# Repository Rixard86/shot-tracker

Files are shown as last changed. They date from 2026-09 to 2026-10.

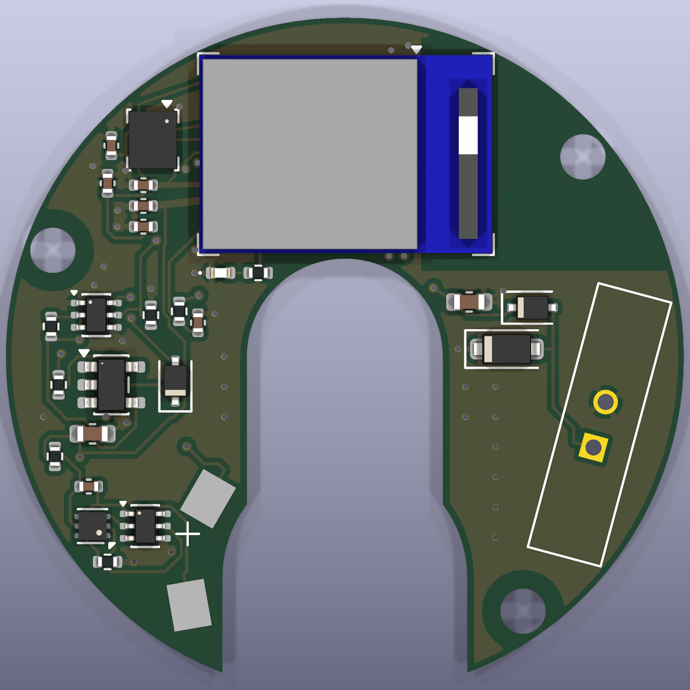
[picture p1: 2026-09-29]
hardware/kicad/shotpuck_pcb_top.png

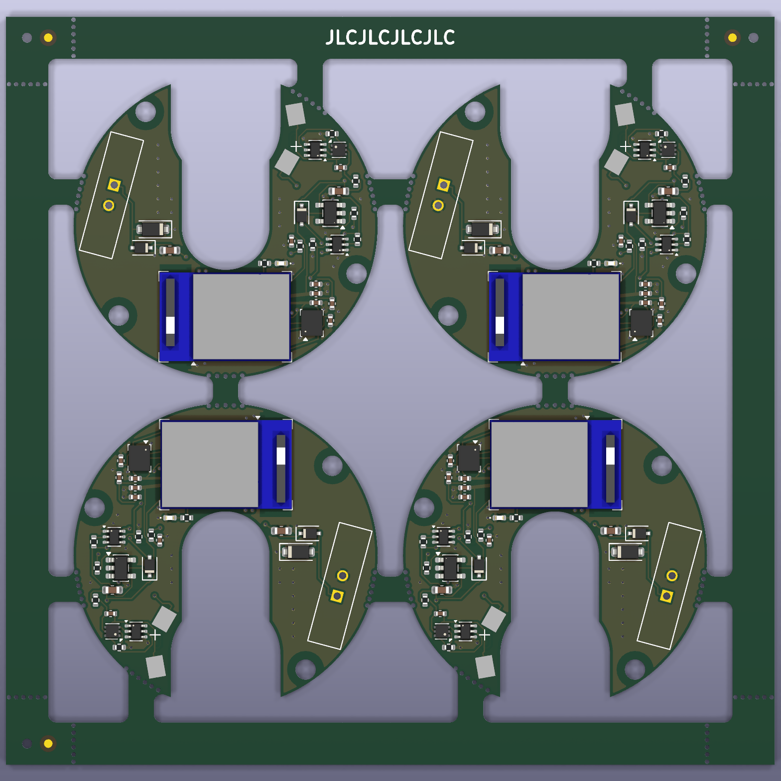
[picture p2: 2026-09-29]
hardware/kicad/panel/panel-top.png

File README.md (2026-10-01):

# ShotPuck: automatic arrow counter for Avalon barebow riser weights

A Ø40 × 10.4 mm puck that bolts onto the free face of an Avalon riser weight (the weight's own 5/16-24 bolt, one size longer, goes through its centre), detects each shot with a 6-axis IMU, records the bow's motion around it (accelerometer + gyroscope, 1.0 s before to 0.5 s after release), and reports both over BLE to the scoring app.

| | |
|---|---|
| Size / mass | Ø40 mm (= the Avalon barebow weight's diameter), 10.43 mm above the weight face (2.0 mm flat aluminium plate; the 1.2 mm PCB on 3 mm standoffs, the cell in a notch in the PCB), 16.7 g, centre of mass 0.5 mm off axis (no trim weight); 1.6 mm free space above the cell |
| Radio / MCU | u-blox BMD-340 (nRF52840, 1 MB flash / 256 KB RAM, PCB antenna), BLE 5 |
| Sensor | ST LSM6DSO32X IMU (LSM6DSO32 plus an unused machine-learning core): 416 Hz, ±32 g accelerometer + ±2000 dps gyroscope while active; accelerometer only, 12.5 Hz wake-on-motion, while idle |
| Battery | LIR1254 Li-ion coin, 45–65 mAh, plain (no tabs) on spring contacts, protected by TI BQ29700 + DMN2004DWK; charged through a waterproof (IPX8) side-entry USB-C port, power only (21 mA, temperature-gated) |
| Firmware | Zephyr 4.1, custom board `shotpuck/nrf52840`, MCUboot 28 KB + signed app 196 KB (452 KB slot) / 88 KB RAM (44 KB of it capture buffers) |
| Updates | Over the air: MCUboot with ECDSA-P256 signed images and automatic rollback, MCUmgr/SMP over BLE for paired phones, 10 s watchdog |
| Security / sync | Pairing required (LE Secure Connections); new phones only within 60 s of attaching the charger. Last ~900 shots kept in flash for replay. |

## Repository

```
layout.json                 shared geometry: CAD and PCB both read it
firmware/                   Zephyr app (src/, boards/shotpuck/, prj.conf, debug.conf)
firmware/sim/               Monte Carlo validation of src/shot_detect.c, unit tests of capture.c, evlog.c, chg_led.c and recovery.c (+ results.txt)
firmware/VERSION            firmware version (signed into the OTA image, shown in DIS and STATUS)
firmware/sysbuild.*         MCUboot + signing setup (refuses MCUboot's public dev key)
firmware/shotpuck_full.hex  MCUboot + signed app, for the first flash via the SWD test pads
firmware/shotpuck_update.bin  signed app image for OTA updates
hardware/design.py          the circuit (single source of truth)
hardware/gen_sch.py         -> kicad/shotpuck.kicad_sch
hardware/check_netlist.py   KiCad netlist vs design.py
hardware/gen_pcb.py         -> kicad/shotpuck.kicad_pcb (place, keep-outs, route, DRC)
hardware/board_shape.py     board outline, cell notch, bolt hole and antenna zone (shapely, from layout.json)
hardware/islands.py         post-fill GND island bridging used by gen_pcb.py
hardware/gen_bom.py         -> kicad/fab/shotpuck-bom.csv
hardware/gen_panel.py       -> kicad/panel/shotpuck-panel.kicad_pcb (2x2 KiKit panel for JLCPCB)
hardware/gen_jlc.py         -> kicad/fab/jlc/ (JLCPCB assembly BOM + CPL with LCSC part numbers, rotated/shifted to JLC's footprints)
hardware/bmd340.py          u-blox BMD-340 footprint, 3D model placement and schematic symbol (from its data sheet)
hardware/kicad/             KiCad project, ShotPuck.pretty/.kicad_sym/.3dshapes, schematic PDF, fab/ (gerbers, drill, pos, BOM)
mechanical/puck.py          CadQuery model + mass/balance -> out/ (STEP, STL, mass_report.txt);
                            geometry.py, puck_parts.py, puck_report.py hold its constants, parts and output
mechanical/plate_drawing.py plate manufacturing drawing (hole table, M2 thread callout) -> out/plate_drawing.pdf;
                            5052 sheet-metal prototype variant -> out/plate_drawing_5052.pdf + out/plate_5052.step
mechanical/blender/         Blender scene + exploded-view assembly animation -> out/shotpuck_assembly.mp4/.blend
docs/PROTOCOL.md            BLE GATT protocol for the app
docs/VALIDATION.md          what is proven, and the on-device checklist
order/                      order packages for JLC (PCB + assembly, plate, cap), each with an ORDER.md:
                            form settings, notes for the order and the checks against JLC's rules
```

## Decisions (change any, then re-run the generators)

| # | Decision | Why | Alternative |
|---|---|---|---|
| D1 | **Cell beside the module, no trim weight** | Module at the upper right, bolt in the middle, cell in a notch at the bottom. The centre of mass is 0.5 mm off axis (≈ 0.01 mm on a 2 kg bow); Richard dropped the optional brass pin when the PCB went up on standoffs | Two LIR1254 side by side (studied: they cut the board in two); a brass trim pin |
| D2 | **Flat 6061 plate (2.0 mm) + polycarbonate cap, bolted on through a steel sleeve** | Richard: the v0.2 stud could not be fitted to the bow (it needs a bolt from above), and a flat plate is cheaper (laser or waterjet, no turning). The sleeve carries the bolt's clamp load to the plate; on the prototype the PC cap top sits between the bolt's washer and the sleeve (D21) | Turned 7075 base with an integral stud (v0.2) |
| D3 | **nRF52840 in high-voltage mode** (cell → VDDH, REG0 = 3.0 V) | No regulator, no battery divider (internal VDDH/5), fewer leaks | External LDO |
| D4 | **MCP73831 + firmware temperature gate** (nRF die temperature, <1 °C / >44 °C) | MCP73831 programs down to 15 mA; the TS-pin chargers found start at 100 mA. Default is *charging allowed* if the MCU is dead, so a flat cell always recovers. | Charger with an NTC input and a thermistor at the cell |
| D5 | **32 kHz from internal RC, REG0/REG1 in LDO mode** | The BMD-340 has no 32.768 kHz crystal; LDO is the tested default | Enable DC/DC on REG0/REG1 (the BMD-340 has the inductors; about half the radio current) |
| D6 | **Plain LIR1254 (no tabs) on contacts:** a + spring against the can side and a − strap over the top cap, soldered to two SMD pads left of the notch; the cap's foam pad clamps the cell and the strap | Richard's choice: no tab variant to source, no soldering on the cell, swappable | Tabbed LIR1254 soldered to pads; 601015 pouch (closed-ring board, ~9.9 mm) |
| D7 | **Pairing required; new pairings only within 60 s of attaching the charger** (LE Secure Connections Just Works, up to 4 phones, FORGET_BONDS to reset) | Several pucks and shooters at one club: other apps must not read, reconfigure or reset your puck. The charger gesture proves physical possession. | Open access (v1), or a PIN shown by LED blinks |
| D8 | **Detector thresholds are defaults, tunable over BLE**; every candidate is reported | Real release-shock data is unknown until you shoot | – |
| D9 | IMU rotated 270°, reference designators on F.Fab only | Routability; board too dense for silkscreen text | – |
| D10 | **LSM6DSO32 IMU** replaces the LIS2DE12 accelerometer. Pinout, pin states and register values checked against datasheet DocID032891 Rev 1; I3C disabled at init as the datasheet recommends. Since 2026-09-30 the BOM fits the **LSM6DSO32XTR** (C3663738) for JLC stock: the same chip plus a machine-learning core we leave off, same package, pinout, WHO_AM_I and registers, and a pad-for-pad identical JLC footprint, so the board and firmware are unchanged | Gyroscope for bow rotation; ±32 g clips the release shock less; 16-bit data; same I2C bus and INT1 pin | LSM6DSV16X/32X (on-chip sensor fusion, ±4000 dps) |
| D11 | **Raw 6-axis capture per accepted shot** (−1.0 s to +0.5 s, 624 samples, 7.5 KB), analysed in the app | Which bow-movement metrics matter is unknown until real shots are recorded | On-device metrics (cant, steadiness, post-release rotation) in the EVENT |
| D12 | **Identity from the chip's factory ID**: name `ShotPuck-XXXX`, DIS serial number = `device_id` | Tell pucks apart at a club; one stable ID across phones for PowerSync | App-assigned IDs |
| D13 | **Accepted shots in a 32 KB flash ring** (~900 shots), rejected candidates in RAM; app-driven REPLAY, sent paced in the background | Shots survive dropouts and resets without per-phone sync state on the puck | Device push with ACK (rejected: shared state, first phone drains the backlog); captures in flash too |
| D14 | **u-blox BMD-340-A-R (nRF52840) instead of the Raytac MDBT50Q-1MV2**: 15.0 × 10.2 × 1.9 mm LGA-68, PCB antenna, VCCH input for high-voltage mode, FCC/CE/Bluetooth certified. Footprint `ShotPuck:u-blox_BMD-340` from data sheet UBX-19033353 (Figure 12), checked pad for pad against two built open-source footprints | Richard: replace parts JLCPCB does not stock. On 2026-09-29 JLCPCB had 0 MDBT50Q-1MV2 and 227–393 BMD-340 (C5456944, $8.73 vs $18.93). nRF52840 kept for the two OTA slots (2 × 460 KB). **Only type BMD-340-A-R-10 is usable:** -00 (nRF52840 rev 1) has a non-functional high-voltage mode, so confirm the type with JLCPCB before ordering | MDBT50Q-1MV2 via global sourcing or consignment; u-blox NINA-B306 ($20, 59 in stock) |
| D16 | **Cell protection (PCM): TI BQ29700 + Diodes DMN2004DWK** in the cell's negative lead (OVP 4.275 V, UVP 2.80 V, ±0.1 A over-current, short-circuit) | LIR cells have no protection of their own; kept from the CP1654 design (BQ29700 was on Varta's list). Costs 4 µA standby | – |
| D17 | **1.6 mm free space above the cell** (7.0 mm from the Kapton to the ceiling) | No swell spec for LIR cells. It was 1.2 mm (set on the magnetic board so its connector was flush with the cap top, D25) until the PCB went to 1.2 mm (D30): the ceiling rose 0.4 mm with the board, so the free space is now above Varta's 1.5 mm. The foam pad fills it | 1.2 mm with 2.6 mm standoffs (non-stock) |
| D19 | **Board Ø36 mm; 4× M2×8 cheese head (Torx) screws from above, all at r = 16.5 mm: H1 100.6°, H2 164.5°, H3 305°, H4 226°**, through the cap, PCB and standoffs into the tapped plate | Puck Ø40 mm is fixed by the Avalon weight; 36 leaves 0.5 mm fit clearance. The screws sit clear of the module, the cell notch and the port. H1 and H2 sit either side of the USB-C port, far enough apart that the ground pour reaches J1's wing tabs; H4 holds the left arm (D29). The 1.3 mm head lets an M2×8 end 0.1 mm inside the plate (a socket head would need the non-standard M2×7) | – |
| D20 | **Cell in a notch in the PCB, open to the rim** (Ø13.0 mm round end), on the Kapton over the plate | Saves the 0.8 mm board in height. Richard preferred the notch to a closed hole | Closed hole (holds the cell all round, leaves a thin strip at the rim) |
| D18 | **Waterproof (IPX8) side-entry USB-C, SHOU HAN TYPE-C 6PFS 2JCB1.6-H6.7 IPX8** (6-pin, power only, LCSC C3020041, JLC-assembled) at 132.58° on the left rim, recessed in a notch in the board edge, plug axis radial through the cap wall; R10/R11 5.1k pull CC1/CC2 down | Richard (2026-09-30). Any USB-C charger and cable fits, JLC places the part (the magnetic one was hand-soldered), and its own silicone ring seals it in the cap wall. The CC pull-downs make USB-C chargers switch on 5 V | Samzo PR5L4015 magnetic receptacle flush with the cap top (the magnetic board, last at commit `01f2e00`) |
| D15 | **OTA = MCUboot swap-using-move + MCUmgr SMP over BLE**, ECDSA-P256 signed, encrypted link (paired phones) only. A new image runs on trial and confirms itself once a paired phone has connected over an encrypted link and it has run 10 s (so an image that runs but cannot talk BLE rolls back); a 10 s hardware watchdog turns a hang into a reset, and MCUboot then rolls back | Standard Nordic/Zephyr path; the Flutter app can use Nordic's `mcumgr_flutter` | Firmware-loader mode (single slot); no rollback |
| D21 | **One loose steel tube from the plate through the PCB to the underside of the cap top, located by a lip under the cap** (Richard, prototype) carries the bolt load from the cap top to the plate; the PCB hole (Ø10.4: 0.2 mm clearance covers JLCPCB's ±0.2 mm outline tolerance) is merged into the cell notch | Richard: the tube must not get lost while the puck is off the bow. Bonded into the cap and standing 0.1 mm proud, it was held by 1.2 mm of glue that the stack tolerance between cap and plate (±0.15–0.3 mm) and the bolt's squeeze would break at the first bolt-up, and then it could slide out through the top. Trapped between the plate and the cap it cannot fall out and needs no glue. **Known risk, tested on the prototype:** the bolt clamps the 1.33 mm PC cap top onto the tube end. At 3 N·m (~2 kN) that is 80–110 MPa on the tube end, at PC's compressive yield, so the cap top may creep and the bolt lose preload (VALIDATION §2). Everything right of the merged hole is copper-free (D22), so no signal has to cross it. No stock insulating tube fits (glass-epoxy 10 × 8 mm grips a 5/16 bolt, plastics creep), so it is steel, with Kapton tape all round it because it can turn | Tube bonded into the cap, 0.1 mm proud (glue breaks, tube can fall out); turned sleeve with a collar in a recess under the cap top (steel-only clamp path, custom part); tube bonded into the plate; sleeve on the PCB with a spacer below (PCB in the clamp path) |
| D22 | **On-board PCB antenna** (BMD-340), module at the upper right with its antenna end pointing 45° below +x; the antenna zone (from 4.4 mm inside the module's end) and everything right of the tube are copper-free (`board_shape.rf_keepout`) | Richard's choice over moving the antenna out into the cap. The module slid 45° around the tube so the USB-C port fits on the left | Module with a u.FL connector and an antenna in the cap |
| D23 | **SWD on 4 bottom test pads** (VDD, SWDIO, SWDCLK, GND, 2.54 mm pitch, under the module) for a pogo-pin jig | Frees top-side space for 2-layer routing; the SWD escape vias are pre-placed | Tag-Connect TC2030-CTX-NL (v0.2) |
| D24 | **I2C on internal pull-ups only; SCL = P0.07, SDA = P0.05** (BMD-340 pads 23 and 21, facing the IMU) | The 4.7k DNP pads (R5/R6) were never fitted and cost routing space; the swap stops the IMU lines crossing on 2 layers | Keep R5/R6 as DNP pads for a stronger pull-up |
| D25 | **PCB on 3 mm standoffs; puck 10.43 mm** | Set on the magnetic board so its connector sat flush with the cap top, and kept. The cap top went from 1.2 to 1.33 mm (2026-09-30, Richard) so 0.80 mm of it is left over the USB-C body, JLC3DP's minimum SLA wall for a ~10 mm feature. The cell sets the ceiling, so the raised board costs no height, and it keeps the antenna 3 mm further from the plate | Board on the plate |
| D26 | **Button head bolt** (5/16-24, head Ø16.7 × 4.4 mm) with a bonded sealing washer | Richard: lower head than a socket head (7.9 mm). The washer clamps the PC cap top onto the sleeve (D21) | Socket head cap screw |
| D27 | **Charge-input protection: SMF5.0CA bidirectional TVS (D3) at the connector + R9 1k / C9 100n in front of the nRF VBUS pin** | The port is exposed (ESD) and plugging in makes and breaks contact (hot-plug spikes); the TVS is bidirectional and sits before D1. The SMF5.0CA starts clamping at 6.4–7.0 V (200 W) against the MCP73831's 7 V absolute maximum. No 5 V TVS can hold the nRF52840 VBUS pin under its 5.8 V absolute maximum; it is used only to detect the charger (~24 µA), so the RC limits current into it and smooths spikes | PESD5V0S1BB (a signal-line ESD diode, clamps only from 5.5–9.5 V); unidirectional flat-clamp TVS after D1 (TI TVS0500); an overvoltage switch (needed only if 9–12 V adapters are a risk) |
| D28 | **Routing aids for 2 layers (BMD-340):** module pins chosen so its second pad column escapes through the outer column's gaps towards the IMU; links and vias locked before Freerouting (`PRE_LINKS`, `PAD_BRIDGES`, `PRE_VIAS` rotated with the module, `PRE_ROUTED` in `gen_pcb.py`) | The LGA module's inner pads need planned escapes. Everything right of the tube is copper-free (D22), so no VIN loop or passage is needed (`VIN_ESCAPE = None`). The board routes with 0 DRC / 0 unconnected; J1's notch and a few fixes are hand edits (Build & flash) | 4 layers |
| D29 | **Shot shock: 4th screw H4 on the left arm; BMD-340 and C2 corner-staked** (Richard) | The slot for the cell and the tube makes the board a horseshoe. Its left arm (PCM, both cell contact pads) had no screw below H2. The model below is of the magnetic board (H1 then at (9.2, 1.2)) and was not re-run for the USB-C layout, whose board is also clamped through rubber O-rings. A plate model of the board (Kirchhoff plate FE, 100 g along the puck axis, component masses, module 1–5× stiffer than the board) gives, at 0.8 mm: first mode 1.1–1.2 kHz → 1.7–2.0 kHz; worst strain 320–340 → 160–180 µε (bare board next to a screw; ≤ 70 µε at any part); the − cell pad moved 13–15 µm against the cell per 100 g, now ~0. At 1.2 mm with 4 screws (the board now, D30): 2.7–3.2 kHz, ~100 µε | Foam pad under the board (damping, no layout change); thicker PCB alone (1.2 mm, 3 screws: 1.7–1.8 kHz) |
| D30 | **PCB 1.2 mm** (was 0.8), stock 3 mm standoffs, puck 0.4 mm taller (10.43 mm) | Richard (2026-09-30): a stiffer board under shot shock (D29: first mode 1.7–2.0 → 2.7–3.2 kHz, strain about halved). Everything on the board rose 0.4 mm, so the cell ceiling (`cell.swell_h` 6.6 → 7.0) and the cap rose with it and every cap, lip and port clearance is unchanged; the tube is 7.1 mm | 0.8 mm board (puck 10.03 mm); 1.2 mm on 2.6 mm standoffs (non-stock) to keep 10.03 mm |

## Needs your input before ordering

1. **USB-C port:** JLC-assembled (C3020041, D18); charge with any 5 V USB-C charger and cable. Ask JLC to confirm the part is in stock for the order.
2. **LIR1254:** buy a plain cell (no tabs) from a maker with a datasheet. Check its charge voltage (ours 4.20 V) and that 21 mA (R1 = 47k) is within its standard charge current (usually 0.5 C).
3. **Cell contacts:** not a bought part yet. For prototypes, form the + spring and the − strap from 0.15 × 2 mm nickel strip (as in the animation) and put Kapton tape where the strap passes the can edge.
4. **Bolt:** a 5/16-24 button head socket cap screw, longer than the original Avalon bolt by the puck height plus the sealing washer (about 12 mm). Check that length is sold in 5/16-24 and the thread engagement in the riser; don't over-tighten (3/16 in hex).
5. **Component masses:** weigh the real parts, put them in `layout.json`, and re-run `puck.py` for the mass report.
6. **Back up the OTA signing key** `%USERPROFILE%\.shotpuck\ota-signing-key.pem` (password manager or offline copy). Pucks accept only images signed with it: if it is lost, updates need a cable (SWD); if it leaks, anyone who can pair could install their firmware. It is never committed (`*.pem` is git-ignored).
7. **Module type:** before ordering, ask JLCPCB support to confirm that their BMD-340-A-R stock (C5456944) is type **BMD-340-A-R-10**. Types -00 and -01 are obsolete, and -00's nRF52840 rev 1 silicon makes high-voltage mode unusable (D14).
8. **O-rings:** buy 36, 37 and 38 × 1.0 mm (VMQ or NBR, 70 Shore A) for the cap seal and 2 × 1.0 mm for the four screws; fit them on the first SLA cap (resin shrink moves the ledge) and tune `seal.ledge_od`/`squeeze` in `layout.json`.

## Simulation results (`firmware/sim/results.txt`, seed 2026)

| Set | Shots | Recall | Precision | Notes |
|---|---|---|---|---|
| Nominal sessions | 437 | 99.1 % | 99.8 % | walking knocks, set-downs, stand knocks, nock taps, drops, let-downs (1 FP: stand knock) |
| Hard cases | 479 | 99.6 % | 99.4 % | + taps while aiming, hard grabs off the stand (2 grabs, 1 stand knock) |
| Weak bow (info) | 253 | 80.2 % | 99.5 % | 4–12 g shock, 5–30° rotation: **thresholds must be tuned on real shots** |

The detector needs three things together: a high-frequency shock (6 g sample-to-sample), ≥ 0.5 s of stillness before it (aiming), and ≥ 250 mg of low-frequency bow motion 0.1–0.6 s after it (bow jump into the sling). See `firmware/src/shot_detect.h`. It uses the accelerometer only; the gyroscope feeds the capture.

## Battery life (estimate, verify via JP1)

The idle draw is roughly 17 µA (LSM6DSO32 accelerometer in low-power mode at 12.5 Hz, about 10 µA by interpolating the datasheet's 4.5 µA at 1.6 Hz and 26 µA at 52 Hz; BQ29700 protection 4 µA; nRF System ON + RC). While active it is roughly 0.7–0.8 mA: the gyroscope alone is about 0.55 mA, plus 416 Hz FIFO reads and the BLE link. At **2 h of training per day** that is ≈ 1.9 mAh/day, so roughly **3.5–5 weeks per charge** from a 45–65 mAh LIR1254 (a little less, as the 3.3 V cut-off leaves some capacity unused). A full charge at 21 mA takes about 2.5–3.5 h. The low-battery cut-off (3.3 V) puts the puck into System OFF until the charger is attached.

## Build & flash

Native Windows toolchain (what v0.2 was built and verified with):

| Tool | Where | Used for |
|---|---|---|
| KiCad 10.0 | `C:\Program Files\KiCad\10.0` (its `python.exe` has `pcbnew`) | schematic, PCB, ERC, DRC, fab exports |
| Freerouting 2.1.0 + Java 21 | `%USERPROFILE%\tools\freerouting-2.1.0.jar`, `%USERPROFILE%\tools\jre21` (or set `FREEROUTING_JAR`, `JAVA`) | PCB routing |
| Zephyr v4.1.0 workspace + SDK 0.17.0 | `C:\zp` (west, modules `cmsis`, `cmsis_6`, `hal_nordic`, `segger`, `hal_st`, `mbedtls` for pairing crypto, `mcuboot` + `zcbor` for OTA) | firmware |
| CMake 3.31 + Ninja | `%USERPROFILE%\tools\cmake3`, `%USERPROFILE%\tools\ninja` (Zephyr 4.1 fails with CMake 4.x) | firmware |
| w64devkit gcc | `%USERPROFILE%\tools\w64devkit` (set `CC` to its `gcc.exe`) | simulation, capture tests |

**Firmware** (Zephyr 4.1 sysbuild: MCUboot + signed app in one build):

```
set ZEPHYR_BASE=C:\zp\zephyr
set ZEPHYR_SDK_INSTALL_DIR=C:\zp\zephyr-sdk-0.17.0
set PATH=%USERPROFILE%\tools\cmake3\bin;%USERPROFILE%\tools\ninja;C:\zp\.venv\Scripts;%PATH%
cd C:\zp
west build --sysbuild -p always -b shotpuck/nrf52840 <repo>/firmware -d build\sb -- ^
  -DBOARD_ROOT=<repo>/firmware ^
  -DSB_CONFIG_BOOT_SIGNATURE_KEY_FILE=\"C:/Users/<you>/.shotpuck/ota-signing-key.pem\"
python zephyr\scripts\build\mergehex.py -o shotpuck_full.hex build\sb\mcuboot\zephyr\zephyr.hex build\sb\firmware\zephyr\zephyr.signed.hex
```

- The key path needs the escaped quotes (Kconfig string). Without the private key the build stops on purpose instead of signing with MCUboot's public dev key.
- **First flash** (bootloader + app) by cable: `shotpuck_full.hex` with J-Link/nrfjprog through the 4 SWD test pads on the bottom (VDD, SWDIO, SWDCLK, GND at 2.54 mm; pogo-pin jig or pogo probes), before the board goes onto the plate.
- **Updates over the air:** `build\sb\firmware\zephyr\zephyr.signed.bin` (copied to `firmware/shotpuck_update.bin`), sent from a paired phone (your app with `mcumgr_flutter`, or Nordic's nRF Connect Device Manager). Bump `firmware/VERSION` for every release.
- RTT logging build: add `-DEXTRA_CONF_FILE=debug.conf`. It fits the slot and can be installed over the air too.
- The first boot programs UICR REGOUT0 = 3.0 V and resets once.
- Generate a new signing key only for a new product line: `python C:\zp\bootloader\mcuboot\scripts\imgtool.py keygen -k ota-signing-key.pem -t ecdsa-p256`. Pucks flashed with one key never accept images signed with another.

**Simulation + unit tests:** `set CC=%USERPROFILE%\tools\w64devkit\bin\gcc.exe` then `python firmware/sim/simulate.py --sessions 36 --stress --seed 2026` (needs numpy, scipy). Must print `CAPTURE TESTS: PASS`, `EVLOG TESTS: PASS`, `CHG LED TESTS: PASS`, `RECOVERY TESTS: PASS` and `RESULT: PASS`.

**Hardware** (run with KiCad 10's Python, from `hardware/`):

```
"C:\Program Files\KiCad\10.0\bin\python.exe" gen_sch.py
"C:\Program Files\KiCad\10.0\bin\python.exe" check_netlist.py      # must print PASS
kicad-cli sch erc --severity-all -o kicad\erc.rpt kicad\shotpuck.kicad_sch
"C:\Program Files\KiCad\10.0\bin\python.exe" gen_pcb.py --no-route  # placement only, then DRC
"C:\Program Files\KiCad\10.0\bin\python.exe" global_route.py       # routability estimate: overflow + hotspots
"C:\Program Files\KiCad\10.0\bin\python.exe" gen_pcb.py --quick     # one-attempt trial route (~5 min)
"C:\Program Files\KiCad\10.0\bin\python.exe" gen_pcb.py            # place, route, bridge GND islands, DRC
"C:\Program Files\KiCad\10.0\bin\python.exe" gen_bom.py
kicad-cli pcb export gerbers -o kicad\fab\gerbers -l F.Cu,B.Cu,F.Paste,B.Paste,F.Silkscreen,B.Silkscreen,F.Mask,B.Mask,Edge.Cuts --subtract-soldermask kicad\shotpuck.kicad_pcb
kicad-cli pcb export drill -o kicad\fab\gerbers --excellon-separate-th --generate-map --map-format gerberx2 kicad\shotpuck.kicad_pcb
kicad-cli pcb export pos --format csv --units mm --side both -o kicad\fab\shotpuck-pos.csv kicad\shotpuck.kicad_pcb
```

Zip `kicad\fab\gerbers\` into `kicad\fab\shotpuck-gerbers.zip`. The single board is for reference: JLCPCB gets the panel (below). The pos file is in KiCad page coordinates, with the bolt axis at (132.064, 91.396) and Y negated. Don't set a drill/place origin to change that: it breaks KiKit's panel frame (HANDOVER §7).

Freerouting routes the signals only (GND comes from the pours, fan-out and stitching vias) and is not deterministic. `gen_pcb.py` re-routes up to 4 times until nothing is unconnected; if it still does not end with `0 DRC violations` and `0 unconnected pads`, run it again. ERC: 0 errors; the 2 warnings are the intentional straps of LSM6DSO32 SA0 and SDx to GND.

**Hand edits:** `gen_pcb.py` does not draw J1's board-edge notch (10.28 × 5.22 mm with two Ø0.70 NPTH leg holes), and the GND via at (−0.41, 16.09), the JP2 reset pads and the silkscreen text were added by hand in KiCad; U2, C3, C6 and C7 were moved inward by hand, away from the top panel tab. Re-running `gen_pcb.py` overwrites the board without them, so back it up and redo them (HANDOVER §6).

**Mechanical:** `C:\zp\.cq\Scripts\python.exe mechanical/puck.py` (CadQuery 2.8 in a Python 3.12 venv; CadQuery has no Python 3.14 wheels). It writes the mass and balance report; there is no trim weight. `C:\zp\.cq\Scripts\python.exe mechanical/plate_drawing.py` writes the plate drawing (`out/plate_drawing.pdf`) from the same `layout.json`, and the cheaper prototype variant in 5052 sheet (`out/plate_drawing_5052.pdf` + `out/plate_5052.step`, no chamfer).

**Assembly animation (Blender 3.1+):** `"C:\Program Files\Blender Foundation\Blender 3.1\blender.exe" -b -P mechanical/blender/render_assembly.py` (after `puck.py`; it exports the populated board from KiCad as GLB itself). It renders an exploded view that assembles into the puck (Cycles on the GPU, 1080p, 13 s) to `mechanical/out/frames/` and encodes `mechanical/out/shotpuck_assembly.mp4`; the scene is saved as `shotpuck_assembly.blend`. Add `-- --preview` for 5 half-size stills, `-- --encode` to re-encode existing frames. Existing frames are skipped, so an interrupted render resumes; when `layout.json`, the STLs, the board, its 3D models or the Blender scripts have changed since the frames were made (`frames/scene.sha256`), they are deleted first. The cell and its contacts, standoffs, M2 screws, button head bolt and sealing washer, the seal and clamp O-rings, Kapton and foam are modelled from `layout.json`; the board parts, including the USB-C port, use KiCad's 3D models.

**Panel + JLCPCB assembly files** (after `gen_pcb.py`, with KiCad 10's Python and KiKit: `python.exe -m pip install --user kikit`):

```
"C:\Program Files\KiCad\10.0\bin\python.exe" gen_panel.py      # 2x2 in a frame, 4 tabs per board, mouse bites, fiducials, tooling holes
"C:\Program Files\KiCad\10.0\bin\python.exe" gen_jlc.py        # kicad/fab/jlc/shotpuck-panel-bom.csv + -cpl.csv
kicad-cli pcb export gerbers -o kicad\fab\panel\gerbers -l F.Cu,B.Cu,F.Paste,B.Paste,F.Silkscreen,B.Silkscreen,F.Mask,B.Mask,Edge.Cuts --subtract-soldermask kicad\panel\shotpuck-panel.kicad_pcb
kicad-cli pcb export drill -o kicad\fab\panel\gerbers --excellon-separate-th --generate-map --map-format gerberx2 kicad\panel\shotpuck-panel.kicad_pcb
```

Zip `kicad\fab\panel\gerbers\` into `shotpuck-panel-gerbers.zip`. The drill is split into `-PTH.drl` (vias) and `-NPTH.drl` (mouse bites, J1 legs, tooling, screw holes), as JLCPCB asks. Each comes with a `-drl_map.gbr` drill map, which JLC's KiCad guide asks for. Do not refill the zones on export: the panel's saved fill is the one DRC checked. `gen_jlc.py` rotates and shifts U1 (BMD-340, +2.0 mm to its pad-array centre), U3, Q1, Q2 (+270°), D4 (+180°, JLC's pad 1 is its cathode on the other side), D3 (+180°, JLC numbers its pads the other way; the TVS is bidirectional, so this only fixes the preview) and J1 (0.15 mm) so JLC's own footprints land on ours; this was checked pad by pad against the EasyEDA footprints of the LCSC parts.

## Fabrication & assembly

The last order package is `order/shotpuck-order-2026-09-30/` (USB-C board, 1.2 mm PCB): upload its files and follow its `ORDER.md` for the JLC form settings, the notes to add to each order and the risks to check on the first boards.

- **PCB:** 2 layers, 1.2 mm FR-4, ENIG, Ø36 mm (0.5 mm clearance per side in the Ø37 mm cap cavity; puck Ø40 mm = the Avalon weight) with a notch for the cell (Ø13.0 mm round end, open to the rim) merged with a Ø10.4 mm hole for the bolt tube and a 10.28 × 5.22 mm notch for the USB-C port (all part of the outline), 0.15 mm track / 0.127 mm space, vias 0.55 mm pad / 0.3 mm hole (standard at JLCPCB/PCBWay, no small-hole surcharge).
- **JLCPCB order (prototype):** upload `kicad/fab/panel/shotpuck-panel-gerbers.zip` as a 2×2 panel ("panel by customer", 4 boards per panel, 91.1 × 92.7 mm; the top row is turned 180° and a backbone runs between the rows, so the tabs miss the cell notch), order 5 panels = 20 boards, 1.2 mm, ENIG. For assembly (top side), upload `kicad/fab/jlc/shotpuck-panel-bom.csv` and `-cpl.csv` (rotations and centroids already corrected for JLC's footprints) and confirm the placement preview, J1 included. Not assembled by JLCPCB: the cell BT1 and its contacts, JP1 (bridged solder jumper, copper only), JP2 (reset pads, copper only), J2 (SWD test pads). The module needs JLCPCB's X-ray inspection. Cut the tabs with flush cutters instead of snapping them (parts sit a few mm from the tabs, and bending there can crack joints or the 0603 capacitor C2), then sand the nubs flush. The BQ29700 may start with its discharge FET off when a cell is first fitted (TI SLUSBU9I §8.4.1): attach the charger once to wake it.
- **Plate:** 6061-T6, 2.0 mm, laser or waterjet cut: Ø8.4 mm centre hole, 4× M2×0.4 tapped through (tap drill Ø1.6) at H1–H4, r = 16.5 mm (`bosses.positions` in `layout.json`). Send `mechanical/out/plate.step` with `plate_drawing.pdf`: the STEP shows the M2 holes as plain Ø1.6 holes, and the drawing calls out the threads. Anodising is optional (mask the threads). JLCCNC makes 6061 only by CNC machining; for prototypes the cheaper route is their sheet-metal service in 5052 (the only aluminium it stocks): `out/plate_5052.step` + `plate_drawing_5052.pdf`, laser cut, same holes, no chamfer.
- **Cap:** polycarbonate, CNC-machined (translucent so the LED shows); for prototypes, clear SLA resin (`mechanical/out/cap.step`). It has the M2 counterbores, bosses that stop 0.65 mm above the PCB, the Ø8.4 bolt hole, the tube lip (a ring under the cap top: Ø10.2 inside, 0.8 mm wall, 0.6 mm deep, 0.3 mm above the module), a stepped wall with a Ø37.8 ledge for the seal O-ring, and the USB-C port: an obround hole in the wall where the connector's silicone ring seals (0.15 mm squeeze per side), a pocket over its body (0.80 mm of cap top left) and a flat at the receptacle face so any USB-C plug seats fully. **No liquid threadlocker anywhere near PC** (it causes stress cracking): use nylon-patch screws.
- **Tube:** cold-drawn 304 stainless tube Ø10 × 0.8 mm (yield ≥ 500 MPa; annealed tube would yield when the bolt is over-tightened), 7.1 mm long (plate to the underside of the cap top), loose: the plate and the cap's lip trap it. Kapton tape all round it from the plate to the cell top (it can turn); the lip needs the bare tube.
- **Standoffs:** 4 M2 round aluminium spacers, 3 mm long (stock length), OD 4 mm, ID 2.2–2.4 mm, at the screws.
- **Seals:** O-ring 37 × 1.0 mm (VMQ or NBR, 70 Shore A) on the cap's ledge, squeezed 25 % against the plate; an O-ring 2 × 1.0 mm on each M2 screw under its boss clamps the PCB and keeps the screw captive. **Kapton:** 0.1 mm disc with holes for the tube (Ø10.4) and the 4 screws; it insulates the cell's + can from the plate.
- **Assembly order:**
  1. Program the board through the SWD pads on its underside.
  2. Hand-solder the two cell contacts (+ spring, − strap). Corner-stake the BMD-340 (a small fillet of edge-bond epoxy at each of its 4 corners, board to module edge, clear of the antenna end's top) and the 0603 C2 (a dot at each end); cure as the adhesive's datasheet says. **No adhesive on or next to the IMU U2**: package stress shifts its offset.
  3. Lay the Kapton disc on the plate. Set the 4 standoffs over the screw holes. Put the cell on the Kapton, + can down, then lower the PCB onto the spacers so the cell sits in the notch and the + spring presses on the can side. Fold the − strap over the top cap and put the foam pad on it.
  4. Stand the Kapton-taped tube on the plate through the PCB hole. Stretch the 37 × 1.0 O-ring onto the cap's ledge, push the 4 M2×8 cheese head screws (nylon patch) down through the cap and put a 2 × 1.0 O-ring on each below its boss. Lower cap, screws and O-rings as one unit, so the tube's top end goes into the lip and the port's silicone ring into its hole in the wall, and tighten until the cap's inner band seats on the plate. If the tube holds the cap up, face the tube shorter.
  5. On the bow: the button head bolt, with a bonded sealing washer under its head, goes through the cap top, the sleeve and the weight into the riser.
- **Programming:** SWD only (no reset pin), which is fine for the nRF52.

## Validation

See **docs/VALIDATION.md**. The blockers:

- Standby current.
- Charging current and termination voltage.
- Cold charge inhibit.
- VBUS wake from System OFF.
- BLE range through the cap.
- **Threshold tuning from logged real shots.**
- IMU axis orientation and a complete capture transfer to the app.
- Pairing on iOS and Android through the charger window, and REPLAY from the flash log after a reset.

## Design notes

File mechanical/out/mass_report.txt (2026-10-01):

ShotPuck mass & balance report (generated by puck.py)

Overall: OD 40.0 mm, height above the weight face 10.43 mm (2.0 mm flat plate); 5/16-24 UNF bolt through the D10 mm sleeve
PCB on 3.0 mm standoffs; cell on the Kapton in the PCB notch: 7.00 mm to the ceiling (cell 5.4 mm + 1.6 mm free)
USB-C port: 0.80 mm of cap top left over the connector; plug flat 9.0 mm wide (overmold max 12.35 mm)

part                     mass g       x       y       z
plate (6061)               6.43    0.04    0.01    1.00
standoffs (Al)             0.28   -5.23   -1.19    3.60
pcb (FR4)                  1.56    0.89    1.79    5.70
sleeve (steel)             1.30   -0.00   -0.00    5.55
cell LIR1254               1.90   -0.00  -11.75    4.80
module BMD-340             0.60    7.78    7.78    7.25
USB-C connector            0.80  -10.89   11.85    7.10
other SMD parts            0.60    0.00    0.00    6.80
cap (PC)                   3.25    0.42   -0.54    8.04

Total mass: 16.72 g
Centre of mass: x=-0.152 y=-0.445 z=4.36 mm -> 0.470 mm off axis (7.87 g*mm)

Component masses are datasheet/estimated values from layout.json. Weigh the real parts and re-run.

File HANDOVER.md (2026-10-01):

# HANDOVER: ShotPuck (for the next agent)

Read this first, then `README.md`. Everything below is the state as of 2026-09-30 (rev A with the USB-C side port: flat plate, centre bolt, LIR1254).

## 1. What this is

ShotPuck is a Ø40 × 10.43 mm BLE puck bolted onto the free face of an **Avalon barebow riser weight**: the weight's own 5/16-24 bolt, one size longer, goes through a sleeve in the puck's centre. It counts arrow shots and records the bow's motion around each shot, and reports both to the user's own **Flutter/PowerSync archery scoring app**.

- MCU: u-blox BMD-340-A-R-10 (nRF52840, 1 MB flash / 256 KB RAM, PCB antenna). Until 2026-09-29 the board used the Raytac MDBT50Q-1MV2, swapped because JLCPCB had none in stock (README D14).
- IMU: **ST LSM6DSO32** (accelerometer ±32 g + gyroscope ±2000 dps). v0.1 used a LIS2DE12 accelerometer. Since 2026-09-30 the BOM fits the **LSM6DSO32XTR** (C3663738, for JLC stock): the same chip plus a machine-learning core we leave off, with the same package, pinout, WHO_AM_I (0x6C) and registers, and a pad-for-pad identical JLC footprint.
- Cell: LIR1254 Li-ion coin (plain, no tabs, on spring contacts). v0.2 used a Varta CP1654.
- Charger: MCP73831, via a waterproof (IPX8) side-entry USB-C port, power only.

Deliverable status: **rev A design package complete and verified off-device. No hardware has been built yet.**

v0.2 changes from v0.1: LSM6DSO32 IMU (U2, plus C7 for VDDIO), raw 6-axis capture per accepted shot streamed over a new CAPTURE characteristic, **pairing required** with new phones accepted only while the charger is attached, unique identity (`ShotPuck-XXXX` + DIS serial), accepted shots kept in a flash log with a paced background REPLAY (all protocol v2), **OTA updates** (MCUboot + MCUmgr SMP over BLE, signed images, rollback, watchdog) on the **nRF52840 module**, and the whole toolchain moved to **native Windows** (KiCad 10, Zephyr on Windows).

Prototype-order round (2026-09-27): Varta-required **cell protection** (BQ29700 + DMN2004DWK), **universal cell pads** (plated holes), puck **1.3 mm taller** for Varta's 1.5 mm swell space, real **magnetic connector** (Samzo PR5L4015 from Electrokit) with a cap chimney, **0.3 mm via holes**, a **2×2 KiKit panel** and **JLCPCB assembly files** with LCSC numbers. Then the board went to Ø36 mm, the trim pins became optional brass, and the **cell moved into a notch in the PCB, open to the rim** (Richard's idea and his choice over a closed hole; the puck is 0.8 mm lower, 10.45 mm). For that the 35° screw boss moved to 40° and D2 moved to the bottom centre.

Rev A redesign (2026-09-27): Richard found the stud version could not be mounted (it needs a bolt from above) and wanted a cheaper flat aluminium plate. Now:
- a 2.0 mm 6061 plate, and the Avalon bolt through a Ø10 steel sleeve that stands on the PCB;
- 3 M2 screws from above;
- **one plain LIR1254** (his choice, after a two-cell feasibility study that split the board and a pouch-cell alternative) on a + spring and a − strap, with R1 = 47k (21 mA);
- the chip antenna kept on board.

To route that on 2 layers:
- R5/R6 removed;
- the − contact and the PCM moved left, and JP1 moved to the bottom;
- SWD on bottom test pads instead of the Tag-Connect;
- SCL/SDA swapped (firmware rebuilt);
- vias 0.55/0.3;
- Freerouting now routes signals only.

The panel moved to annotation tabs in a frame. Then (Richard): the PCB went up on 3 mm standoffs so the magnetic connector is flush with the cap top, the cap came down 0.4 mm (9.90 mm, 1.2 mm free above the cell), the brass trim pin was dropped, the bolt became a button head, one steel tube now runs from the plate through the PCB (hole merged into the cell notch) so the PCB is out of the clamp path, and the M2 screws cheese heads (an M2×8 socket head would reach through the plate).

Shot-shock round (2026-09-29, Richard): the board has **four screws**. H4 was added on the left arm (226°), and H1 moved up beside the tube to (9.2, 1.2), where C1/D1/D3 were (they moved below it). A plate model of the board (VALIDATION.md) showed the left arm (PCM and both cell pads) flapping against the cell and the top half without a screw on the right. Q2's two identical FETs were swapped so the PCM still routes past H4 (§6, Cell protection). The BMD-340 and C2 get corner staking at assembly (README D29). Open for Richard: a tabbed cell (D6). (PCB thickness was settled on 2026-09-30: 1.2 mm, stock 3 mm standoffs, puck 0.4 mm taller, README D30.)

Tube round (2026-09-30, Richard): the bolt tube was bonded into the cap and could fall out through the top once the glue let go, which the stack tolerance and the bolt's squeeze would cause at the first bolt-up. It is now loose and trapped: it stands on the plate and its top end sits in a ring lip under the cap top; the bolt goes through a Ø8.4 hole in the cap top. That puts the PC cap top in the clamp path. Richard knows the creep risk and tests it on the prototype (README D21, VALIDATION §2). If it creeps, the fallback is a turned sleeve with a collar in a recess under the cap top, which keeps the clamp path all steel.

USB-C round (2026-09-29/30, Richard): the magnetic Samzo connector on the cap top was replaced by a waterproof side-entry USB-C port through the cap wall (JLC-assembled). The module slid 45° around the tube so the port fits on the left, everything right of the tube became copper-free (no right-half GND, passage or VIN loop), H1 and H2 moved apart to either side of the port, the die-cut gasket became O-rings (a 37 × 1.0 seal and a 2 × 1.0 clamp O-ring on each screw), and the board got JP2 reset pads and the charger LED firmware (0.2.1). It was developed on the branch `alt/usb-c-side` and replaced the magnetic board on `main` on 2026-09-30; the magnetic board's last state is commit `01f2e00`.

Order round (2026-09-30, Richard): checked against JLC's rules and packaged in `order/`. The JLC CPL got rotation and centroid offsets (§9), the panel drill was split into PTH/NPTH, and the plate got a cheaper 5052 sheet-metal prototype variant. The cap was brought up to JLC3DP's minimum SLA walls: the cap top went from 1.2 to 1.33 mm (puck 10.03 mm), leaving 0.80 mm over the USB-C pocket, and the plug-overmold clearance under the port flat went from 0.25 to 0.20 mm, so the band over the seal O-ring is 0.50 mm. Then the PCB went from 0.8 to 1.2 mm (Richard, README D30). The standoffs stay stock 3 mm, and the cell ceiling (`cell.swell_h` 6.6 → 7.0) and the cap rose 0.4 mm with the board, so every clearance to the board is unchanged. The puck is now 10.43 mm, with 1.6 mm free above the cell and a 7.1 mm tube; the band under the port flat grew to 0.90 mm.

Clean-up (2026-10-01, Richard):
- **U2 is the LSM6DSO32XTR** (C3663738, 177 in stock against 39 for the TR). JLC's footprint for it matches ours at 0° (≤ 0.1 mm), so it needs no CPL offset. It reports the same WHO_AM_I (0x6C, ST's `lsm6dso32x_reg.h`), so the firmware runs unchanged.
- **C5 is gone from `design.py`, `gen_sch.py` and `gen_pcb.py`.** It was removed from the USB-C board and schematic on purpose: the BMD-340 has 4.7 µF on VCC inside, and C4 stays. `check_netlist.py` now PASSes.
- **The stray "ShotPuck rev A" text is deleted.** It sat on B.SilkS at page (11, 6), far outside the board, and inflated any single-board export.
- **The single-board fab files in `kicad/fab/` (BOM, pos, gerbers) are regenerated.** Until then they were still the magnetic board's (2026-09-29).
- **The cap's M2 screw holes are Ø2.4** (`bosses.screw_hole`, was 2.2), giving JLC3DP's 0.2 mm assembly clearance per side.
- **J1's wing-tab pads are about twice the area** (§6, USB-C J1), in `ShotPuck.pretty` and on the board. The board, panel, gerbers and order package were regenerated: board and panel DRC 0/0. Only the front copper, mask and paste changed, all near J1's tabs; the BOM and CPL are unchanged.
- **D3 gets +180° in the CPL** (§9): JLC numbers the SMF5.0CA's pads the other way.
- **The panel fiducials sit 3.85 mm from the rail edge** (KiKit `voffset`, was 2.5 mm), as JLC asks; they are still 5 mm from the side, 1 mm copper in a 2 mm opening, and the opening ends 0.15 mm inside the 5 mm rail. The panel, gerbers and order package were regenerated: panel DRC 0/0 (one of three runs hit the known flaky frame-corner `invalid_outline`). Only the six fiducial flashes moved (1.35 mm inward); the drill, outline, paste, zone fills, BOM and CPL are unchanged.
- **The panel tooling holes are Ø2.0 mm** (KiKit `size`, was 1.152 mm), as JLC prefers; still three, 2.5 mm in from both rail edges. Each hole's wall is 1.5 mm from the panel edge and 0.84 mm from the nearest fiducial's mask opening (1.34 mm from its copper). The panel, gerbers and order package were regenerated: panel DRC 0/0 (one of three runs hit the known flaky frame-corner `invalid_outline`). Only the three tooling holes changed (NPTH drill, mask openings, silkscreen clearance); the outline, copper, paste, BOM and CPL are unchanged (the zone refill differs only by redundant collinear vertices).
- **U2 moved 0.9 mm inward** (Richard, by hand in KiCad: page (132.872, 76.501) → (132.405, 77.244), still −135°), with C3, C6, C7 and their tracks, so its courtyard is 1.1 mm from the top tab's mouse bites (was 0.34; JLC suggests 1.5). `gen_pcb.py`'s `PLACEMENT` still has the old spots (a hand edit, §9). **The top tab is 2.3 mm wide at x = +0.8** (was 1.5 mm at +1.2) and has 5 bite holes like the others (JLC asks for ≥ 5 per set); the GND via at 80° stays 0.36 mm from the bites, H1's courtyard is 0.29 mm away. The board, panel, gerbers, CPL and order package were regenerated: board DRC 0/0, 0 parity issues; panel DRC 0/0 on 8 of 8 runs (with the outline fix below). Only U2, C3, C6 and C7 moved in the CPL; the BOM is unchanged.
- **The flaky panel `invalid_outline` is fixed.** KiKit left 9 Edge.Cuts segments shorter than 10 µm (a 6 µm stub at the frame's top-left corner, 1.5–5.8 µm ones where tabs meet the 0.5 mm mill fillets). KiCad chains outline segments within a small tolerance, and these most likely made it close the frame wrongly on some runs: before, 2 of 3 DRC runs on the same file failed; after, 8 of 8 pass. `gen_panel.py` (`remove_outline_slivers`) now merges each one into its neighbours at its midpoint (the outline moves ≤ 4 µm) and refills the zones, because KiKit's fill sat at exactly 0.300 mm from the old edge and failed `copper_edge_clearance` (0.2992 mm) without the refill. Pads, drill and non-outline drawings are identical; the GND pours differ by about 0.01 mm² per board.

## 2. The user (Richard) – how to work with him

- Software developer in Sweden, on Windows + Cursor/VS Code. He owns the Flutter/PowerSync archery app that will consume the BLE protocol.
- Wants **concise, direct answers**.
- Wants **decisions clearly flagged** for his input.
- Wants **on-device validation requirements listed explicitly**.
- Wants native/embedded logic **validated by simulation before shipping**.
- Wants deliverables as **complete drop-in files/zips**, not patches or diffs. The repo is on GitHub (`Rixard86/shot-tracker`, branch `main`); commit/push only when he asks.
- His global coding rules (no comments, ≤ 2 parameters, ≤ 50-line functions, ≤ 250-line files, no magic numbers) apply to **new or changed code only**, not to refactoring existing files.

## 3. Hard rules of the codebase (do not break)

1. **`layout.json` is the only source of geometry.**
   - Readers: `mechanical/puck.py` (enclosure and balance) and `hardware/gen_pcb.py` (placement, holes, keep-outs).
   - Change geometry there, then re-run both.
2. **`hardware/design.py` is the only source of the circuit.**
   - `.kicad_sch` and `.kicad_pcb` are **generated**; never hand-edit them in the repo.
   - Flow: edit `design.py` → `gen_sch.py` → `check_netlist.py` → ERC → `gen_pcb.py` → `gen_bom.py` → re-export fab files (README "Build & flash").
3. **`firmware/src/shot_detect.c`, `capture.c` and `evlog.c` are portable and shared by the firmware and the host tests.**
   - Any change must be re-run through `firmware/sim/simulate.py --stress`, which must print `CAPTURE TESTS: PASS`, `EVLOG TESTS: PASS` and `RESULT: PASS` before shipping.
   - Keep new logic that can be portable in this form (no Zephyr includes, flash/BLE behind small interfaces) so it can be host-tested.
4. **Wire protocol lives in `firmware/src/protocol.h`** and is documented in `docs/PROTOCOL.md`.
   - Keep the two in sync (packet layouts are also pinned by `test_capture.c`).
   - Bump `PROTO_VERSION` on any layout change, because the Flutter app parses these bytes. It is **2** now.
5. `puck.py` and `gen_pcb.py` share only `layout.json` now (the trim pin and its `trim.json` are gone).
6. **Placement before routing:** after any placement or circuit change, run `gen_pcb.py --no-route` (placement DRC), then `global_route.py` (overflow + hotspots; the split-tube board that routed cleanly scored 8.3, boards that failed scored 8.5–9.2, and parts sitting in a hotspot band showed up there), then `gen_pcb.py --quick` (one Freerouting attempt, ~5 min). Only a placement that passes the trial gets the full run.
7. `gen_pcb.py` must end with **0 DRC violations and 0 unconnected pads**. Freerouting is not deterministic; the script already retries up to 4 times, so re-run it if it still fails.

## 4. Repository map

```
HANDOVER.md, README.md       overview, decisions D1–D11, build/fab/assembly
layout.json                  shared geometry
firmware/
  src/main.c                 event loop, IDLE/ACTIVE modes, BLE glue, event ring (128, RAM only)
  src/shot_detect.[ch]       portable detector (trigger + pre-stillness + post-release LF motion), accel only
  src/accel.[ch]             raw LSM6DSO32 I2C driver (IDLE 12.5 Hz LP wake-up / ACTIVE 416 Hz accel+gyro FIFO)
  src/capture.[ch]           portable capture ring (2.8 s), 4 shot windows (−1.0 s..+0.5 s), BLE packet packing
  src/capture_tx.[ch]        queues captures and pumps CAPTURE notifications without blocking
  src/evlog.[ch]             portable flash ring log of accepted shots (32 B records, CRC, torn-write safe)
  src/event_tx.[ch]          shot log on the eventlog partition, RAM ring of rejects, live queue, paced batched EVENT/REPLAY
  src/claim.[ch]             pairing window (60 s after VBUS appears), pairing-accept callback, FORGET_BONDS
  src/identity.[ch]          name ShotPuck-XXXX and DIS serial from the nRF FICR device ID
  src/power.[ch]             VDDH/5 SAADC battery, die-temp charge inhibit, REGOUT0=3.0 V, System OFF
  src/store.[ch]             Zephyr settings/NVS: total, seq (+1024 margin at boot), cfg
  src/ble.[ch], protocol.h   GATT service 7a1e0001-5b0c-4f3a-9c6e-3a5d2b9e0a01 + BAS
  boards/shotpuck/shotpuck/  custom HWMv2 board, target `shotpuck/nrf52840` (flash partitions in the .dts)
  prj.conf / debug.conf      release (no log/UART) / RTT logging overlay
  VERSION                    app version, signed into the image
  sysbuild.conf / .cmake     MCUboot (swap-using-move, ECDSA-P256) + guard against the public dev key
  shotpuck_full.hex          MCUboot + signed app, first flash by SWD (merged with zephyr/scripts/build/mergehex.py)
  shotpuck_update.bin        signed app image for OTA
  src/ota.[ch]               watchdog (10 s) and self-confirm of a trial image after 10 s healthy and a paired, encrypted link
  src/factory.[ch]           factory reset from the JP2 reset pads, boot-loop recovery (GPREGRET2 counter), erase of storage + eventlog
  src/recovery.[ch]          portable logic: pad hold (5 s, armed only by a bridge made while running) and boot-loop count
  src/chg_led.[ch]           charger LED mode (charging / full / paused) from the power state
  sim/simulate.py            Monte Carlo generator + scorer (ctypes → libsd.dll/.so), runs test_capture
  sim/sim_runner.c           IDLE/ACTIVE pipeline + LSM6DSO32 accelerometer model
  sim/test_capture.c         host unit tests for capture.c
  sim/test_evlog.c           host unit tests for evlog.c (fake NOR flash)
  sim/test_chg_led.c         host unit tests for chg_led.c
  sim/test_recovery.c        host unit tests for recovery.c
  sim/results.txt            last run (seed 2026, 36 sessions)
hardware/
  design.py                  parts/pins/nets table (the schematic)
  sexp.py                    tiny S-expression reader/writer
  gen_sch.py                 → kicad/shotpuck.kicad_sch (lib symbols copied, labels on pins)
  check_netlist.py           kicad-cli netlist export vs design.py (must PASS)
  gen_pcb.py                 footprints, placement (PLACE dict), keep-outs, GND fanout,
                             Freerouting, SES import, stitching, pours, island bridging, DRC (kicad-cli)
  board_shape.py             board outline, cell notch, bolt hole, sleeve land, antenna zone (shapely, from layout.json)
  islands.py                 bridges GND pour fragments cut off from the main plane (post-fill)
  place_eval.py              airwire model of a placed board (MST per net, locked copper pre-connected), crossings
  global_route.py            routability estimate before Freerouting: 0.5 mm grid global router (A*, congestion
                             negotiation) on the board's own outline, keep-outs and pads -> overflow + hotspots
  gen_bom.py                 → kicad/fab/shotpuck-bom.csv
  gen_panel.py               → kicad/panel/shotpuck-panel.kicad_pcb (KiKit 2x2 in a frame, 4 annotation tabs per board, top row turned 180°, mouse bites, fiducials, tooling)
  gen_jlc.py                 → kicad/fab/jlc/ BOM + CPL for JLCPCB assembly (LCSC numbers and JLC_FOOTPRINT_OFFSETS in the script)
  check_place.py             stray helper of unknown provenance, not part of the flow (safe to ignore/delete)
  kicad/                     project, ShotPuck.pretty, schematic PDF, PCB render PNG, drc.rpt, erc.rpt,
                             fab/ (gerbers+drill zip, pos, BOM)
mechanical/puck.py           CadQuery model + mass/balance → out/ (STEP/STL/mass_report)
mechanical/geometry.py, puck_parts.py, puck_report.py   its heights and poses, part builders, report and export
mechanical/plate_drawing.py  plate manufacturing drawing (hole table, M2 thread callout) → out/plate_drawing.pdf, plus the
                             5052 sheet-metal prototype variant → out/plate_drawing_5052.pdf + out/plate_5052.step
mechanical/blender/          render_assembly.py (entry) + parts/cellconn/shapes/stack/looks/motion: exploded-view animation → out/shotpuck_assembly.mp4
docs/PROTOCOL.md             BLE protocol v2 + recommended app sync
docs/VALIDATION.md           proven vs on-device checklist
```

## 5. Verified state (numbers to quote)

| Item | Result |
|---|---|
| Firmware (Zephyr v4.1.0, SDK 0.17.0, Windows, sysbuild) | 0 compiler warnings; app 200,016 B of a 452 KB slot, RAM 90,048 B of 256 KB; log+assert variant 267,092 B / 95,308 B; MCUboot 27,980 B of 48 KB (one harmless upstream Kconfig warning about MBEDTLS_CFG_FILE, MCUboot uses TinyCrypt) |
| OTA signing | Image validates with the private key (`imgtool verify`), fails with MCUboot's dev key; MCUboot embeds the matching public key (91 bytes compared); build refuses to run without the private key |
| Capture unit tests | PASS (also mutation-checked: an off-by-one window start is caught) |
| Shot log unit tests | PASS: 952 of 3000 kept after wrap; torn write/erase recovery; never writes unerased flash (mutation-checked) |
| Sim nominal (36 sessions, 437 shots) | recall 99.08 %, precision 99.77 % (1 FP, stand knock) |
| Sim hard cases (479 shots) | recall 99.58 %, precision 99.38 % (3 FP: 2 grab, 1 stand knock) |
| Sim weak bow (info only, 253 shots) | recall 80.2 %, precision 99.5 %, dominated by missed triggers / no follow-through |
| Firmware rev A (2026-09-29, BMD-340) | Rebuilt for the BMD-340 pin map: same sizes (200,016 B / 27,980 B), only the known MCUboot Kconfig warning, `imgtool verify` valid with our key and rejected with the dev key; compiled DTS has SCL = P0.07, SDA = P0.05, ACC_INT1 = P0.03, CHG_STAT = P0.15 (active low), CHG_INH = P0.11, LED = P0.13 |
| Schematic | `check_netlist.py` PASS, 117 pin assignments, 29 nets (USB-C board, 2026-10-01); KiCad 10 ERC 0 errors, 2 warnings (intentional SA0/SDx straps to GND) |
| PCB | Ø36 mm 2-layer, 1.2 mm (0.8 until 2026-09-30), track 0.15 / clearance 0.127, vias 0.55/0.3 mm, fully routed, with the hand edits (J1's board-edge notch, the GND via at (−0.41, 16.09), JP2, silkscreen, U2 moved inward): **0 DRC violations, 0 unconnected, 0 schematic parity issues** (KiCad 10 DRC, 2026-10-01) |
| Panel | 91.1 × 92.7 mm, 1.2 mm, 2×2 in a frame with a backbone between the rows, 16 tabs, **0 DRC violations, 0 unconnected** (2026-10-01); four exact copies of the board; JLCPCB BOM 21 lines / CPL 112 placements, every JLC footprint pad on our same-numbered pad (placement simulation, §9) |
| Enclosure | 10.43 mm above the weight face (plate 2.0 + Kapton 0.1 + 3.0 mm standoffs + PCB 1.2; cell on the Kapton in the PCB notch, 7.00 mm from there to the ceiling = 1.6 mm free), USB-C port through the cap wall (0.80 mm of cap top over its body), O-ring seals, 16.72 g, COM 0.47 mm off axis (no trim weight), 4 standoffs. CadQuery: the cap is one solid and overlaps nothing but the port's seal ring (its intended squeeze) |
| Board under shot shock (plate FE, 100 g along the axis) | 4 screws, 0.8 mm: first mode 1.7–2.0 kHz (was 1.1–1.2), worst strain 160–180 µε (was 320–340), cell pads ~0 µm against the cell (was 13–15). At 1.2 mm, the board now: 2.7–3.2 kHz, ~100 µε. The model script (scikit-fem) is not in the repo |

Before the IMU change, the unchanged v0.1 sources were rebuilt on Windows as a toolchain check: firmware byte-identical in size (142,620 B / 27,856 B), netlist PASS.

Detector defaults (tunable over BLE CONFIG) are unchanged except the sample rate (416 Hz):

| Parameter | Default |
|---|---|
| Trigger (sample-to-sample jump) | 6000 mg |
| Motion threshold | 300 mg |
| Required pre-trigger stillness | ≥ 500 ms |
| Post-release LF motion (mean over 100–600 ms) | ≥ 250 mg |
| Refractory period | 1500 ms |
| Wake threshold | 150 mg |
| Idle timeout | 30 s |
| Gravity filter time constant | 0.25 s |

## 6. Key design facts (easy to get wrong)

- **Power:** cell → U1 **VCCH** (BMD-340 pad 65 = nRF52840 VDDH, high-voltage mode). REG0 drives **VCC = VDD = 3.0 V** (pad 17); firmware writes UICR REGOUT0 on first boot and resets once. VDD powers the LSM6DSO32 (VDD and VDDIO), LED and SWD VCC, well under u-blox's 5 mA limit for external loads in high-voltage mode.
- **Battery voltage:** read via SAADC `NRF_SAADC_VDDHDIV5`. The define needs `#include <zephyr/dt-bindings/adc/nrf-saadc-v3.h>`.
- **Charge inhibit logic:**
  - PROG → R1 47k (21 mA for the LIR1254) → Q1A. Q1A's gate is pulled to VIN by R2 (1M).
  - Q1B (gate = CHG_INH on P0.11, R3 100k pull-down) pulls Q1A's gate low, which floats PROG and disables charging.
  - **Default = charging allowed** (deliberate, so a flat cell can recover).
- **Charge status:** STAT → D2 BAT54J → P0.15. The GPIO pull-up is enabled **only while VBUS is detected**, which avoids standby leakage.
- **Pins:**

  | Signal | nRF pin | BMD-340 pad |
  |---|---|---|
  | I2C SCL | P0.07 | 23 |
  | I2C SDA | P0.05 | 21 |
  | ACCEL_INT1 (IMU INT1) | P0.03 | 19 |
  | CHG_STAT | P0.15 | 33 |
  | CHG_INH | P0.11 | 27 |
  | LED | P0.13 | 31 |
  | SWD | SWDIO / SWCLK | 44 / 43 |
  | VBUS (charger present, System-OFF wake), via R9 1k + C9 100n (net VBUS_SNS) | VBUS | 66 |
  | Supply in / out | VCCH / VCC | 65 / 17 |
  | GND | – | 1–5, 16, 18, 29, 30, 45–47, 55 |

  - LSM6DSO32 is at I2C address **0x6A** (SA0 = GND), CS = VDD (I2C mode), SDx/SCx = GND, INT2/OCS_Aux/SDO_Aux unconnected. KiCad symbol: `Sensor_Motion:LSM6DSL` (same pinout), footprint `LGA-14_3x2.5mm_P0.5mm_LayoutBorder3x4y`.
  - BMD-340 pin choice: the module's second pad column (17–29) escapes through the gaps of the outer column (61–68), so VDD, ACC_INT1, SDA, SCL and CHG_INH leave its left end straight towards the IMU and the charger. ACC_INT1 is the only signal on a low-frequency-only pin (P0.03, fine for an interrupt). P0.09/P0.10 (NFC) and the USB pads 67/68 are not used. LED (pad 31) and CHG_STAT (pad 33) sit on the bottom row: the LED drops straight to R4, CHG_STAT goes through a locked via to B.Cu.
  - `design.py`, the board DTS and the pinctrl `.dtsi` must change together. The I2C pull-ups are the nRF's internal ones (~13 kΩ, 400 kHz): there are no external pull-up pads.
  - Footprint and symbol are generated by `hardware/bmd340.py` from data sheet UBX-19033353 R13 (Figure 12 land pads, Table 2 pinout). Its pad table matched two independent open-source footprints of boards that were built (OSHWA 2020 badge, DEF CON 27 badge) to 0.000 mm, and its 68 pin names were compared programmatically with the data sheet table. The 3D model is u-blox's own STEP (`kicad/ShotPuck.3dshapes/u-blox_BMD-340.step`, corner origin, long axis +Y, antenna at +Y), rotated −90° (KiCad turns a positive Z rotation clockwise; +90° put it 15 mm off and backwards) and offset (7.5, −5.1) to the body centre. Checked in a STEP export of the board: body at x −6.5…8.5, y 5.4…15.6, shield can ending at x 3.88 so the bare antenna sits over the keep-out, and all 68 model pads on the copper pads (0.000 mm).
- **IMU configuration** (register values checked against ST's `lsm6dso32_reg.h` in `C:\zp\modules\hal\st`):
  - Init: software reset, BDU + IF_INC, **I3C disabled** (CTRL9_XL = 0xE2, datasheet recommendation for I2C-only use). INT1 has an internal pull-down and must be low at power-on for I2C mode: the nRF pin is high-Z then, so never add a pull-up to ACC_INT1.
  - IDLE: gyro off, accel low-power 12.5 Hz ±8 g, slope wake-up (31.25 mg/LSB, latched, clear on read) → INT1.
  - ACTIVE: accel 416 Hz ±32 g (0.976 mg/LSB), gyro 416 Hz ±2000 dps (70 mdps/LSB), FIFO continuous, both batched at 417 Hz, watermark 52 words → INT1. The FIFO holds 3 KB uncompressed (~0.5 s at this rate), so the main thread must not block for long. The driver reads it word by word (7 bytes each) and pairs each accel word with the latest gyro word.
- **Capture:** ring of 1152 samples; for each **accepted** shot a window from trigger − 416 to trigger + 208 samples is copied into one of 4 slots; the window completes when the ring has its last sample. Detector time ↔ sample index uses `cap_index_to_ms` / `cap_ms_to_index` (exact inverses, tested).
- **Clocks and regulators:** 32 kHz from RC (the BMD-340 has no 32.768 kHz crystal); REG0/REG1 in LDO mode. The module does carry the DC/DC inductors, so DC/DC could be enabled later to save active current.
- **Board orientation** (layout coordinates, +y up, board centre = bolt axis):
  - Module U1 (BMD-340, 15.0 × 10.2 mm) at (7.78, 7.78), rotated 135°: centre at r = 11.0, long axis tangential, slid 45° clockwise around the tube from the top so the left side is free for the USB-C port. Tube and rim clearances are as they were at the top: both outer corners 0.24 mm inside the rim (the outline tolerance is ±0.2 mm), the body 0.9 mm above the tube. The antenna end points 45° below +x. `board_shape.rf_keepout()` makes the antenna zone plus everything right of the sleeve hole copper-free, except the module's own footprint (+0.5 mm). `PRE_VIAS` offsets for U1 rotate with it (`turned()` in `gen_pcb.py`).
  - Cell at (0, −11.75) in a notch open to the rim: Ø13.0 mm round end (`cell.pcb_hole_clear` 0.25 mm) with straight edges out to the rim. The Edge.Cuts outline (rim, notch, Ø8.4 bolt hole) comes from `board_shape.py`; `puck.py` cuts the same shape.
  - Cell contact pads (2.5 × 2.0 mm SMD, `ShotPuck:LIR1254_Contacts`) both left of the notch: + at (−7.27, −7.55) for a spring on the can side, − at (−8.27, −13.2) for a strap over the top cap.
  - USB-C J1: SHOU HAN TYPE-C 6PFS 2JCB1.6-H6.7 IPX8 (6-pin, power-only, LCSC C3020041, JLC-assembled), at 132.58° on the left rim (midway between H1 and H2), plug axis radial through the cap wall. It sits recessed in a notch in the board edge (10.28 × 5.22 mm, 0.5 mm router fillets at the back corners); the notch sides run through two Ø0.70 NPTH holes that take the part's legs, as in LCSC's footprint, because the datasheet's 0.69 mm U-slots are too narrow to route. Footprint `ShotPuck:USB_C_Receptacle_ShouHan_TYPE-C-6PFS-2JCB1.6-H6.7_IPX8`: signal pads from the datasheet drawing, kept 0.3 mm from the notch. The wing-tab (shell) pads were enlarged on 2026-10-01 (Richard), because the wide notch left only a 0.5 mm strip of each 1.35 × 2.0 mm tab (measured in the STEP model) on pad. Each is now 0.96 × 2.35 mm, about 2.0 mm² (was 0.99): 0.31 mm from the notch, a round cut-out 0.25 mm clear of the leg hole, 0.40 mm past the tab's outer edge and ~0.17 mm past both ends for fillets (0.86 mm² under the tab, was 0.61), and ≥ 2.35 mm from the H1/H2 screw centres (keep-out r 2.2). At 0.30 mm from the notch, one panel copy rounded to 0.2992 mm and failed DRC, so keep the 0.01 mm margin; LCSC's STEP model, shifted −1.93 mm so its pins sit on the pads (LCSC's own footprint has no offset and a notch that disagrees with the datasheet). The board edge is 0.15 mm behind the datasheet's product edge so the whole silicone ring lands in the cap wall. R10/R11 (5.1k) pull CC1/CC2 down so USB-C chargers switch on 5 V. D3 → D1 → C1 sit right behind the port, then VIN runs down to the charger. **`gen_pcb.py` does not draw the notch: regenerating the board loses it and the hand edits** (the GND via below, JP2, silkscreen).
  - IMU U2 in the wedge between the module's left end and the port; C3/C6/C7 in the pocket below it, C4 at the module's upper-left corner; R4, R9 and C9 below the module's left end. The status LED D4 sits at the left rim so it shows through the cap wall (Richard); LED_A runs on B.Cu from R4 to it.
  - GND via at (−0.41, 16.09): the F.Cu pour around U2's GND pins 6/7 reached the rest of GND only along the rim, where the top panel tab's mouse bites cut it; the via ties that patch to the B.Cu plane.
  - Charger (U3, Q1, R1–R3, D2) on the left at y ≈ −1.5…2; PCM (U4, Q2, R7, R8, C8) at the lower left, x −15.5…−9, y −4…−10, just above H4; R8 at (−15.2, −7.4), turned 90°, left of U4.
  - Bottom side: JP1 at (−10.2, −5.0) and the SWD test pads J2 under the module, moved with it: VDD (5.65, 13.44), SWDIO (7.45, 11.65), SWDCLK (9.24, 9.85), GND (11.04, 8.05) (2.54 mm pitch along a 45° line, board coordinates seen from the cap; the pogo jig must match). J2's GND pad gets a solid zone connection and no fan-out via; SWDIO/SWDCLK leave U1 through locked vias (`PRE_VIAS`).
  - Reset pads JP2 (Richard): two bare round Ø0.8 mm pads, 0.4 mm apart, no paste (`ShotPuck:TweezerPads_2x0.8mm_Gap0.4mm`), at (11.77, 12.35) on top beside module pin 7: BTN (P0.26, internal pull-up) and GND. With the cap off, bridging them with tweezers is the factory-reset input; no J-Link and no cell removal needed (a tabbed cell may be soldered in). Copper only: not in the JLC BOM or CPL. A tactile switch was tried first (C&K KMT0, 3.0 × 2.6 mm) but no switch fits the left half. The firmware (0.2.1) reads BTN: bridged for 5 s it erases settings, pairings, shot count and log and reboots (docs/PROTOCOL.md). When updating footprints from the library, update only the one you changed and leave the Reset options off: an update of all footprints dropped U1's solid zone connection (module GND pad 45 lost the pour) and U3/R3/D4's "none".
  - Board Ø36 mm: the puck is Ø40 mm = the Avalon barebow weight (the true constraint); cap wall 1.5 mm leaves a Ø37 mm cavity, 0.5 mm clearance per side.
  - Screw holes Ø2.4 mm, all at r = 16.5 mm: H1 100.6° (−3.04, 16.22), H2 164.5° (−15.89, 4.39), H3 305°, H4 226° (`bosses.positions` in `layout.json`; the plate's tapped holes and the cap bosses follow). H1 and H2 sit either side of the USB-C port, moved apart (Richard) so the ground pour reaches J1's wing tabs. H4 holds the left arm (PCM, cell pads), which had no screw below H2 (D29); R8 moved to (−15.2, −7.4), U4 and Q2 up by 0.35/0.5 mm to clear it.
  - The bolt tube (Ø10) passes through a Ø10.4 hole (0.2 mm clearance for JLCPCB's ±0.2 mm outline tolerance) that a straight slot merges with the cell notch (`board_shape.sleeve_hole`), so no FR-4 web is left between them. Everything right of the hole is copper-free (`rf_keepout`), so no signal has to cross the slot: there is no right-half GND, no passage and no VIN loop (`VIN_ESCAPE = None`). The antenna zone matches the BMD-340 keep-out (the module's last 4.4 mm, ±6.2 mm across; `ANTENNA_INSET`/`ANTENNA_HALF_W` in `board_shape.py`), then runs on to the rim. Links and vias locked before Freerouting are in `gen_pcb.py` (`PRE_LINKS`, `PAD_BRIDGES`, `PRE_VIAS`, `PRE_ROUTED`). `gnd_fanout` keeps its stubs clear of F.Cu signal tracks (it used to check only the via spot).
- **Keep-outs in `gen_pcb.py`:** `rf_keepout` (antenna zone plus everything right of the tube); 0.35 mm copper-free band along the cell notch (both layers); 4 boss faces, Ø3.8 + 0.3 mm; 0.35 mm rim ring. The boss rings keep both layers copper-free under the cap bosses and the standoffs.
- **Cell protection:** BAT_N (cell −) → Q2B (pins 4/5, DOUT) → PCM_D → Q2A (pins 1/2, COUT) → GND. The DMN2004DWK's two FETs are identical; they were swapped (2026-09-29) so U4's COUT pin faces Q2 pin 2 straight across (locked link) and DOUT, locked too, loops over Q2's top to pin 5: H4 took the room under Q2 where the old COUT loop ran. Q2 pin 1 (GND) sits inside that loop, so it has a locked via above Q2 (`PRE_VIAS`) and a solid zone connection. BQ29700: OVP 4.275 V, UVP 2.80 V, OCD/OCC ±100 mV over ~1 Ω of FETs (≈ 0.1 A), SCD 0.5 V, 4 µA. R7 feeds BAT from VBAT (= cell + through JP1). The firmware's 3.3 V cut-off stays the primary over-discharge guard.
- **Mechanical (`puck.py`):** plate (2.0) → Kapton (0.1) → standoffs (`puck.pcb_standoff`, 3.0) → PCB (1.2); the cell sits on the Kapton in the PCB notch (`Z_CELL`); ceiling = `Z_CELL` + `cell.swell_h` (7.0 mm); cap top 1.33 mm, total 10.43 mm. The tube runs from the plate through the PCB to the underside of the cap top (7.1 mm, `Z_SLEEVE_TOP` = `Z_CEIL`), loose, located by a ring lip under the cap (Ø10.2 inside, `SLEEVE_LIP_WALL` 0.8, `SLEEVE_LIP_DEPTH` 0.6: its bottom is 0.3 mm above the module and it is 0.35 mm clear of the foam pad); the bolt passes the cap top through a Ø8.4 hole and clamps the PC cap top onto the tube (README D21). 4 M2×8 cheese head screws from above hold the cap; the counterbore depth is set so the screw tip ends `tip_inset` (0.1 mm) inside the plate. `mechanical/blender/stack.py` imports these heights from `geometry.py`.
- **Cap for the port (`puck_parts.py`):** the connector's silicone ring (10.44 × 4.66 × 0.95) seals radially in an obround hole in the cap wall, squeezed 0.15 mm per side (1.15 mm of cap above the hole, 2.92 mm of wall below, 2.17 mm of it above the seal O-ring); a flat at the receptacle face (r = 19.49 mm, 9.0 mm wide) from 0.20 mm below the tallest USB-C plug overmold (12.35 × 6.5 mm) up through the cap top lets any compliant plug seat fully; a pocket over the body leaves 0.80 mm of cap top (the report prints it). Checked in CadQuery with the real STEP model: its only overlap with the cap is the ring squeeze (2.1 mm³; 7.8 mm³ against `puck.py`'s box model of the connector), none with the plate, bosses or board; a maximum-size overmold clears cap and plate.
- **Cap-to-plate seal (`layout.json` `seal`, `bosses.boss_gap`/`clamp_oring`):** the plate stays flat (laser-cut, 4× M2 tapped). The SLA cap wall is stepped: its inner band (Ø37 cavity to Ø37.8 ledge) reaches the plate and is the hard stop, the outer band (Ø37.8 to Ø40) stops 0.75 mm above the plate. An off-the-shelf **O-ring 37 × 1.0** (VMQ or NBR, 70 Shore A) stretches ~2.2 % onto the ledge, so it stays on the cap during assembly, and is squeezed 25 % between the outer band and the plate (squeezed, it spans r 18.82–19.98). External water pressure pushes it onto the ledge, the right side. The thinnest cap over it is 0.90 mm, under the port flat. The cap bosses stop 0.65 mm above the PCB; an **O-ring 2 × 1.0** on each M2 screw under its boss clamps the board (~35 % squeeze, ~15–55 % over the ±0.2 mm Kapton/standoff/PCB stack) and keeps the screw captive in the cap. The board is held through rubber, not by the bosses directly: the D29 shock model assumed a rigid clamp, so watch the screw preload and the board in the durability run. Assembly: stretch the big O-ring onto the ledge, push the 4 screws down through the cap and a small O-ring onto each below its boss, then lower cap + screws + O-rings as one unit and tighten until the inner band seats on the plate (the stop sets the squeeze). Buy 36, 37 and 38 × 1.0 and try them on the first SLA print; resin shrink moves the ledge, so tune `seal.ledge_od`/`squeeze` (and `connector.seal_squeeze`) from that print. In the Blender animation both O-ring sizes ride with the cap.
- **Plate drawing (`plate_drawing.py`):** A4 at 2:1 from `layout.json`: top and side views, a hole table (H1–H4 "M2×0.4 tapped through", the Ø8.4 centre hole) and notes (6061-T6, underside chamfer, O-ring sealing face, ISO 2768-m, mask threads if anodised). Send it with `plate.step`: the STEP shows the M2 holes as plain Ø1.6 tap-drill holes. JLCCNC machines 6061 only by CNC; its sheet-metal service stocks only 5052, so the script also writes a prototype variant for it (5052-H32, laser cut, no chamfer: `plate_drawing_5052.pdf`, `plate_5052.step` from `make_plate(0.0)`). Richard allowed a cheaper prototype material (2026-09-30).
- **Panel (`gen_panel.py`):** KiKit's `millradius` is 0.5 mm, the radius of JLCPCB's Ø1.0 mm router (it was 1 mm until 2026-09-30, which rounded J1's notch corners to 1.0 mm instead of the board's 0.5 mm fillets). Fixed KiKit tabs are symmetric, and no symmetric set clears both the cell notch (|x| ≤ 6.6 at the bottom) and the rest of the rim. So `gen_panel.py` adds `kikit:Tab` annotation footprints to a temporary copy of the board: top 2.3 mm wide at x = +0.8 (between H1's courtyard and the GND via at 80°; 5 bite holes), bottom at x = −8.5 (left of the notch; at −10 and −9 its mouse bites fell inside H4's courtyard), left and right at y = −4, 3 mm wide. The top row is turned 180° (`rotation: 180deg; alternation: rows`), and a 2 mm backbone runs between the rows, 2.5 mm from each, so each board's top tab lands on the backbone instead of the other board next to its H1. The notch sides and the outer sides tab to a full frame. After KiKit, `remove_outline_slivers()` merges Edge.Cuts segments shorter than `SLIVER_MM` (10 µm) into their neighbours and refills the zones; KiKit leaves a few at the frame corner and the mill fillets, and they made DRC report a self-intersecting outline on some runs. Panel 91.1 × 92.7 mm. The tab positions use the board's own centre as origin (the board sits at (132.06, 91.40) on the KiCad page), as does the board's GLB export for the Blender animation.
- **Ground strategy:** every GND SMD pad gets a stub + via before routing (`gnd_fanout`, which keeps clear of every via already on the board, including the SWD escape vias). The DSN handed to Freerouting has the GND planes and GND pins stripped (`signals_only`), so it routes signals only; with the planes in, it stalls. `stitch()` adds grid GND vias only after all routing (stitch vias placed before the second pass filled the PCM pocket and blocked it), dangling track ends are deleted (`remove_dangling`), pours fill with island removal (connectivity is rebuilt before every fill; a stale one kept dead islands and got a useless bridge via), then `islands.bridge_islands()` adds a via for any GND fragment group not tied to the main plane, never inside a via keep-out. U2's GND pads use a solid zone connection (a thermal on pad 6 was starved). Pre-routed links (`PRE_ROUTED`): Q2's common drain PCM_D and Q1.4–Q1.1.
- **Identity:** `identity_apply()` (after `bt_enable` and `settings_load_subtree("bt")`) reads the 8-byte FICR device ID, sets the name `ShotPuck-` + last 4 hex digits, and sets the DIS serial via `settings_runtime_set("bt/dis/serial")` (needs `CONFIG_SETTINGS_RUNTIME`).
- **Pairing (claim):** LE Secure Connections Just Works, bonds stored by `CONFIG_BT_SETTINGS`, max 4 (oldest overwritten). `pairing_accept` rejects new pairings unless the window is open; the window opens for 60 s on a VBUS rising edge (polled via `power_vbus_present()` in the main loop, which wakes at least every 2 s; boot with the charger attached counts). LED blinks 1/s while open, twice on a new bond. Every ShotPuck characteristic value and CCC needs encryption; DIS and BAS are open. Zephyr restores a bonded phone's subscriptions only after the link is encrypted.
- **Flash layout (1 MB):** `boot_partition` 0x00000 48 KB (MCUboot); `slot0` 0x0C000 460 KB (running app); `slot1` 0x7F000 460 KB (OTA download); `eventlog` 0xF2000 32 KB; `storage` 0xFA000 24 KB (NVS: counts, config, bonds). Shots, settings and bonds survive OTA.
- **OTA:** sysbuild builds MCUboot + app and signs the app with ECDSA-P256 (key `C:\Users\rixar\.shotpuck\ota-signing-key.pem`, never in the repo; pass it quoted as `-DSB_CONFIG_BOOT_SIGNATURE_KEY_FILE=\"...\"`, otherwise Kconfig silently falls back to the public dev key and `sysbuild.cmake` stops the build). MCUmgr SMP over BLE (img + os groups) with `PERM_RW_ENCRYPT`, progressive erase. MCUboot swap-using-move; a new image runs as a trial, `ota.c` confirms it after 10 s of main loop, the phone may confirm earlier. The watchdog (10 s, fed every main-loop pass; paused only under a debugger) turns a hang into a reset, and MCUboot then reverts an unconfirmed image. MCUboot feeds the watchdog during the swap. In the no-IMU SOS loop the watchdog is fed only if the image is confirmed, so a broken update rolls back while a confirmed image with a dead sensor stays up for diagnostics.
- **Event transmission:** `event_tx` sends live events first, then a REPLAY (flash shots, then RAM rejects), up to 10 events per EVENT notification. EVENT and CAPTURE share a limit of 2 notifications in flight; the completion callback wakes the main loop. Nothing in the main loop waits on BLE buffers any more (the v0.1 replay loop slept up to 1 s per event).
- **BLE:**
  - Advertises while ACTIVE, plus a 120 s linger, and while the pairing window is open.
  - Requests MTU 247 (data length extension on). EVENT is 24 bytes, so MTU must be ≥ 27; capture works at any MTU ≥ 23.
  - Every detector candidate (accepted or rejected) is notified as EVENT; only accepted shots get a CAPTURE.
  - CAPTURE notifications are paced (max 2 in flight, completion callback wakes the main loop) so the main thread never blocks on BLE buffers while the IMU FIFO fills.

## 7. Environment (native Windows, already installed on Richard's PC)

| Tool | Location |
|---|---|
| KiCad 10.0.6 (Python 3.11 with `pcbnew`, `kicad-cli`) | `C:\Program Files\KiCad\10.0\bin` |
| Java 21 (Temurin JRE), Freerouting 2.1.0 | `C:\Users\rixar\tools\jre21`, `C:\Users\rixar\tools\freerouting-2.1.0.jar` |
| w64devkit gcc 16.2 | `C:\Users\rixar\tools\w64devkit\bin` |
| CMake 3.31.8, Ninja 1.12.1 | `C:\Users\rixar\tools\cmake3\bin`, `C:\Users\rixar\tools\ninja` (system CMake is 4.3: do not use it for Zephyr) |
| Zephyr v4.1.0 west workspace | `C:\zp` (project filter: cmsis, cmsis_6, hal_nordic, segger, hal_st, mbedtls, mcuboot, zcbor), venv `C:\zp\.venv` (west, numpy, scipy, pypdf, imgtool deps, Zephyr requirements) |
| OTA signing key | `C:\Users\rixar\.shotpuck\ota-signing-key.pem` (ECDSA-P256; Richard must back it up) |
| CadQuery 2.8 (Python 3.12, via uv) | `C:\zp\.cq` (run `C:\zp\.cq\Scripts\python.exe mechanical\puck.py`) |
| Blender 3.1 (Cycles on the RTX 3080 via OptiX) | `C:\Program Files\Blender Foundation\Blender 3.1` (run `blender.exe -b -P mechanical\blender\render_assembly.py`) |
| KiKit 1.8.1 | installed with `--user` into KiCad 10's Python (`python.exe -m kikit.ui ...`) |
| Zephyr SDK 0.17.0 (arm only) | `C:\zp\zephyr-sdk-0.17.0` |

Build commands are in README "Build & flash". Keep toolchains and build directories out of the repo: it lives in a Synology-synced folder.

### Gotchas already paid for

- **CMake 4.x breaks Zephyr 4.1.** Use the 3.31 in `tools\cmake3`.
- **`CONFIG_BT_SMP` needs the `mbedtls` module** (PSA crypto); without it Kconfig aborts with MBEDTLS/PSA_WANT dependency warnings.
- **Upstream sysbuild makes no `merged.hex`** (that is nRF Connect SDK). Merge `build/sb/mcuboot/zephyr/zephyr.hex` + `build/sb/firmware/zephyr/zephyr.signed.hex` with `zephyr/scripts/build/mergehex.py`.
- **Custom board with sysbuild:** pass `-DBOARD_ROOT=<repo>/firmware` on the command line so MCUboot finds the board too.
- **The harness blocks `git rm` inside long PowerShell command lines** (it reads it as Remove-Item on a system path). Run it alone (`git -C <repo> rm ...`).
- **KiCad 10 Python API (vs the v0.1 KiCad 7 scripts):**
  - `pcbnew.WriteDRCReport` pops a wxWidgets assert dialog on the user's screen ("assert process failed in Pgm()") and hangs. Never call it; DRC runs via `kicad-cli pcb drc`. ERC via `kicad-cli sch erc`.
  - `PCB_VIA.GetWidth()` without a layer asserts (and in a long script it hung on a dialog): use `GetWidth(pcbnew.F_Cu)` for vias.
- **No drill/place (aux) origin on the board.** With one set (tried at the bolt axis, 2026-10-01), KiKit's frame came out with µm-level skew at its outer corners, and KiCad DRC flagged the panel outline as self-intersecting. So `kicad/fab/shotpuck-pos.csv` is in KiCad page coordinates: the bolt axis is at page (132.064, 91.396), and pos Y is negated.
  - `FP_SHAPE` is gone (use `PCB_SHAPE(fp, …)` with `SetStart/SetEnd/SetCenter`); no `SetPos0`; `SetDescription` → `SetLibDescription`; `SetDoNotAllowCopperPour` → `SetDoNotAllowZoneFills`; netclass via `GetDefaultNetclass()`; `LSET(layer)` does not construct: use `AddLayer`.
  - `Q_Dual_NMOS_S1G1D2S2G2D1` moved from the `Device` to the `Transistor_FET` symbol library.
  - `FootprintLoad`/`FootprintSave`, zone fill, `ExportSpecctraDSN`, `SaveBoard`/`LoadBoard` all work standalone.
- **Board thickness:** `gen_pcb.py` sets it from `layout.json` `puck.pcb_thickness` (1.2 mm since 2026-09-30; the hand-edited board got it by editing its `(general (thickness …))` line, with no custom stackup in the file). Before 2026-09-27 it was never set, so the board, panel and Gerber job files said KiCad's default 1.6 mm (found when the Blender render showed a board twice as thick).
- **Blender render:** KiCad's GLB materials import as metallic/rough 1.0 and the solder mask is 83 % transparent; `looks.tune_imported()` fixes both (dark green opaque mask, dark parts non-metallic). Parts are built in place (origin at the world origin) and animated as z offsets from their rest position (`motion.EXPLODE_MM`, `motion.STEPS`).
- **Freerouting quirks:**
  - 2.1 ignores the old `-mp`/`-mt` flags (its settings file says `max_passes: 9999`) and can loop forever on a blocked connection, so `route()` has a subprocess timeout; a timed-out pass can leave an empty `.ses` (handled).
  - With its multi-threaded optimizer on, it "restores an earlier board" and then writes a `.ses` that is missing whole nets while reporting 0 incomplete. `route()` therefore passes `--router.optimizer.enabled=false --router.max_threads=1`.
  - It skipped Q2's diagonal PCM_D link even with the optimizer off, so that link is pre-routed (`PRE_ROUTED`).
  - Results still vary run to run: `gen_pcb.py` rebuilds and re-routes up to `BOARD_ATTEMPTS` times until nothing is unconnected. `--reuse-ses` re-imports an existing `kicad/shotpuck.ses` (git-ignored). Always trust KiCad DRC, not the router log.
  - It stalls when the DSN still holds the GND planes, so `signals_only()` strips the planes and GND pins before routing (`-inc` and `--router.ignore_net_classes` did not help).
  - The second pass writes its own `-pass2` files; routing back into the same `.ses` emptied it.
  - The router echoes the fan-out vias back in the `.ses`. `import_ses` used to drop echoes by rounding to 0.01 mm, so a via at y 3.474999 and its echo at 3.4750 ended up stacked (DRC `holes_co_located`). It now matches within `VIA_ECHO_TOL_MM` (0.01 mm).
  - `remove_dangling` sometimes misses a stub on the in-memory board that the reloaded board shows as dangling. `main()` therefore reloads the chosen board and runs `tidy()` (remove dangling tracks, fill, bridge islands) before DRC.
- **KiCad 10 Python, more:** `fp.Flip` before `board.Add` segfaults (add first, then flip). Delete tracks with `board.Delete(t)`; `board.Remove` through SWIG left `GetTracks()` broken.
- **KiKit annotation tabs:** a `kikit:Tab` footprint outside the board's bounding box + 1 mm is silently ignored (the notch raises the bbox bottom to −16.8 mm), and a tab that reaches no partition line is silently dropped. The origin must be outside the rim across the whole tab width. KiKit reads the `.kicad_pro` next to its input, so the temporary tabbed board is written beside the real one with a copy of its project and deleted afterwards.
- **PowerShell 5.1 `Set-Content -Encoding utf8` writes a BOM.** Edit sources with the Edit tool or Python instead. Wildcard `Remove-Item` is blocked by the harness.
- Long jobs (`gen_pcb.py` 1–5 min per attempt, up to 4 attempts; full sim ~5 min) run fine in the background; `gen_pcb.py` overwrites the board, so back it up if you need the old one.
- st.com and Mouser block downloads from this machine. Richard's copy of the datasheet (DocID032891 Rev 1) is at `C:\Users\rixar\SynologyDrive\Downloads\DS_lsm6dso32.pdf`; no PDF renderer is installed, so extract text with `pypdf` (installed in `C:\zp\.venv`).

## 8. Open items (blocking manufacture)

1. **Buy the cells:** plain LIR1254 (no tabs) from a maker with a datasheet; check the 4.20 V charge voltage and that 21 mA is within its standard charge current.
2. **Cell contacts:** choose or make the + spring and − strap (prototype: 0.15 × 2 mm nickel strip, as modelled in `mechanical/blender/cellconn.py`), and check them with the real cell.
3. **Bolt:** the Avalon bolt, longer by the puck height (10.43 mm) plus the sealing washer (about 12 mm); check the thread engagement in the riser.
4. **Real part masses** into `layout.json` (cell 1.9 g, USB-C connector 0.8 g, module 0.6 g are estimates; u-blox gives no BMD-340 mass), then re-run `puck.py` for the mass report.
5. **Back up the OTA signing key** (see §7). Losing it means updates only by cable; leaking it lets anyone who can pair install firmware.
6. **Richard's call:** R5/R6 (external I2C pull-up pads) were removed for routing space; put them back as DNP pads if he wants that fallback.
7. **O-rings:** buy 36, 37 and 38 × 1.0 (VMQ or NBR, 70 Shore A) for the cap seal and 2 × 1.0 for the screws; fit them on the first SLA cap and tune `seal.ledge_od`/`squeeze` (§6, Cap-to-plate seal).
8. **Before the JLC order:** ask JLCPCB support to confirm that C5456944 is BMD-340-A-R-10 (below), and place the order from `order/shotpuck-order-2026-09-30/ORDER.md` (form settings, notes and checks). Also buy the non-JLC parts: the tube (7.1 mm), a foam pad for the 1.6 mm gap above the cell, standoffs, M2 nylon-patch screws and Kapton. Build or buy a pogo jig for the bottom SWD pads (first flash).
(Done in the order round, 2026-09-30/10-01: PCB thickness settled at 1.2 mm; cap walls and screw holes to JLC3DP's minimums; C5 synced out of `design.py`, with the netlist check passing on the USB-C board; stale single-board fab files regenerated.)
(Done in v0.2: ERC runs in the flow; the LSM6DSO32 pinout, internal pin states and register values were checked against datasheet DocID032891 Rev 1; magnetic connector chosen (Samzo, Electrokit) with its drawing; cell pads made variant-independent; Varta's PCM and swell-space requirements met.)
(Done in rev A: flat plate + centre bolt, LIR1254 contacts and 21 mA charge, 2-layer re-route with 0 DRC, firmware rebuilt for the I2C swap, panel tabs moved off the notch.)

## 9. Known limitations / risks

- **Thresholds are unvalidated on real bows.** Tuning from logged EVENT data is the #1 on-device task (`docs/VALIDATION.md` §3). Captures now give the raw signals for it.
- **Battery life ≈ 3.5–5 weeks at 2 h/day is an estimate** (45–65 mAh; gyro + accel 0.55 mA whenever ACTIVE; idle ~17 µA estimated). Measure with JP1 cut. Richard chose the single LIR1254 knowing this; do not add gyro duty-cycling unless he asks. A further idle saving would be the accelerometer's ultra-low-power mode (datasheet §6.2.1; check wake-up support first).
- **IMU X/Y axes vs the bow are unconfirmed**; +Z is out of the cap. First capture on hardware fixes the mapping (VALIDATION §2).
- **Hard grab off the stand and stand knocks** are the false-positive sources in simulation.
- **Load-bearing but unverified assumptions:** nRF52840 VBUS wake from System OFF; MDBT50Q LFXO (Raytac: not fitted by default; we use the RC oscillator); BLE range through the PC cap next to the aluminium plate; I2C at 400 kHz on the nRF's internal pull-ups (~13 kΩ, estimated 130–200 ns rise on this short bus; there are no pads for external ones).
- **REG1 DC/DC:** Raytac's spec (MDBT50Q-1MV2 ver. K, §8) says the REG1 DC/DC inductor is inside the module, so REG1's DC/DC mode could be enabled in firmware to save active current. Not done yet (D5 kept LDO mode while this was unconfirmed).
- **VBUS detect and charger headroom on a weak supply:** the nRF52840 detects VBUS rising at 3.4–4.3 V and drops it only below 3.0–3.9 V. Detection happens at plug-in, before the MCP73831 starts (5 ms start delay), when D1 (BAT54J, max 320 mV at 1 mA) carries only a few hundred µA: from a 4.75 V supply VBUS reaches ~4.43 V, 0.13 V above the worst-case threshold. While charging (21 mA, D1 max ~0.46 V) VIN falls to ~4.29 V, far above the removal threshold. The tighter limit is the charger: MCP73831 accuracy is specified from VDD ≥ 5.2 V, so on a 4.75 V supply the charge may end slightly below 4.20 V. Use a 5.0–5.25 V charger; a lower-drop D1 would add margin.
- **Sustained overvoltage:** D3 and R9/C9 handle ESD and hot-plug spikes, not a 9–12 V adapter; that would need an overvoltage switch on VIN.
- **Stock (JLCPCB assembly, 2026-10-01, USB-C board):** all 21 BOM lines are in stock for 20 boards (5 panels). There are 10 extended parts; parts cost about $16 per board, most of it U1 and U2. Thinnest: U2 LSM6DSO32XTR C3663738 (177), DMN63D8LDW (244), BQ29700 (257), BMD-340 (322). Earlier swaps: U1 MDBT50Q-1MV2 (0 in stock) → BMD-340-A-R C5456944; D4 → C22470306, a second listing of the same XL-1005SYGC; U2 LSM6DSO32TR (dropped to 39) → XTR. LCSC's own shop stock differs and is not what PCBA uses. JLCPCB's search API (`selectSmtComponentList`, POST, JSON body `{"keyword": "<LCSC>"}`) returns live `stockCount`; EasyEDA's `https://easyeda.com/api/products/<LCSC>/components?version=6.4.19.5` returns the footprint JLC places.
- **BMD-340 type:** confirm with JLCPCB that C5456944 is BMD-340-A-R-10; -00 (nRF52840 rev 1) has an unusable high-voltage mode (README D14).
- **Captures and rejected candidates are RAM-only** (4 captures, 128 rejects). Accepted shots persist (~900 in flash).
- **Pairing window:** anyone within range during the 60 s after the charger is attached can pair. Acceptable because attaching the charger needs the puck in hand.
- **LED_BLINK (find-my-puck) blocks the main loop for ~1 s**, longer than the IMU FIFO (~0.5 s). Using it while shooting can drop a shot (FIFO overrun restarts the detector). Not fixed; it is meant for a puck lying around.
- **OTA is verified off-device only** (build, signatures, key guard). Upgrade, rollback-on-reset and rollback-on-hang must be tested on hardware (VALIDATION §2b). During the MCUboot swap (about 10–20 s) the puck is unavailable.
- **Firmware reads the FIFO word by word** (52 I2C transactions per watermark). A burst read would cut ACTIVE current; verify the LSM6DSO32 FIFO address roll-over first.
- **Material constraint:** PC cap + liquid threadlocker = stress cracking. Use nylon-patch screws only.
- **Mouse-bite tabs:** cut them with flush cutters, never snap (parts sit a few mm from the tabs; bending can crack joints or the 0603 C2), then sand the nubs flush; the board has 0.5 mm radial clearance in the cap cavity. The 3 mm side and bottom tabs and the 2.3 mm top tab have 5–6 bite holes each, within JLC's guide (3–4 mm tabs for 25–50 mm boards, ≥ 5 holes per set). The top tab can't grow much: H1 and the GND via at 80° sit either side. JLC publishes no 5 mm tab minimum.
- **JLCPCB part rotations** come from KiCad orientations plus `JLC_FOOTPRINT_OFFSETS` in `gen_jlc.py` (2026-09-30): each LCSC part's EasyEDA footprint (`https://easyeda.com/api/products/<LCSC>/components?version=6.4.19.5`) was fitted to our footprint by pad number. U3, Q1, Q2 need +270°, D4 +180° (JLC's pad 1 = cathode sits on the other side), D3 +180° (2026-10-01: JLC numbers the SMF5.0CA's pads the other way; bidirectional, so only the preview was wrong), U1 +2.0 mm along its x axis (JLC's origin is the pad-array centre, ours the body centre), J1 0.15 mm; all others match at 0°. With the offsets every JLC pad lands on our same-numbered pad (≤ 0.1 mm; the SOT-363 and SOD-123F land patterns differ by 0.15–0.29 mm in size, not position). Re-fit if a part or footprint changes, and still confirm JLC's placement preview.
- **Thin cap over the port:** 0.80 mm of cap top over the USB-C body, exactly JLC3DP's minimum SLA wall for a ~10 mm feature. The band under the port flat is 0.90 mm since the 1.2 mm board; it was 0.50 mm on the 0.8 mm board, where 0.5 mm is the minimum for ~5 mm features. Everything else is ≥ 0.73 mm on features under 5 mm (ray-cast scan, 2026-09-30). Check the roof on the first print. Keep `cap_top` ≥ 1.33 (and `OVERMOLD_CLEAR` ≤ 0.2 if the board ever goes back to 0.8 mm).
- **Hand edits on the board:** J1's notch, the GND via at (−0.41, 16.09), JP2, the silkscreen and the U2/C3/C6/C7 placement (moved inward from the top tab, 2026-10-01) are not generated. Re-running `gen_pcb.py` drops them; redo them by hand or teach `gen_pcb.py` the notch first.
- **Cell in the PCB notch:** the Kapton under the PCB must cover the plate under the cell (it insulates the + can from the plate). The cell is held only by the + spring, the − strap and the foam pad: shot shocks (8–40 g) must not lift a contact, or the puck browns out. Check for resets over a shooting session (VALIDATION §2). The contacts are not a bought part yet.
- **Bolt head near the antenna:** the steel button head (Ø16.7) and its Ø14 sealing washer sit on the cap top over the sleeve, about 4 mm above the PCB and 2.1 mm above the module, and reach about 8 mm from the axis in plan view, over the module's inner edge. Check BLE range on the bow (VALIDATION §2); a smaller washer or a plastic one would help.
- **Bolt tube:** it carries the whole clamp load (a 5/16 button head at its maximum torque, about 14 N·m, gives ~9 kN, ~400 MPa on the tube end; Richard's normal 3 N·m gives ~2 kN, 80–110 MPa), so it must be cold-drawn tube: annealed 304 yields at ~205 MPa. **The PC cap top is in the clamp path** (Richard's prototype test, D21): 80–110 MPa is at PC's compressive yield, so watch for creep, lost bolt preload and cracks around the bolt hole (VALIDATION §2). It stands 0.5 mm from the cell's + can with no FR-4 between them: keep the Kapton tape on it, all round, since the loose tube can turn. A touch is harmless on its own (the tube, plate and bow are not connected to the circuit).

## 10. Likely next requests and where to start

| Request | Start at |
|---|---|
| Order prototypes | README "Fabrication & assembly": PCB `kicad/fab/panel/shotpuck-panel-gerbers.zip` + `kicad/fab/jlc/*.csv` (J1 is JLC-assembled); cap `mechanical/out/cap.step` (SLA); plate `mechanical/out/plate.step` + `plate_drawing.pdf` (CNC 6061) or `plate_5052.step` + `plate_drawing_5052.pdf` (sheet metal, prototype); cell contacts hand-soldered, cell dropped in. The last order package (2026-09-30, with its checks) is `order/shotpuck-order-2026-09-30/ORDER.md` |
| Flutter integration | `docs/PROTOCOL.md`: *Pairing* (add-a-puck flow), "Recommended app sync", CAPTURE; `device_id` = DIS serial; upsert events and captures keyed by `(device_id, seq)`; EVENT payloads hold several events |
| Bow-movement metrics (cant, steadiness, rotation) | Compute in the app from captures first; move to firmware only once the useful metrics are known |
| Tune thresholds from real logs | Add the captured feature vectors (or raw captures) to `simulate.py` as a replay set; adjust `sd_default_config()`; re-run `--stress`; rebuild the hex |
| New firmware release | Bump `firmware/VERSION`, sysbuild with the signing key, re-merge `shotpuck_full.hex`, copy `zephyr.signed.bin` to `shotpuck_update.bin`, verify with `imgtool verify` |
| Cheaper/smaller variant | Mention the 601015 pouch cell (D6 alternative: closed-ring board, ~9.9 mm) and the chip-down nRF option; both need full mechanical + PCB regeneration |

Always finish by rebuilding everything affected, re-running the relevant checks (sim + unit tests PASS, netlist PASS, ERC 0 errors, DRC 0/0, sysbuild 0 compiler warnings, signed image verifies), and delivering the result (the repo on GitHub; a zip only if Richard asks).

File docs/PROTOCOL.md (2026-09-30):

# ShotPuck BLE protocol (v2)

v2 (compared with v1):
- CAPTURE characteristic (raw 6-axis bow motion around each shot) and the GET_CAPTURE opcode.
- **Pairing required** for everything in the ShotPuck service, with new pairings accepted only while the charger is attached (see *Pairing*). FORGET_BONDS opcode.
- Unique identity: the name carries a suffix, and the Device Information Service holds a serial number.
- EVENT notifications can carry several events.
- Accepted shots are stored in flash, so REPLAY works across resets.
- CONFIG carries `version = 2`. The COUNT, STATUS and single-event layouts are unchanged.

Source of truth: `firmware/src/protocol.h`. All multi-byte values are **little-endian**, structs are packed.

## Discovery and identity

- Advertised name: **`ShotPuck-XXXX`**, where `XXXX` is the last 4 hex digits of the serial number. The advertising data includes the service UUID below, so scan with a service filter.
- **Device Information Service** (0x180A), readable **without pairing**:
  - Serial Number String (0x2A25): 16 hex characters, the nRF52840's factory-unique device ID. **Use it as `device_id`** in the app and in PowerSync. It is identical on every phone; the iOS peripheral identifier is not.
  - Model Number String (0x2A24) `ShotPuck`, Firmware Revision String (0x2A26), e.g. `0.2.0+0` (from `firmware/VERSION`).
- The puck advertises while it is **ACTIVE** (from motion wake until 30 s of stillness, plus a 120 s linger) and while its **pairing window** is open. A puck lying still in a bag is invisible, so pick up the bow to make it connectable.
- One connection at a time.
- **MTU:** a single event is 24 bytes, so the ATT MTU must be at least 27. The puck requests 247 on connect (and supports LE data length extension). A larger MTU makes transfers faster: up to 10 events or 19 capture samples per packet at MTU 247. flutter_blue_plus on Android requests 512 by default. On iOS the MTU is negotiated automatically (185+).

## Pairing

Everything in the ShotPuck service needs an **encrypted link**, which a phone only gets by pairing (bonding) with the puck. Reading COUNT, CONFIG or STATUS, subscribing to any notification, and writing CONTROL or CONFIG all fail without it (ATT "insufficient encryption/authentication"). The Device Information Service and the standard Battery Service stay open.

- **Pairing window:** the puck accepts a *new* pairing only for **60 s after the charger is attached** (also after a boot with the charger attached). The LED blinks once a second while the window is open, and blinks twice when a phone has paired. Outside the window, pairing requests are rejected. Phones that are already paired reconnect and encrypt at any time.
- **Charger LED** (after the pairing window, while the charger stays attached; `firmware/src/chg_led.c`): one short blink every 2 s while charging; **steady on** when the charger reports done and the cell reads ≥ 4.10 V; three quick blinks every 2 s when charging is paused by the temperature gate; dark if the charger is attached but neither charging nor full (no input power or a fault). The steady LED starts only after the MCP73831 has terminated, so its ~1 mA never holds the charge current above the termination threshold. It slowly drains the cell; when the charger tops up (below its recharge threshold), the LED blinks again until done. STATUS carries the same state (`SP_ST_VBUS`, `SP_ST_CHARGING`, `SP_ST_CHG_INHIBIT`).
- **Factory reset (reset pads JP2, cap off):** bridge the two round pads beside the module with tweezers. The LED lights while they are bridged (within about 2 s); held for 5 s, it blinks 5 times fast, the puck erases its settings, pairings, shot count and shot log, and reboots. Only a bridge made while the puck runs counts: pads already shorted at boot do nothing until released. The firmware erases the same data by itself after 3 crash or watchdog resets in a row, each within a minute of boot. Phones must forget the puck and pair again (through the charger window).
- Method: LE Secure Connections, "Just Works" (no PIN). iOS and Android show their standard pairing prompt.
- Up to **4 phones** can be paired. Pairing a 5th replaces the one paired longest ago.
- **FORGET_BONDS** (CONTROL `0x07`, from a paired phone) removes all pairings, including the caller's, and disconnects. Use it when giving the puck away.

App flow for adding a puck:
1. Scan for the service and list pucks (`ShotPuck-XXXX`, sorted by signal strength).
2. Connect and read the DIS serial number.
3. Ask the user to attach the charger, then trigger pairing. On Android, call `createBond()`. On iOS, read an encrypted characteristic such as COUNT, which makes iOS pair.
4. Store the serial as this user's puck. From then on, connect only to that serial and use it as `device_id`.

If pairing fails with "pairing not allowed", the window was closed: ask the user to reattach the charger.

## Service `7a1e0001-5b0c-4f3a-9c6e-3a5d2b9e0a01`

| UUID (7a1e00XX-…) | Name | Props | Payload |
|---|---|---|---|
| `…0002…` | COUNT | read, notify | `uint32 total`, `uint32 last_seq` (8 B) |
| `…0003…` | EVENT | notify | 1–10 × `sp_event_t` (24 B each), below |
| `…0004…` | CONTROL | write | opcode + payload, below |
| `…0005…` | CONFIG | read, write | `sp_config_t` (19 B), below |
| `…0006…` | STATUS | read, notify | `sp_status_t` (7 B), below |
| `…0007…` | CAPTURE | notify | capture packets (header + data), below |

All six require a paired (encrypted) link.

### EVENT: every candidate, accepted or not

Each notification carries **one or more events back to back** (length = 24 × n, n ≤ 10). Always loop over the payload in 24-byte steps.

| Offset | Type | Field | Notes |
|---|---|---|---|
| 0 | u32 | seq | Monotonic across reboots (not reset by RESET_COUNT) |
| 4 | i64 | t_unix_ms | 0 if the phone had not sent SET_TIME since the puck booted |
| 12 | u32 | t_uptime_ms | Device uptime at the trigger |
| 16 | u16 | peak_hf_mg | Release shock (saturates about 32 g) |
| 18 | u16 | pre_still_ms | Stillness before the trigger |
| 20 | u16 | post_lf_mg | Bow motion after release |
| 22 | u8 | accepted | **1 = counted as a shot** |
| 23 | u8 | reason | 0 ok, 1 not still before, 2 no follow-through |

Rejected events are sent on purpose. Log them in the app during tuning: they are the data you need to set thresholds (see VALIDATION.md).

Events are sent live as they happen, and again on REPLAY. Replayed and live events can interleave and repeat, so order by `seq` and upsert.

### Storage on the puck

| Data | Where | Kept |
|---|---|---|
| Accepted shots | Flash log | about the last **900–1000 shots**; survives resets, battery cut-off and normal re-flashing (not a full-chip erase) |
| Rejected candidates | RAM | the last 128; lost on reset |
| `total`, `seq`, CONFIG, pairings | Flash (settings) | permanently |
| Captures | RAM | the last 4 shots; lost on reset |

### CONTROL opcodes

| Byte 0 | Payload | Effect |
|---|---|---|
| `0x01` SET_TIME | i64 unix_ms | Sets the wall clock. Send on every connect. |
| `0x02` RESET_COUNT | – | total = 0 (seq keeps counting) |
| `0x03` REPLAY | u32 from_seq | Re-sends stored events with seq ≥ from_seq: accepted shots from flash, then rejected candidates from RAM, batched on EVENT |
| `0x04` FACTORY_CFG | – | Restores default thresholds |
| `0x05` LED_BLINK | – | 5 blinks (find the puck) |
| `0x06` GET_CAPTURE | u32 seq | Re-sends the capture of shot `seq` on CAPTURE (header with `n_samples = 0` if it is no longer held) |
| `0x07` FORGET_BONDS | – | Removes all pairings (see *Pairing*) |

A REPLAY of the whole flash log (about 1000 events) takes roughly 10–20 s at MTU 247. It runs in the background: live shots are still detected and sent first.

### CAPTURE: bow motion around each shot

For every **accepted** shot the puck records the raw accelerometer and gyroscope from **1.0 s before to 0.5 s after the release trigger** (624 samples at 416 Hz). When the phone is subscribed to CAPTURE, the puck streams it automatically right after the shot's EVENT: one header packet, then data packets until all samples are sent. The last **4 captures are kept in RAM** and can be fetched again with GET_CAPTURE. Rejected candidates are not captured.

Byte 0 of every packet is the packet type.

**Header** (`sp_cap_header_t`, 15 B):

| Offset | Type | Field | Notes |
|---|---|---|---|
| 0 | u8 | type | `0x01` |
| 1 | u32 | seq | Same `seq` as the shot's EVENT |
| 5 | u16 | n_samples | 624, or **0 if the capture is not available** |
| 7 | u16 | trigger_index | Sample index of the release trigger (416) |
| 9 | u16 | odr_hz | 416 |
| 11 | u16 | acc_ug_per_lsb | 976 (±32 g) |
| 13 | u16 | gyro_mdps_per_lsb | 70 (±2000 dps) |

**Data** (`sp_cap_data_t`, 7 B, then samples):

| Offset | Type | Field | Notes |
|---|---|---|---|
| 0 | u8 | type | `0x02` |
| 1 | u32 | seq | |
| 5 | u16 | first | Index of the first sample in this packet |
| 7 | 12 B × k | samples | `i16 ax, ay, az, gx, gy, gz`, raw LSB; k = (MTU − 3 − 7) / 12 |

Convert with `acc_mg = raw × acc_ug_per_lsb / 1000` and `gyro_dps = raw × gyro_mdps_per_lsb / 1000`. Sample `i` is at `(i − trigger_index) / odr_hz` seconds from the trigger, so the EVENT's `t_unix_ms` lines up with index `trigger_index`.

- **Axes** are the LSM6DSO32's own axes. +Z points out of the cap (it reads about +1000 mg with the puck lying cap-up). The X/Y mapping to the bow is fixed by the mounting and must be confirmed once on hardware (VALIDATION.md §2).
- A transfer takes about 1–3 s at MTU 247. Packets arrive in order. If a `first` is missing (disconnect), discard the capture and request it again with GET_CAPTURE.
- A shot less than 1.0 s after the puck woke up has no capture (header `n_samples = 0`), because there is not enough pre-trigger data. The IMU also needs a few tens of ms after a wake before the gyroscope delivers data (datasheet turn-on time 35 ms), so a shot just over 1.0 s after waking can have zero gyro values in its first samples.

### CONFIG (`sp_config_t`, 19 B)

`u8 version(=2)`, then u16 each: `trig_hf_mg` (1000–30000, default 6000), `move_mg` (50–2000, 300), `pre_still_min_ms` (0–10000, 500), `post_start_ms` (100), `post_end_ms` (≤1500, 600; must be greater than start), `post_lf_min_mg` (0–5000, 250), `refractory_ms` (200–10000, 1500), `wake_mg` (16–2000, 150), `idle_timeout_s` (5–3600, 30).

Out-of-range writes are rejected with ATT error 0x13 (value not allowed). Accepted values are persisted.

### STATUS (`sp_status_t`, 7 B)

`u8 battery_pct`, `u16 battery_mv`, `i8 temp_c`, `u8 flags`, `u8 fw_major`, `u8 fw_minor`.
Flags: bit0 VBUS (cable present), bit1 CHARGING, bit2 CHG_INHIBIT (too cold or hot to charge), bit3 ACTIVE, bit4 TIME_SET.

## Recommended app sync (PowerSync-friendly)

1. Connect only to the user's own puck (its stored serial). The link encrypts automatically because the phone is paired.
2. Request MTU 247 or more, and subscribe to COUNT, EVENT, STATUS and CAPTURE.
3. Write SET_TIME.
4. Read COUNT, then write `REPLAY(last_seq_seen_by_app + 1)`. The app owns this position; the puck keeps no per-phone sync state, so any number of phones can sync.
5. Upsert events keyed by `(device_id, seq)`, with `device_id` = DIS serial number. seq is monotonic, so replays and duplicates are harmless.
6. Stay connected during the end. Each shot arrives as an EVENT with `accepted = 1` about 0.6 s after release (the follow-through window), followed by its CAPTURE.
7. Store captures keyed by `(device_id, seq)` as well. For accepted events without a complete capture, write `GET_CAPTURE(seq)`: the puck still holds the last 4.

Map shots to ends in the app: the puck has no notion of ends or arrows-per-end, and seq gaps are not errors.

## Firmware update (OTA)

The puck runs **MCUboot** and exposes the standard **MCUmgr SMP** service, so no custom update protocol is needed.

- SMP service `8D53DC1D-1DB7-4CD3-868B-8A527460AA84`, characteristic `DA2E7828-FBCE-4E01-AE9E-261174997C48`. It requires the same encrypted (paired) link as everything else.
- In the Flutter app, use Nordic's **`mcumgr_flutter`** plugin (wraps the iOS/Android nRF Connect Device Manager libraries) with the file `shotpuck_update.bin`. The nRF Connect Device Manager app works for manual updates.
- Recommended mode **Test and confirm**: upload (roughly 20–40 s at MTU 247), mark as test, reset. MCUboot then swaps the images (the puck is unavailable for about 10–20 s), the new version boots and advertises, and the phone reconnects and confirms it.
- The puck also confirms a new image by itself once a paired phone has connected over an encrypted link and the image has run 10 s. Reconnect and pair (encrypt) after the OTA reset; until then the image stays on trial. If the new image crashes or hangs before that (the watchdog resets a hang after 10 s), MCUboot **rolls back** to the previous version on the next boot.
- Only images signed with the ShotPuck private key are accepted: MCUboot checks the ECDSA-P256 signature before it boots anything.
- Check the result with the DIS Firmware Revision String or STATUS `fw_major`/`fw_minor`. SMP `image list` shows both slots with their versions and flags.
- Shots, counts, config and pairings are kept across updates (separate flash partitions).

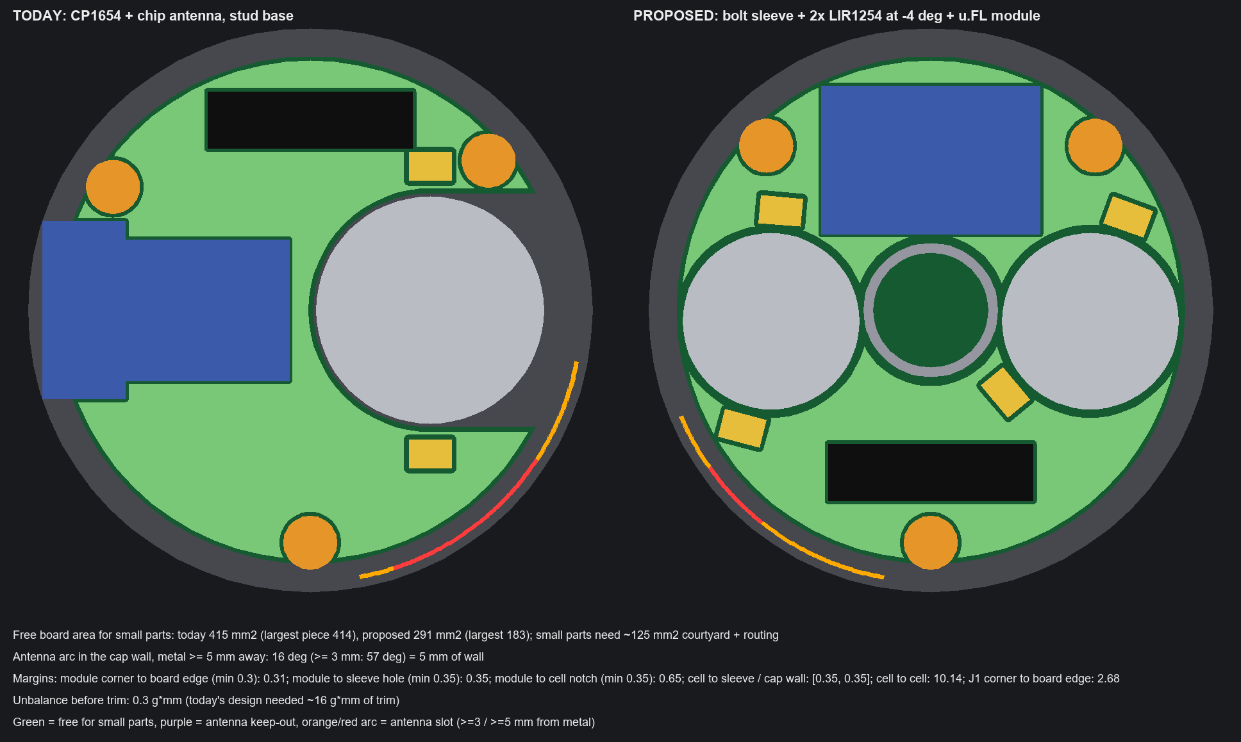
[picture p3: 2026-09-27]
mechanical/out/feasibility/two_cell_feasibility.png

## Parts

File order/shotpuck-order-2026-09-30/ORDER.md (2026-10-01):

# ShotPuck rev A: order package, 2026-09-30

USB-C board (`main` at 36e9f82: the fab fixes of 2026-09-30 and the 2026-10-01 changes listed at the end). Three JLC services, one folder each. Stock and prices are JLC's live figures from 2026-09-30.

| Folder | Service | Upload |
|---|---|---|
| `1_PCB_JLCPCB` | JLCPCB PCB + Standard PCBA | `shotpuck-panel-gerbers.zip`, then `shotpuck-panel-bom.csv` + `shotpuck-panel-cpl.csv` |
| `2_Plate_JLCCNC/A_sheet-metal_5052_prototype` | JLCCNC Sheet Metal (recommended for prototypes) | `plate_5052.step`, drawing `plate_drawing_5052.pdf` as the thread file |
| `2_Plate_JLCCNC/B_cnc_6061` | JLCCNC CNC Machining (production material) | `plate.step`, drawing `plate_drawing.pdf` |
| `3_Cap_JLC3DP` | JLC3DP SLA resin | `cap.step` (`cap.stl` if the STEP upload fails) |

Upload the panel files above, not `hardware/kicad/fab/shotpuck-gerbers.zip` / `shotpuck-pos.csv` / `shotpuck-bom.csv`. Those are regenerated for this board (2026-10-01) but are the single board, for reference only.

## Before you order

1. **Ask JLCPCB support** to confirm that C5456944 is type **BMD-340-A-R-10**; types -00/-01 do not work in high-voltage mode (README D14).
2. U2 is now the **LSM6DSO32XTR (C3663738)**, 177 in stock; the LSM6DSO32TR was down to 39 for the 20 needed. It is the LSM6DSO32 plus a machine-learning core we leave off: same package, pinout, JLC footprint (pad for pad) and registers, so the gerbers, CPL and firmware are unchanged.
3. Quantities for the plate and the cap are your call. Suggestion: 5 of each first, so you can fit the O-rings and tune the seal before printing more.

## 1. PCB + assembly (JLCPCB)

| Setting | Value |
|---|---|
| Layers / material | 2, FR-4 |
| Dimensions | 91.1 × 92.7 mm (read from the gerbers) |
| PCB qty | 5 (panels) = 20 boards |
| Delivery format | Panel by Customer, 1 design (2×2 inside, frame, tooling holes and fiducials already in) |
| Thickness / finish | **1.2 mm** / ENIG |
| Copper / via covering | 1 oz / Tented |
| Min via hole | 0.3 mm (no surcharge) |
| Order number / marking | Leave the default, **no mark** (or a 2D barcode on the rail for traceability). Do **not** pick "Specify a location": JLC stopped printing order numbers in May 2026, and the panel no longer carries `JLCJLCJLCJLC` |
| PCBA type | **Standard** (Economic X-rays BGAs only; U1 is an LGA) |
| Assembly side / PCBA qty | Top / 5 |
| Tooling holes | Added by customer |
| Confirm parts placement | Yes |

Note for the order: *"Please X-ray U1 (BMD-340, LGA) and U2 (LGA-14). J1 is a mid-mount USB-C in a board-edge notch; its front sticks out 1.3 mm past the board edge into the routed gap. BT1, J2, JP1 and JP2 are not assembled."*

**CPL corrections (new).** JLC places its own EasyEDA footprint of each LCSC part at the CPL position and rotation. Several of those footprints differ from ours, so `gen_jlc.py` now corrects them:

| Part | Correction | Without it |
|---|---|---|
| U1 BMD-340 | centroid +2.0 mm (JLC's origin is the pad-array centre) | placed 2.05 mm off |
| U3 MCP73831 | +270° | pins 2.1 mm off (turned 90°) |
| Q1, Q2 SOT-363 | +270° | pins 1.7 mm off |
| D4 LED | +180° | fitted backwards (JLC's pad 1 is the cathode, on the other side) |
| D3 SMF5.0CA | +180° | pads swapped (JLC numbers them the other way). Harmless, since the TVS is bidirectional, but the preview showed its pin 1 at the opposite end from our silkscreen |
| J1 USB-C | centroid 0.15 mm | pins 0.15 mm off |

A placement simulation of all 112 placements puts every JLC pad on our same-numbered pad. Most land within 0.1 mm. SOT-363 is within 0.27 mm and SOD-123F within 0.29 mm; those are land-pattern size differences, not placement errors. JLC's placement preview should now look right; confirm it anyway.

**Parts (20 boards):** all 21 lines are in stock, with 10 extended parts (~$3 setup each). The parts cost about $323, or $16 per board, of which U1 is $171 and U2 $98. The thinnest stock (2026-10-01) is U2 (177), Q1 DMN63D8LDW (244), U4 BQ29700 (257) and U1 (322).

| Check against JLC 1–2 layer capabilities | Design | JLC limit | |
|---|---|---|---|
| Track / clearance | 0.15 / 0.127 mm | 0.10 / 0.10 | OK |
| Via hole / pad (ring) | 0.30 / 0.55 mm (0.125) | 0.15 / 0.25 (0.05) | OK |
| Via hole to hole | 0.41 mm | 0.20 | OK |
| NPTH (mouse bites, J1 legs, tooling, screws) | 0.50 / 0.70 / 2.0 / 2.4 mm | ≥ 0.5 | OK |
| Copper to outline | ≥ 0.30 mm (rule) | 0.20 | OK |
| Mask web | none under 0.10 mm | 0.10 | OK |
| Vias in SMD pads | none | – | OK |
| Board spacing / mouse bites | ≥ 2.5 mm / Ø0.5 at 0.8 mm | ≥ 2 mm / Ø0.5–0.8 | OK |
| Mouse-bite tabs | sides, bottom 3 mm with 5–6 holes; top 2.3 mm with 5 holes; Ø0.5 at 0.8 mm (0.3 mm gap) | 3–4 mm for 25–50 mm boards; ≥ 5 holes per set, Ø0.6 with a 0.35–0.4 mm gap (min 0.3); ≥ 2 sets | OK (hole gap at the minimum) |
| Panel size (Standard PCBA) | 91.1 × 92.7 mm | ≥ 70 × 70, ≤ 250 × 250 | OK |
| Thickness 1.2 mm + ENIG (gerber job file says 1.2) | 1.2 | offered | OK |
| Silkscreen line / text height | board artwork 0.2 mm (fixed); KiCad footprint outlines 0.12 mm, D4 0.10 mm; "RST" 0.8 mm | ≥ 0.15 / ≥ 1.0 | Footprint outlines and "RST" below guideline: cosmetic, may print faint |
| Inner corners (router Ø1.0 mm) | panel milled with 0.5 mm radius, the same as the board's J1 notch fillets | ≥ R0.5 | OK |

Also verified: KiCad 10 DRC 0/0 on the board and the panel, 0 schematic-parity issues; the panel was regenerated from the board with your silkscreen fix (2026-09-30 21:01) and holds four exact copies of it; BOM/CPL regenerate from the panel unchanged. The gerbers now carry separate `-PTH.drl` / `-NPTH.drl` files, as JLC asks, and the silkscreen is clipped at the mask. Each comes with a `-drl_map.gbr` drill map (added 2026-10-01; the drill files themselves are unchanged).

## 2. Base plate (JLCCNC)

You allowed a cheaper prototype material. JLCCNC's sheet-metal service stocks only aluminium **5052**; 6061 is only available as CNC machining. For a flat laser-cut part, sheet metal is normally much cheaper, and both services quote instantly after upload.

**A, prototype (recommended):** Sheet Metal → Aluminum 5052, 2.0 mm, laser cut, no bending, finish none. Threads: **Yes**, upload `plate_drawing_5052.pdf` (4× M2×0.4 through at H1–H4). JLC does not publish an M2 tapping minimum for sheet metal; its riveting range starts at M2.5. If the form will not take M2, order the Ø1.6 holes plain and tap them by hand (M2×0.4 tap; 5052 taps easily). The 0.3 mm underside chamfer is left off, because a laser cannot cut it and the STEP must be a flat sheet. Deburr the edges by hand.

**B, production material:** CNC Machining → Aluminum 6061, as machined. Threads: **Yes**, upload `plate_drawing.pdf`. The tolerance is ISO 2768-m, which is JLC's default.

| Check | Design | JLC rule | |
|---|---|---|---|
| Size | Ø40 × 2.0 mm | sheet ≤ 800 mm; CNC warping warning only below 10 × 10 × 1 | OK |
| Holes | Ø1.6 (tap drill) ×4, Ø8.4 | sheet: ≥ max(t/2, 1 mm) = 1.0 | OK |
| Hole to rim / to hole | 2.70 mm / ≥ 11 mm | sheet ≥ 1 mm; CNC wall ≥ 0.8 | OK |
| Tapped holes | STEP has the Ø1.6 tap drill, drawing calls out M2×0.4 | CNC: model the tap drill, call out the thread in a 2D drawing | OK |
| Thread length | 2.0 mm through | ≤ 3 × D | OK |
| Geometry | matches `layout.json` to 0.000 mm | – | OK |

5052-H32 (yield ~190 MPa) takes the tube end at your 3 N·m (~85 MPa); at the bolt's maximum torque both alloys yield, as before. Tighten the M2 screws gently (≈ 0.1–0.15 N·m).

## 3. Cap (JLC3DP)

SLA, **8001 Resin, Translucent**. The Transparent grade is sanded and oil-sprayed by default, which changes the O-ring ledge and port-seal fits; Translucent is only de-supported, and the LED still shows through. Note for the order: *"The thinnest wall is at your SLA minimum (0.80 mm top over the side-port pocket); please print as modelled. Please keep support marks off the stepped bottom rim and the side port hole."*

| Check | Design | JLC3DP SLA guideline | |
|---|---|---|---|
| Model | 1 valid solid, 40 × 40 × 8.43 mm, 2.72 cm³; STL matches | min 5 × 5 × 5 mm | OK |
| Walls: top 1.33, side 1.5 mm | 1.33 / 1.5 | 1.0 for a ~50 mm part | OK |
| Band under the port flat, over the seal O-ring | 0.90 mm (was 0.45) | 0.5 for a 5 × 5 feature | OK |
| Cap top over the USB-C pocket | 0.80 mm, ~9 × 7 mm (was 0.67) | 0.8 for a 10 × 10 feature | OK (at the minimum) |
| Port-flat ends, counterbore rings, tube lip | 0.73–0.8 mm, features < 6 mm | 0.5 (5 × 5); fasteners ≥ 1.5 recommended | OK |
| Screw holes / counterbores | Ø2.4 for M2 (0.2/side, was Ø2.2), Ø4.2 for Ø3.8 heads (0.2/side); boss collar 0.7 mm | assembled clearance ≥ 0.2; holes ±0.3; wall 0.5 (5 × 5) | OK |
| Port seal squeeze | 0.15 mm per side | tolerance ±0.2 mm | Fit depends on the print (tune `connector.seal_squeeze`) |
| Enclosed cavities | none | escape holes only for closed cavities | OK |
| Heat | 8001 HDT 53 °C | – | Prototype only; don't leave it in a hot car |

## 4. Not in this package (buy separately)

O-rings 36/37/38 × 1.0 and 2 × 1.0 (VMQ/NBR 70A); 4× M2×8 cheese head, nylon patch; 4× M2 spacers 3 mm (OD 4); 304 tube Ø10 × 0.8, cut to 7.1 mm; a foam pad for the 1.6 mm gap above the cell; Kapton; LIR1254 cells; 0.15 × 2 mm nickel strip; the 5/16-24 button head bolt and bonded washer (README "Needs your input").

## 5. Risks to check on the first boards

- **J1 fit in the notch.** LCSC's 3D model reaches 0.03 mm past our notch's back wall. Its leg roots also touch the board top beside the Ø0.70 holes (0.3 mm deep); LCSC's own footprint puts those holes 0.095 mm closer to the pads. (The panel used to round the notch's back corners to 1.0 mm; it now uses JLC's 0.5 mm, the board's own fillet.) All of this is within the model's accuracy and JLC's ±0.2 mm outline tolerance, but if J1 does not sit flat, look here first.
- Silkscreen is below JLC's line/text minimums (see above). It is cosmetic.
- The cap's fits, as above. Its roof over the USB-C pocket sits exactly at JLC's minimum: check it on the first print.

Changes on 2026-09-30: to meet JLC's minimums, the cap top went 1.2 → 1.33 mm and the plug-overmold clearance 0.25 → 0.20 mm. Then the PCB went 0.8 → 1.2 mm on the same 3 mm standoffs, and the ceiling and cap rose 0.4 mm with it. The puck is now 10.43 mm and 16.72 g, the tube 7.1 mm and the bolt about 0.5 mm longer than planned, with 1.6 mm free above the cell. Nothing new overlaps the plate, board, module or USB-C model; the only overlap is still the 2.1 mm³ seal-ring squeeze, and the largest USB-C plug overmold clears by 0.20 mm.

Changes on 2026-10-01: U2 → LSM6DSO32XTR (see above); C5 removed from `design.py` (it was already off the board), so the netlist check passes; the stray off-board silkscreen text is deleted; the cap's screw holes are Ø2.4. The board, panel, gerbers, BOM/CPL and cap in this package were regenerated and re-checked: DRC 0/0 on board and panel, 0 parity issues, ERC 0 errors, panel = 4 exact copies, placement simulation passes, cap walls ≥ JLC's minimums.

Later on 2026-10-01:
- **J1's wing-tab pads were enlarged** from 0.99 to 2.0 mm² each, with 0.86 mm² under the tab (was 0.61) and room for solder fillets at the tab's outer edge and ends. They stay 0.31 mm from the notch and 0.25 mm from the leg holes.
- **D3 got a +180° CPL correction** (table above).
- **Regenerated:** the board, panel, gerbers and CPL in this package. Board DRC: 0/0, 0 parity issues. Panel DRC: 0/0 on three runs. The panel is still four exact copies of the board. Compared with the previous panel, only the front copper, mask and paste changed, all within 1.7 mm of J1's tabs. The BOM is unchanged, and the placement simulation still passes.
- **Fiducials moved to 3.85 mm from the rail edge** (was 2.5 mm), as JLC asks. Same size (1 mm copper, 2 mm opening), still 5 mm from the side, and the opening stays on the 5 mm rail. Regenerated: the panel and `shotpuck-panel-gerbers.zip`. Panel DRC: 0/0 on two of three runs; the other run showed only the known frame-corner outline artefact. Only the six fiducial flashes changed (copper, mask, silkscreen clearance); drill, outline, paste, zone fills, BOM and CPL are unchanged.
- **Tooling holes enlarged to Ø2.0 mm** (was 1.152 mm), as JLC prefers. Still three, 2.5 mm in from both rail edges; each hole's wall is 1.5 mm from the panel edge and 0.84 mm from the nearest fiducial's mask opening. Regenerated: the panel and `shotpuck-panel-gerbers.zip`. Panel DRC: 0/0 on two of three runs; the other run showed only the known frame-corner outline artefact. Only the three tooling holes changed (NPTH drill, mask, silkscreen clearance); outline, copper, paste, BOM and CPL are unchanged.
- **U2 moved 0.9 mm inward, away from the top tab** (Richard, by hand), with C3, C6 and C7 and their tracks. Its courtyard is now 1.1 mm from the tab's mouse bites (was 0.34 mm; JLC suggests 1.5 mm). **The top tab is 2.3 mm wide** at x = +0.8 (was 1.5 mm at +1.2), so it has 5 holes like the others, as JLC asks; the GND via stays 0.36 mm from the bites and H1's courtyard is 0.29 mm away. Regenerated: the panel, `shotpuck-panel-gerbers.zip` and the CPL. Board DRC: 0/0, 0 parity issues. Panel DRC: 0/0 on 8 of 8 runs (with the outline fix below). In the CPL only U2, C3, C6 and C7 moved (rotations unchanged); the BOM is unchanged.
- **The panel outline's intermittent DRC error is fixed.** KiKit left 9 outline segments shorter than 10 µm: one at the frame's top-left corner, the rest where tabs meet the 0.5 mm milling fillets. KiCad joins outline segments within a small tolerance, and these most likely made it close the frame wrongly on some runs ("self-intersecting outline"). `gen_panel.py` now merges them into their neighbours (the outline moves ≤ 4 µm) and refills the pours. Regenerated: the panel and `shotpuck-panel-gerbers.zip`. Pads, drill and drawings are unchanged; the GND pours differ by about 0.01 mm² per board.
- **The `JLCJLCJLCJLC` text is removed from the top rail.** JLC's marking page says order numbers are no longer available since May 2026 and asks not to add that text; left in, it would print literally on the frame. `gen_panel.py` no longer adds it. Regenerated: the panel and `shotpuck-panel-gerbers.zip`. Panel DRC: 0/0 on three runs. Compared with the previous panel, only that 15.2 × 1.8 mm piece of front silkscreen is gone; copper, mask, paste, outline and drill are geometrically identical, and the BOM and CPL are unchanged.
- **Package re-checked against `main` at 36e9f82.** Gerbers, drill files and drill maps exported fresh from the panel match `shotpuck-panel-gerbers.zip` exactly, timestamps aside. `gen_jlc.py` regenerates the BOM and CPL byte for byte. All four panel copies carry the moved U2, C3 and C7, and no `JLCJLCJLCJLC` text. The plate and cap files are identical to `mechanical/out`, and no plate dimension in `layout.json` has changed since the plate drawings were made.

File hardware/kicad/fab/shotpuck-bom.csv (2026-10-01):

Qty | References | Value | Footprint | Manufacturer | MPN | DNP
1 | BT1 | LIR1254 (plain, spring contacts) | LIR1254_Contacts_Edit | generic | LIR1254 3.6-3.7 V 45-65 mAh, no tabs - pick a maker with a datasheet
1 | C1 | 4.7u 10V | C_0603_1608Metric | Murata | GRM188R61A475KE15D
1 | C2 | 10u 10V | C_0603_1608Metric | Samsung | CL10A106KP8NNNC
2 | C3 C4 | 4.7u 6.3V | C_0402_1005Metric | Murata | GRM155R60J475ME47D
4 | C6 C7 C8 C9 | 100n | C_0402_1005Metric | Murata | GRM155R71C104KA88D
2 | D1 D2 | BAT54J | D_SOD-323F | Nexperia | BAT54J,115
1 | D3 | SMF5.0CA | D_SOD-123F | Littelfuse | SMF5.0CA (second sources: MDD / FUXINSEMI SMF5.0CA)
1 | D4 | LED yellow-green 0402 | LED_0402_1005Metric | XINGLIGHT | XL-1005SYGC (AlGaInP 572 nm, Vf ~2 V)
1 | J1 | TYPE-C 6PFS 2JCB1.6-H6.7 IPX8 | USB_C_Receptacle_ShouHan_TYPE-C-6PFS-2JCB1.6-H6.7_IPX8 | SHOU HAN | waterproof USB-C 6P power-only (LCSC C3020041)
1 | J2 | SWD pads | SWD_Pads_1x4_P2.54 | - | 4 bottom test pads (VDD, SWDIO, SWDCLK, GND) at 2.54 mm: program with a 4-pin pogo jig
1 | JP1 | I_MEAS (cut to measure) | SolderJumper-2_P1.3mm_Bridged_Pad1.0x1.5mm
1 | JP2 | RESET pads | TweezerPads_2x0.8mm_Gap0.4mm | - | 2 bare top pads (BTN, GND), copper only: bridge with tweezers for a factory reset
1 | Q1 | DMN63D8LDW | SOT-363_SC-70-6 | Diodes Inc | DMN63D8LDW-7
1 | Q2 | DMN2004DWK | SOT-363_SC-70-6 | Diodes Inc | DMN2004DWK-7
1 | R1 | 47k 1% | R_0402_1005Metric | UNI-ROYAL | 0402WGF4702TCE
2 | R10 R11 | 5.1k 1% | R_0402_1005Metric | UNI-ROYAL | 0402WGF5101TCE
1 | R2 | 1M | R_0402_1005Metric | Yageo | RC0402FR-071ML
1 | R3 | 100k | R_0402_1005Metric | Yageo | RC0402FR-07100KL
2 | R4 R9 | 1k | R_0402_1005Metric | Yageo | RC0402FR-071KL
1 | R7 | 330R | R_0402_1005Metric | Yageo | RC0402FR-07330RL
1 | R8 | 2.2k | R_0402_1005Metric | Yageo | RC0402FR-072K2L
1 | U1 | BMD-340-A-R | u-blox_BMD-340 | u-blox | BMD-340-A-R-10
1 | U2 | LSM6DSO32XTR | LGA-14_3x2.5mm_P0.5mm_LayoutBorder3x4y | STMicroelectronics | LSM6DSO32XTR
1 | U3 | MCP73831T-2ACI/OT | SOT-23-5 | Microchip | MCP73831T-2ACI/OT
1 | U4 | BQ29700DSER | WSON-6_1.5x1.5mm_P0.5mm | Texas Instruments | BQ29700DSER

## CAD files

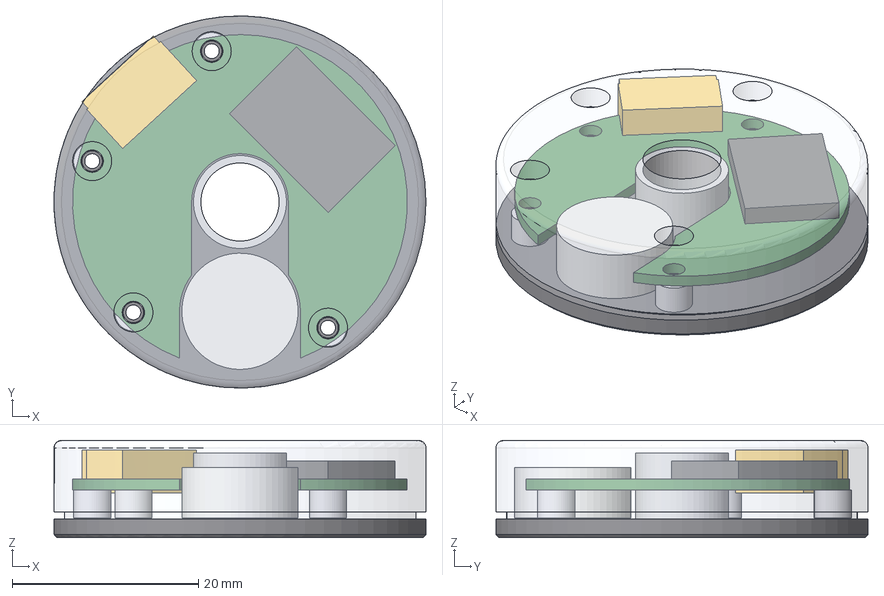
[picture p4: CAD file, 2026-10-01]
mechanical/out/assembly.step
40.0 x 40.0 x 10.4 mm
plate
standoffs
cap
pcb
sleeve
cell
module
connector

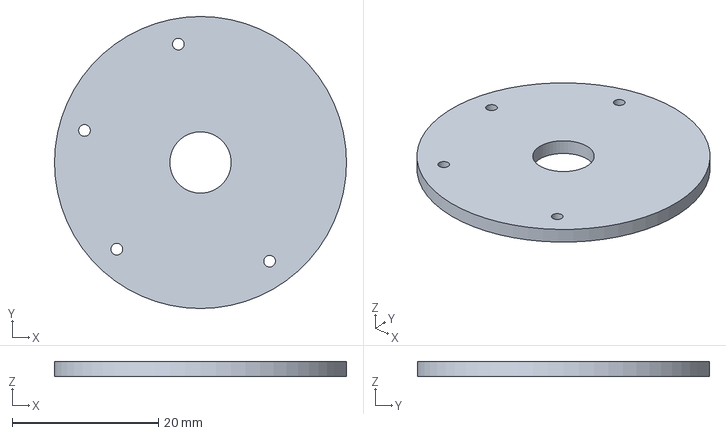
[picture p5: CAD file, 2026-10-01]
order/shotpuck-order-2026-09-30/2_Plate_JLCCNC/A_sheet-metal_5052_prototype/plate_5052.step
40.0 x 40.0 x 2.00 mm

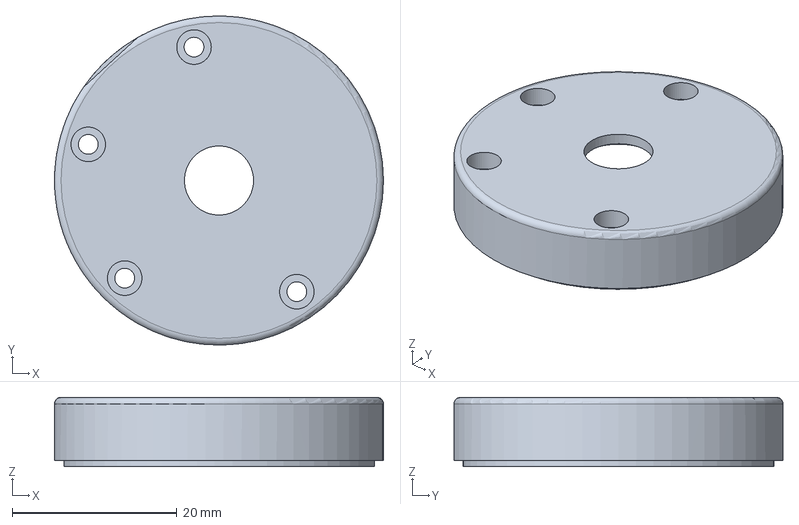
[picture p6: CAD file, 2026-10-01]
order/shotpuck-order-2026-09-30/3_Cap_JLC3DP/cap.step
40.0 x 40.0 x 8.43 mm

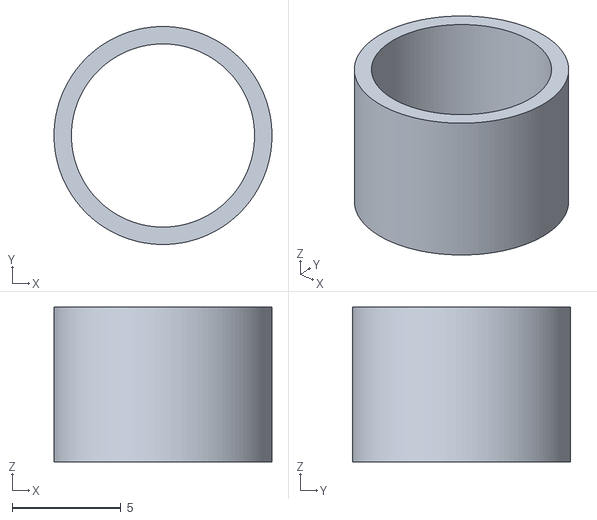
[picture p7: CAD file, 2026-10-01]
mechanical/out/sleeve.stl
10.0 x 10.00 x 7.10

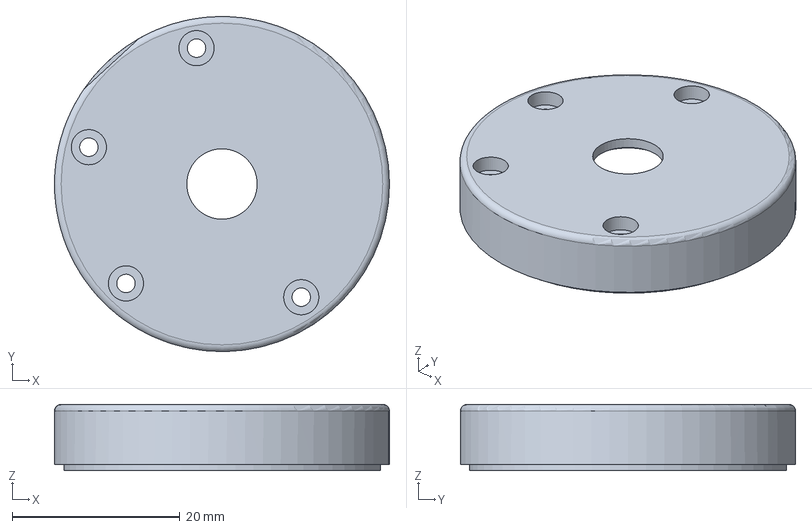
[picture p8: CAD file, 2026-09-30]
mechanical/out/cap.step
40.0 x 40.0 x 7.90 mm

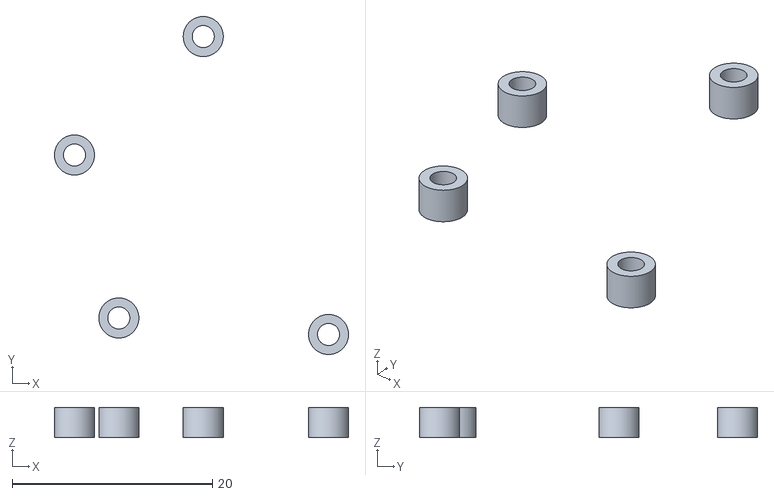
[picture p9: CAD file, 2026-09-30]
mechanical/out/standoffs.stl
29.4 x 33.7 x 3.00

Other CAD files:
order/shotpuck-order-2026-09-30/2_Plate_JLCCNC/B_cnc_6061/plate.step
mechanical/out/plate.stl
mechanical/out/cap.stl
mechanical/out/shotpuck_assembly.blend
order/shotpuck-order-2026-09-30/3_Cap_JLC3DP/cap.stl

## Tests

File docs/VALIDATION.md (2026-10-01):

# Validation: what the simulation covers and what only hardware can prove

## Already validated (off-device)

| What | How | Result |
|---|---|---|
| Shot detector logic | `firmware/sim/simulate.py`: Monte Carlo sessions at 3.3 kHz ground truth, through the same `shot_detect.c`, an IDLE/ACTIVE pipeline and an LSM6DSO32 accelerometer model (±32 g clip, 0.976 mg LSB, same integer mg conversion as the firmware, no anti-alias filter = worst case) | See README (numbers regenerated by the final run) |
| Capture window + BLE packets | `firmware/sim/test_capture.c` (run by `simulate.py`): time/index mapping, window contents across ring wrap-around, late/early triggers, slot eviction, reset, exact header/data packet layout at MTU 23 and 247 | CAPTURE TESTS: PASS |
| Shot log in flash | `firmware/sim/test_evlog.c` (run by `simulate.py`) against a fake NOR flash that rejects writes to unerased bytes: reboot recovery, wrap-around (952 of 3000 kept), `from_seq` filter, torn record, torn sector erase, appending during a replay | EVLOG TESTS: PASS (mutation-checked) |
| Firmware | Zephyr 4.1 sysbuild (MCUboot + app), custom board `shotpuck/nrf52840`, release and log+assert variants | 0 compiler warnings; both fit the 452 KB slot |
| OTA signing | `imgtool verify` on the signed image with the private key and with MCUboot's public dev key; MCUboot's embedded public key compared with the private key; build without the key | Valid with ours, rejected with the dev key, keys match, keyless build refused |
| Schematic | KiCad netlist export vs `design.py` (`check_netlist.py`), KiCad 10 ERC | 99/99 pin assignments, 26 nets; ERC 0 errors (2 intentional strap warnings) |
| PCB | Freerouting + hand edits (J1 notch, GND via, JP2, silkscreen) + KiCad 10 DRC | 0 violations, 0 unconnected (2 layers, vias 0.55/0.3 mm; 2026-09-30). Schematic parity: re-check for the USB-C board |
| PCB pre-order audit (magnetic board, 2026-09-29; redo the courtyard/boss distances and the stock check for the USB-C board) | DRC with schematic parity; IC pinouts against the datasheets (LSM6DSO32 DocID032891, MCP73831 DS20001984H, BQ2970 SLUSBU9I, DMN63D8LDW DS36021, DMN2004DWK DS30935, BMD-340 UBX-19033353: land pads against two built open-source footprints and against u-blox's STEP model, all 0.000 mm; 68 pin names against the pin table); LCSC part numbers against the intended parts; board against JLCPCB's 2-layer limits; courtyards against the outline, the cap bosses and the panel tabs | Every pad's net matches the schematic; all pinouts match; min hole-to-hole 0.56 mm, PTH ring 0.225 mm, copper to edge 0.3 mm; no courtyard overlaps or boss conflicts (closest Q2, 0.38 mm from the H4 boss face; C1 0.47 mm from H1's; D4 0.43 mm from H2's; the − cell pad's copper is 0.11 mm from the H4 boss face: clear, but keep solder on the pad); every BOM line in JLCPCB assembly stock for 20 boards on 2026-09-29 |
| Panel | KiKit 2×2 with a backbone, KiCad 10 DRC on the panel | 0 violations, 0 unconnected (91.1 × 92.7 mm, 2026-09-30); 4 tabs per board |
| Height / balance | CadQuery (`puck.py`) | 10.43 mm tall (1.2 mm PCB on 3 mm standoffs, 1.6 mm free above the cell, USB-C port through the cap wall); 16.72 g, COM 0.47 mm off axis (no trim weight; estimated masses). The cap is one solid and overlaps nothing but the port's seal ring (its intended squeeze) |
| Board under shot shock (magnetic board's layout; not re-run for the USB-C board, whose board is clamped through O-rings) | Kirchhoff plate FE of the board outline (scikit-fem, Morley elements, 0.3 mm mesh; FR-4 22 GPa + 60 % copper; module, connector and other parts as mass, module 1× or 5× as stiff as the board; standoff faces clamped); static 100 g along the puck axis | 4 screws, 0.8 mm: first mode 1.7–2.0 kHz (3 screws: 1.1–1.2 kHz); worst strain 160–180 µε, on bare board beside H1, ≤ 70 µε at any part; cell pads move ~0 against the cell (3 screws: 13–15 µm). 1.2 mm with 4 screws (the board since 2026-09-30): 2.7–3.2 kHz, ~100 µε. A model, not a measurement: the real shock level is unknown |

The simulation validates **logic and robustness margins**, not the physics of your bow. The signal model (release shock of 8–40 g, 15–80° rotation into the sling) is an assumption.

## On-device checklist

Do these in order: each step de-risks the next. **Bold** items are blockers.

### 1. Bench, cap off (programmer on the SWD test pads)
- [ ] **PCM wake on first cell:** the BQ29700 may leave its discharge FET off when a cell is first connected (TI SLUSBU9I §8.4.1). If the puck stays dead with a charged cell, attach the charger once; it must then run from the cell after the charger is removed.
- [ ] **First boot:** the LED blinks 200 ms, the puck advertises as ShotPuck, and the UICR REGOUT0 write causes one extra reset.
- [ ] **VDD measures 3.0 V** (REG0 programmed) and the IMU answers (WHO_AM_I 0x6C at I2C 0x6A; no 1 Hz error blinking).
- [ ] **Standby current** with JP1 cut: IDLE and not advertising should be about 17 µA (LSM6DSO32 accelerometer in low-power mode at 12.5 Hz is about 10 µA, interpolated from the datasheet; BQ29700 4 µA; measure it). ACTIVE at 416 Hz with the gyroscope should be about 0.7–0.8 mA. Advertising at 500 ms should add about 10–15 µA. These set the battery life (README: about 3.5–5 weeks at 2 h/day).
- [ ] **I2C on internal pull-ups** (no R5/R6 any more): no I2C errors at 400 kHz over a long ACTIVE run; if in doubt, scope SCL (rise time under 300 ns).
- [ ] **Wake-on-motion** from IDLE at the default 150 mg threshold (±8 g, 31.25 mg steps): picking up the bow wakes it; the bow lying still does not.
- [ ] **Charging:** about 21 mA (from R1 = 47k), and termination at 4.20 V ±0.75 %. Confirm both against the LIR1254 datasheet limits before first charge.
- [ ] **Charger LED:** after the pairing window, one blink every 2 s while charging; steady on once the charger has terminated (STAT high, cell ≥ 4.10 V); dark within 2 s of unplugging. Through JP1, check the charger still terminates (current falls to 0) and the steady LED draws about 1 mA from the cell; leave it on the charger overnight and note how often it tops up (LED back to blinking).
- [ ] **CHG_STAT and VBUS flags** in STATUS follow the cable.
- [ ] **Weak supply:** at 4.75 V on the USB-C port, VBUS is detected (pairing window opens, STATUS shows VBUS) and stays detected while charging; measure the final cell voltage after termination (may end slightly below 4.20 V; the MCP73831 is specified from 5.2 V input).
- [ ] **Hot-plug:** scope VIN and VBUS_SNS while plugging a USB-C cable in and out 20 times from a stiff 5 V supply: VIN stays below 7 V and VBUS_SNS below 5.8 V.
- [ ] **LED:** the yellow-green LED (XL-1005SYGC, ~1 mA), at the board's left rim (9 o'clock seen from the cap, 1.5 mm inside the cap wall), is clearly visible through the cap top and side indoors and in daylight shade.
- [ ] **Charge inhibit:** freezer at −5 °C sets CHG_INHIBIT and the charge current drops to about 0. Warm to 20 °C and charging resumes.
- [ ] **Low-battery cut-off:** with a bench supply on the cell pads below 3.3 V, the puck enters System OFF (current under 1 µA). **Attaching the charger must wake it** (nRF52840 VBUS wake from System OFF: verify, it is load-bearing).

### 2. Assembled puck
- [ ] **Cell protection (PCM):** with a current-limited bench supply in place of the cell, check over-discharge cut-off at about 2.8 V, over-charge cut-off at about 4.28 V, and that a load above about 0.1 A (e.g. 30 Ω across VBAT–GND) trips the over-current protection within about 20 ms. Recovery needs V− to fall back near VSS: with the puck's own load still on, expect it to recover only when the charger is attached; note which. Check the drop across Q2 at 21 mA charging (expected under 30 mV).
- [ ] **USB-C port:** a plain 5 V USB-C charger and a USB-PD charger with a C-to-C cable both start charging (the 5.1k CC pull-downs request 5 V), in both plug orientations; a plug with a large overmold seats fully against the cap flat.
- [ ] **Cell and contacts:** the cell drops freely into the notch onto the Kapton; the + spring presses on the can side and the − strap on the top cap without touching the can edge; with the cap on, the foam clamps the cell and it cannot shift. **No resets from shot shock:** shoot a session and check that the puck never rebooted (a reboot shows as `t_uptime_ms` falling between consecutive EVENTs and `seq` jumping ahead).
- [ ] **Swell space:** with the cap on, a 7.0 mm gauge block in place of the cell fits without load (1.6 mm above the 5.4 mm cell), and the foam pad still clamps a real cell.
- [ ] **Identity:** the puck advertises as `ShotPuck-XXXX`; the DIS serial number (readable without pairing) ends in the same 4 characters and is identical on two different phones.
- [ ] **Pairing window:** attach the charger: the LED blinks once a second for 60 s. Pair from iOS and from Android inside the window (LED blinks twice on success). After the window, a new phone's pairing is rejected and it cannot read COUNT or subscribe; the paired phone still reconnects and works.
- [ ] **FORGET_BONDS** removes all phones; pairing works again only through the charger window.
- [ ] **Shot log:** shoot 10 shots, reset the puck (SWD or battery), reconnect and `REPLAY(0)`: all 10 accepted shots come back with their original `t_unix_ms`. Rejected candidates from before the reset are gone (RAM only).
- [ ] **Background replay:** trigger `REPLAY(0)` with a full log and shoot during it. No shot is missed and the debug log shows no `FIFO overrun`.
- [ ] **IMU axes:** record a capture with the puck lying cap-up (+Z ≈ +1000 mg), then on its edge in two directions, and note which X/Y direction points along the arrow and which points up the riser. Put the mapping in `docs/PROTOCOL.md` for the app.
- [ ] **Capture transfer:** after a shot, the app receives the header plus 624 samples within about 3 s; GET_CAPTURE re-sends it; the gyroscope shows the bow rotating forward into the sling.
- [ ] **BLE range through the cap**, with the puck on the riser and the phone in a pocket about 1–2 m away, and at 10 m. If the link is weak, raise TX power (`CONFIG_BT_CTLR_TX_PWR_PLUS_4=y`) or check the antenna keep-out against the aluminium base.
- [ ] **Tube fit:** with the tube standing on the plate, the cap sits on all four bosses without rocking before the M2 screws go in (if the tube holds it up, face the tube shorter), and the tube's top end is in the lip. Off the bow, turn the puck over and shake it: the tube stays in.
- [ ] **Bolt mounting (PC cap top in the clamp path, D21):** tighten the bolt to 3 N·m and mark the head. Re-check the torque after 1 day, 1 week and a shooting session: if it has dropped, the cap top is creeping under the washer. Look for cracks or whitening around the bolt hole and check that the cap screws still sit tight. Check BLE range with the bolt head in place (it overlaps the antenna zone's inner corner).
- [ ] **Tube insulation:** the Kapton tape goes all round the tube from the plate to the cell top; turn the tube and shake the puck hard: the cell never touches bare steel.
- [ ] **O-ring fit (first SLA cap):** try the 36, 37 and 38 × 1.0 O-rings; the chosen one stays on the ledge during assembly, and the cap's inner band seats on the plate all round. Tune `seal.ledge_od`/`squeeze` and `connector.seal_squeeze` from this print.
- [ ] **Sealing:** with the cap on, a water test leaves the inside dry (seal O-ring, port ring, screw holes). After 50 plug cycles the port's silicone ring and the cap wall around it are intact and the port has not moved.
- [ ] Weigh each finished puck and compare with `mechanical/out/mass_report.txt`; re-run `puck.py` with measured part masses.

### 2b. Firmware update (OTA)
- [ ] **First flash** `firmware/shotpuck_full.hex` by cable: MCUboot starts the app (LED 200 ms, advertises).
- [ ] **OTA upgrade** from a paired phone (nRF Connect Device Manager, *Test and confirm*) to an image with a bumped `VERSION`: upload, reset, swap, reconnect. DIS Firmware Revision shows the new version; `image list` shows it confirmed. Shots, count, config and pairing survived.
- [ ] **Rollback on reset:** upload in *Test* mode and reset the puck (battery or SWD) within 10 s of the new image starting. It must come back on the previous version.
- [ ] **Rollback on hang:** upload a test image that hangs in the main loop. The watchdog resets it after about 10 s, and MCUboot boots the previous version.
- [ ] **Confirm needs a paired link:** after an OTA reset, do not reconnect and reset the puck after 30 s: it must roll back. Repeat, reconnect and pair: it confirms (no rollback on the next reset).
- [ ] **Reset pads (JP2):** with the cap off, bridge the pads with tweezers: the LED lights; release before 5 s: nothing happens. Hold 5 s: 5 fast blinks, reboot, shot count 0, the phone must pair again (charger window). Boot with the pads already shorted (solder blob): no reset until the short is removed and made again.
- [ ] **Security:** an unpaired phone cannot use SMP; an image signed with another key uploads but never boots (the puck stays on its version).
- [ ] Idle current is unchanged with the watchdog running (main loop wakes every 2 s).

### 3. Shooting: threshold tuning (the key step)
- [ ] Log **every EVENT** (accepted and rejected) and every CAPTURE in the app for at least 3 sessions and 100+ shots, noting any miss or false count by hand.
- [ ] Compare the shots' `peak_hf_mg`, `pre_still_ms` and `post_lf_mg` with the simulated 5th–95th percentile ranges printed by `simulate.py`.
  - If shot peaks sit near or below 6000 mg (light draw weight, heavy riser damping), lower `trig_hf_mg`. The weak-bow simulation set shows recall collapsing if you don't.
  - If `post_lf_mg` of real shots is below 250 mg (firm grip, no sling), lower `post_lf_min_mg`. Watch for more stand-knock false counts.
- [ ] Feed the logged feature vectors back into the simulation, or send them to me, and re-verify before changing the defaults in `shot_detect.c`.
- [ ] Non-shot checks, 20 each: bow set on the stand, knock on the stand, walking with the bow, drop onto grass, let-down.

### 4. Durability
- [ ] 2,000+ shots, then inspect: cell contacts (spring pressure, strap position), USB-C solder joints, screw torque (all 4 nylon-patch M2; the board is clamped through the 2 × 1.0 O-rings, so check the preload and that the board has not shifted), the seal O-ring seat, standoffs, bolt torque, the corner staking on the BMD-340 and C2 (no cracks, no lifted fillets).
- [ ] Count accuracy unchanged after the durability run.
- [ ] Battery life over 2–4 weeks of normal training vs the estimate in the README.

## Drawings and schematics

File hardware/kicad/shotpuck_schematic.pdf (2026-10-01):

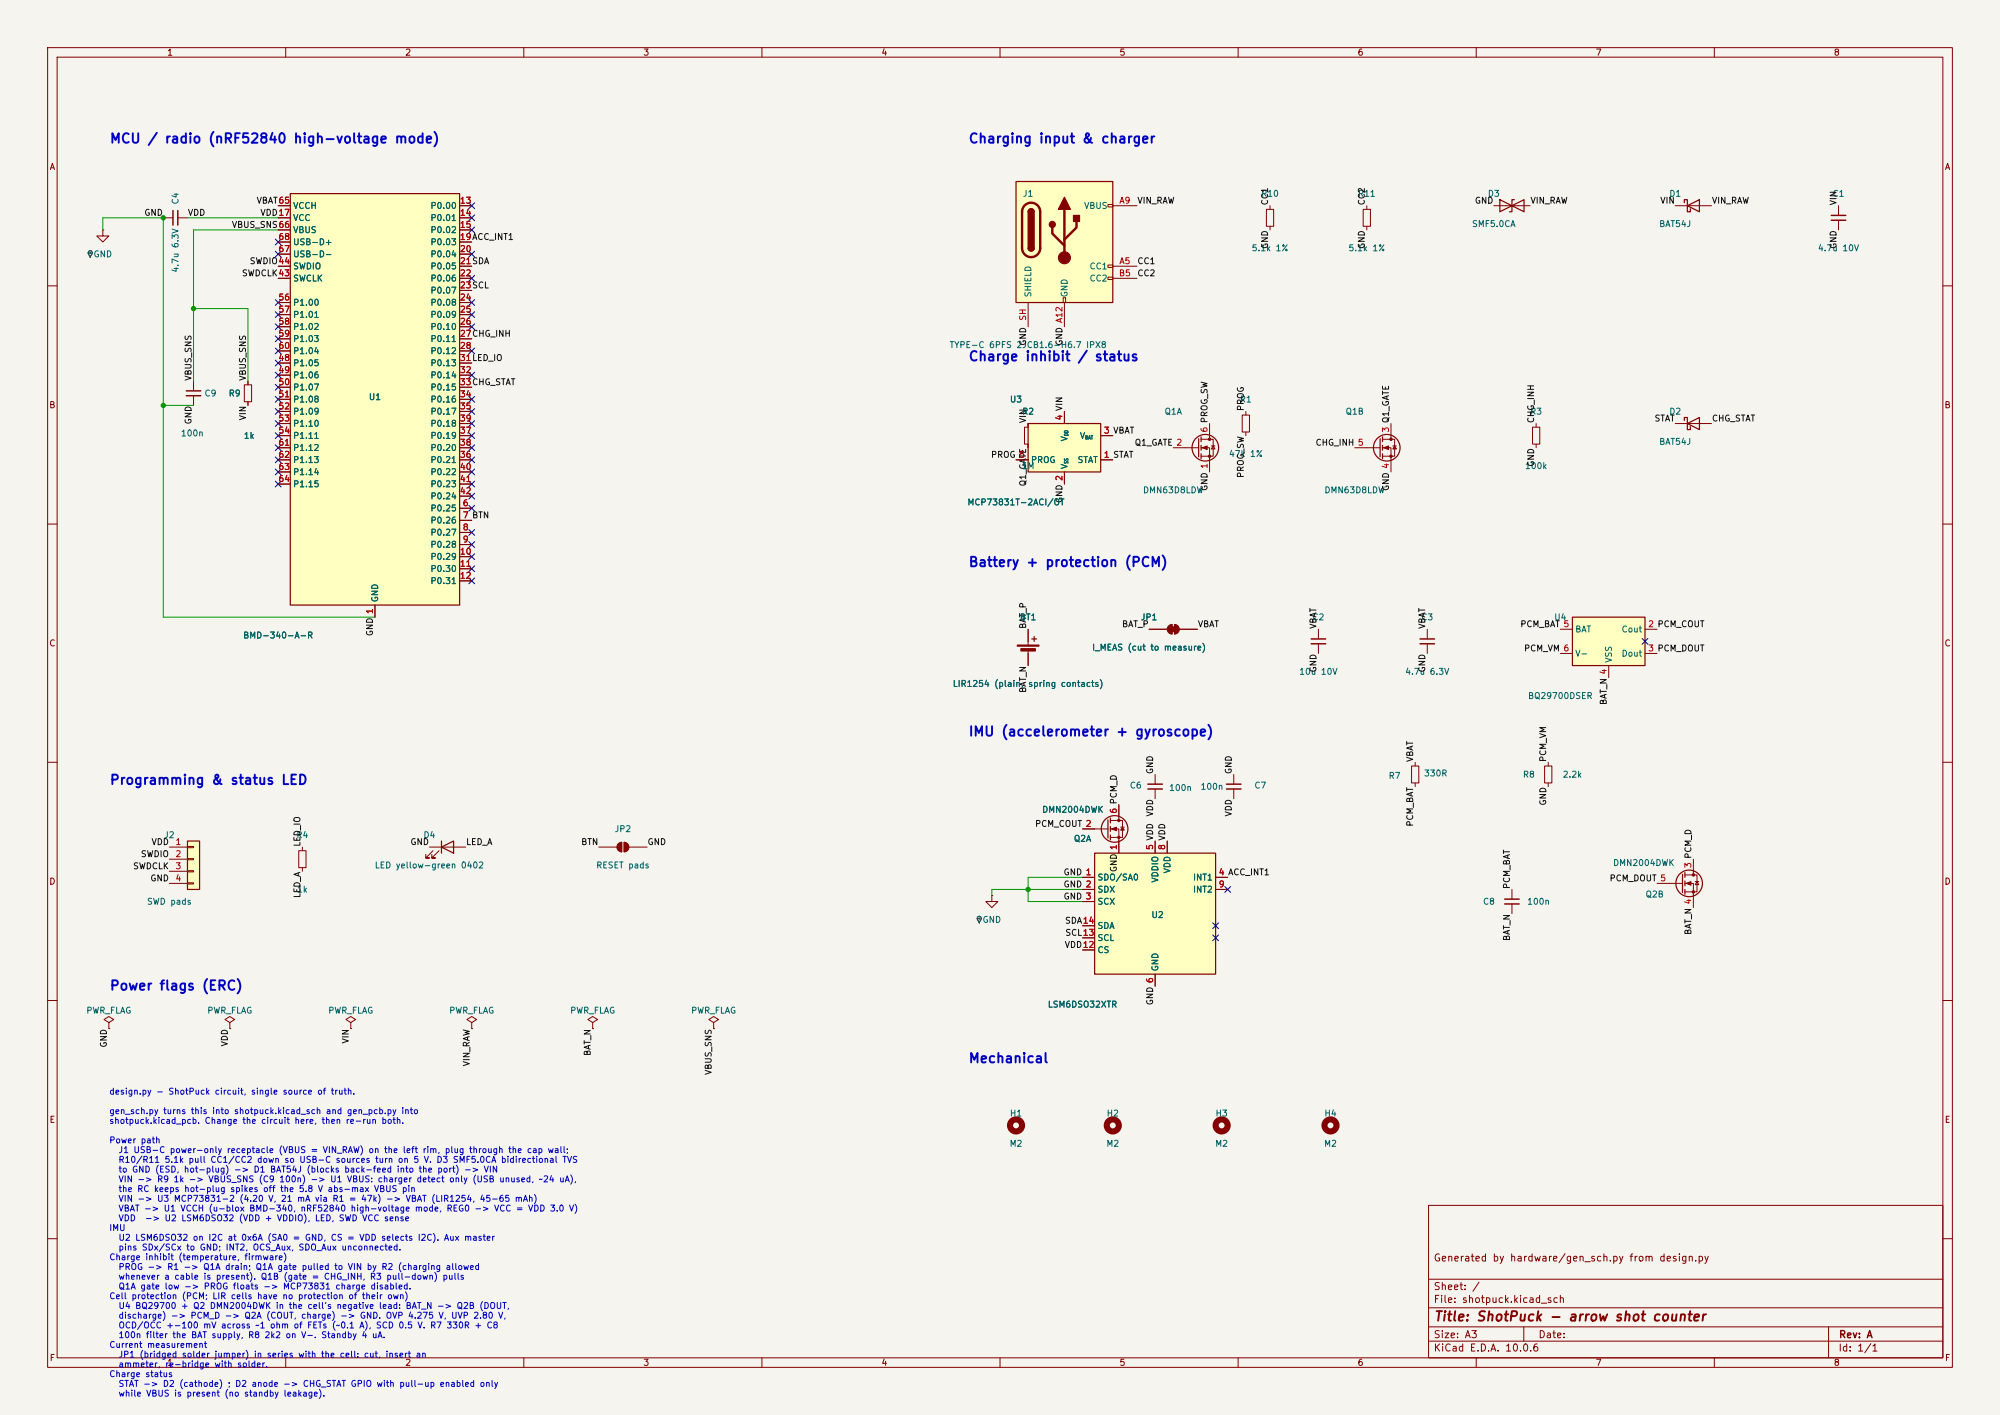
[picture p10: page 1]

MCU / radio (nRF52840 high-voltage mode)

design.py - ShotPuck circuit, single source of truth. gen_sch.py turns this into shotpuck.kicad_sch and gen_pcb.py into

shotpuck.kicad_pcb. Change the circuit here, then re-run both. Power path

J1 USB-C power-only receptacle (VBUS = VIN_RAW) on the left rim, plug through the cap wall;
R10/R11 5.1k pull CC1/CC2 down so USB-C sources turn on 5 V. D3 SMF5.0CA bidirectional TVS
to GND (ESD, hot-plug) -> D1 BAT54J (blocks back-feed into the port) -> VIN
VIN -> R9 1k -> VBUS_SNS (C9 100n) -> U1 VBUS: charger detect only (USB unused, ~24 uA), the RC keeps hot-plug spikes off the 5.8 V abs-max VBUS pin

VIN -> U3 MCP73831-2 (4.20 V, 21 mA via R1 = 47k) -> VBAT (LIR1254, 45-65 mAh) VBAT -> U1 VCCH (u-blox BMD-340, nRF52840 high-voltage mode, REG0 -> VCC = VDD 3.0 V) VDD -> U2 LSM6DSO32 (VDD + VDDIO), LED, SWD VCC sense

IMU
U2 LSM6DSO32 on I2C at 0x6A (SA0 = GND, CS = VDD selects I2C). Aux master pins SDx/SCx to GND; INT2, OCS_Aux, SDO_Aux unconnected. Charge inhibit (temperature, firmware) PROG -> R1 -> Q1A drain; Q1A gate pulled to VIN by R2 (charging allowed whenever a cable is present). Q1B (gate = CHG_INH, R3 pull-down) pulls Q1A gate low -> PROG floats -> MCP73831 charge disabled. Cell protection (PCM; LIR cells have no protection of their own) U4 BQ29700 + Q2 DMN2004DWK in the cell's negative lead: BAT_N -> Q2B (DOUT, discharge) -> PCM_D -> Q2A (COUT, charge) -> GND. OVP 4.275 V, UVP 2.80 V,

Sheet: /
File: shotpuck.kicad_sch
Title: ShotPuck - arrow shot counter

OCD/OCC +-100 mV across ~1 ohm of FETs (~0.1 A), SCD 0.5 V. R7 330R + C8
100n filter the BAT supply, R8 2k2 on V-. Standby 4 uA. Current measurement JP1 (bridged solder jumper) in series with the cell: cut, insert an

Size: A3 | Rev: A
KiCad E.D.A. 10.0.6 | Id: 1/1

ammeter, re-bridge with solder. Charge status STAT -> D2 (cathode) ; D2 anode -> CHG_STAT GPIO with pull-up enabled only while VBUS is present (no standby leakage).

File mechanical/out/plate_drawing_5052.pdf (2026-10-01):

## HOLE TABLE (mm, from the plate centre, top view)

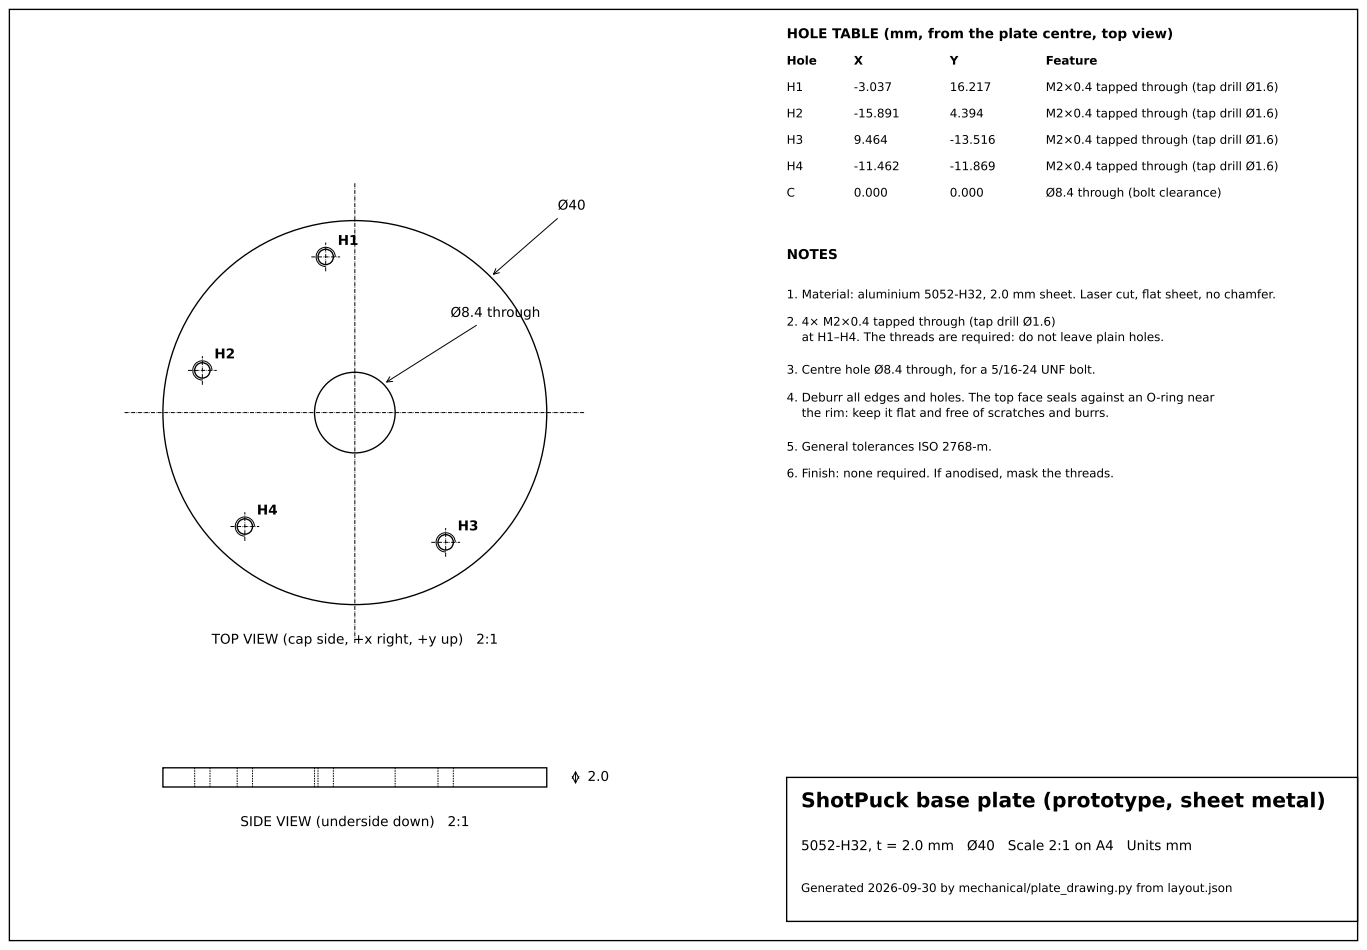
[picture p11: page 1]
Ø8.4 through; Hole; Feature; M2×0.4 tapped through (tap drill Ø1.6); Ø8.4 through (bolt clearance); NOTES

1. Material: aluminium 5052-H32, 2.0 mm sheet. Laser cut, flat sheet, no chamfer.

2. 4× M2×0.4 tapped through (tap drill Ø1.6)
at H1–H4. The threads are required: do not leave plain holes.

3. Centre hole Ø8.4 through, for a 5/16-24 UNF bolt.

4. Deburr all edges and holes. The top face seals against an O-ring near
the rim: keep it flat and free of scratches and burrs.

5. General tolerances ISO 2768-m.

6. Finish: none required. If anodised, mask the threads.

TOP VIEW (cap side, +x right, +y up) 2:1

ShotPuck base plate (prototype, sheet metal)

SIDE VIEW (underside down) 2:1

5052-H32, t = 2.0 mm Ø40 Scale 2:1 on A4 Units mm

Generated 2026-09-30 by mechanical/plate_drawing.py from layout.json

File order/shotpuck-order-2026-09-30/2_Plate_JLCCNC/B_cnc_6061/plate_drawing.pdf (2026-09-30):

## HOLE TABLE (mm, from the plate centre, top view)

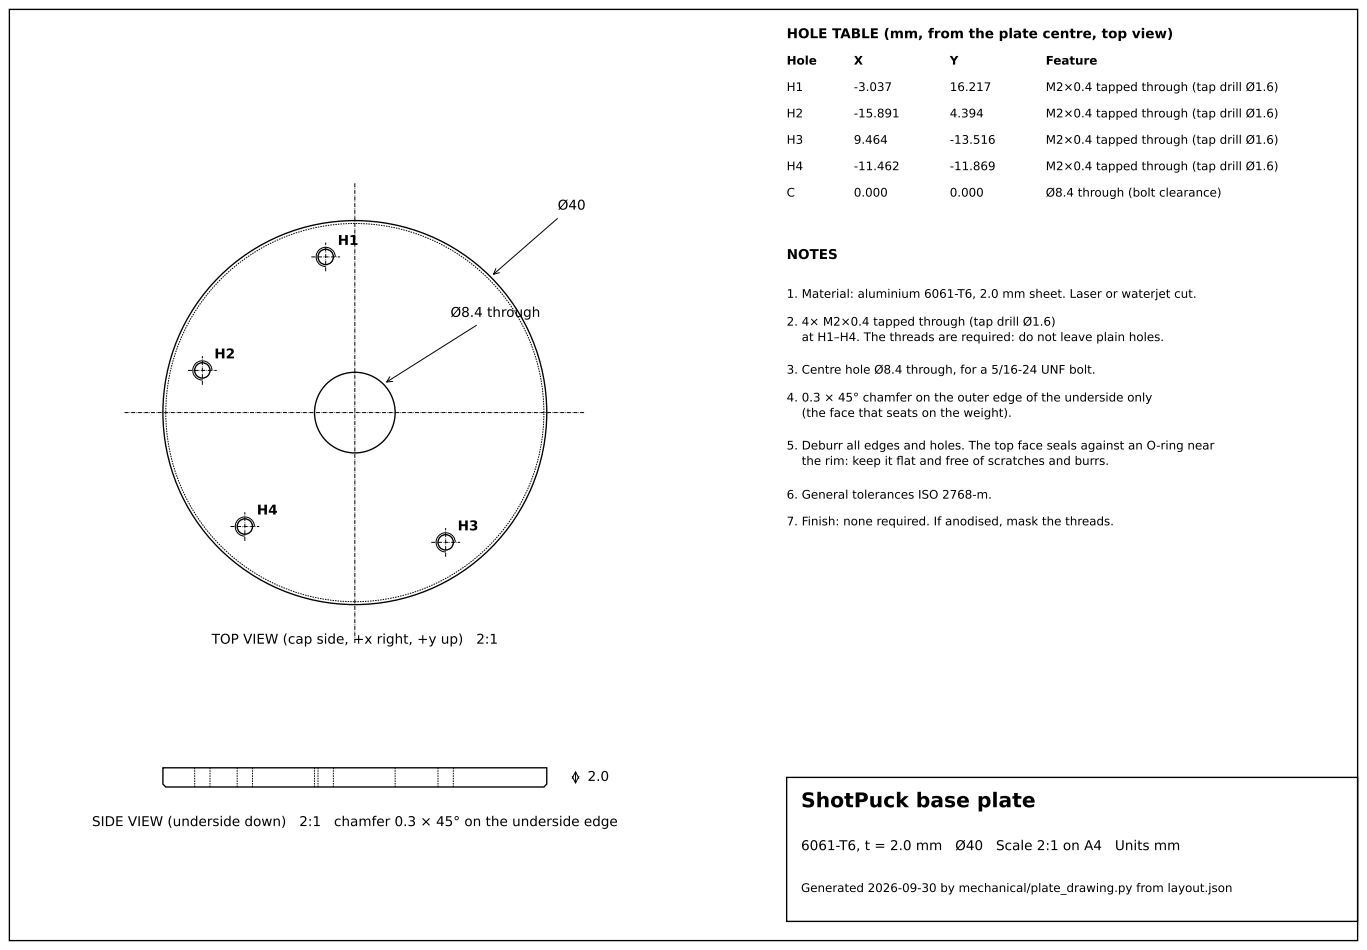
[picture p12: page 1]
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

1. Material: aluminium 6061-T6, 2.0 mm sheet. Laser or waterjet cut.

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

3. Centre hole Ø8.4 through, for a 5/16-24 UNF bolt.

4. 0.3 × 45° chamfer on the outer edge of the underside only
(the face that seats on the weight).

5. Deburr all edges and holes. The top face seals against an O-ring near
the rim: keep it flat and free of scratches and burrs.

6. General tolerances ISO 2768-m.

7. Finish: none required. If anodised, mask the threads.

TOP VIEW (cap side, +x right, +y up) 2:1

ShotPuck base plate

SIDE VIEW (underside down) 2:1 chamfer 0.3 × 45° on the underside edge

6061-T6, t = 2.0 mm Ø40 Scale 2:1 on A4 Units mm

Generated 2026-09-30 by mechanical/plate_drawing.py from layout.json

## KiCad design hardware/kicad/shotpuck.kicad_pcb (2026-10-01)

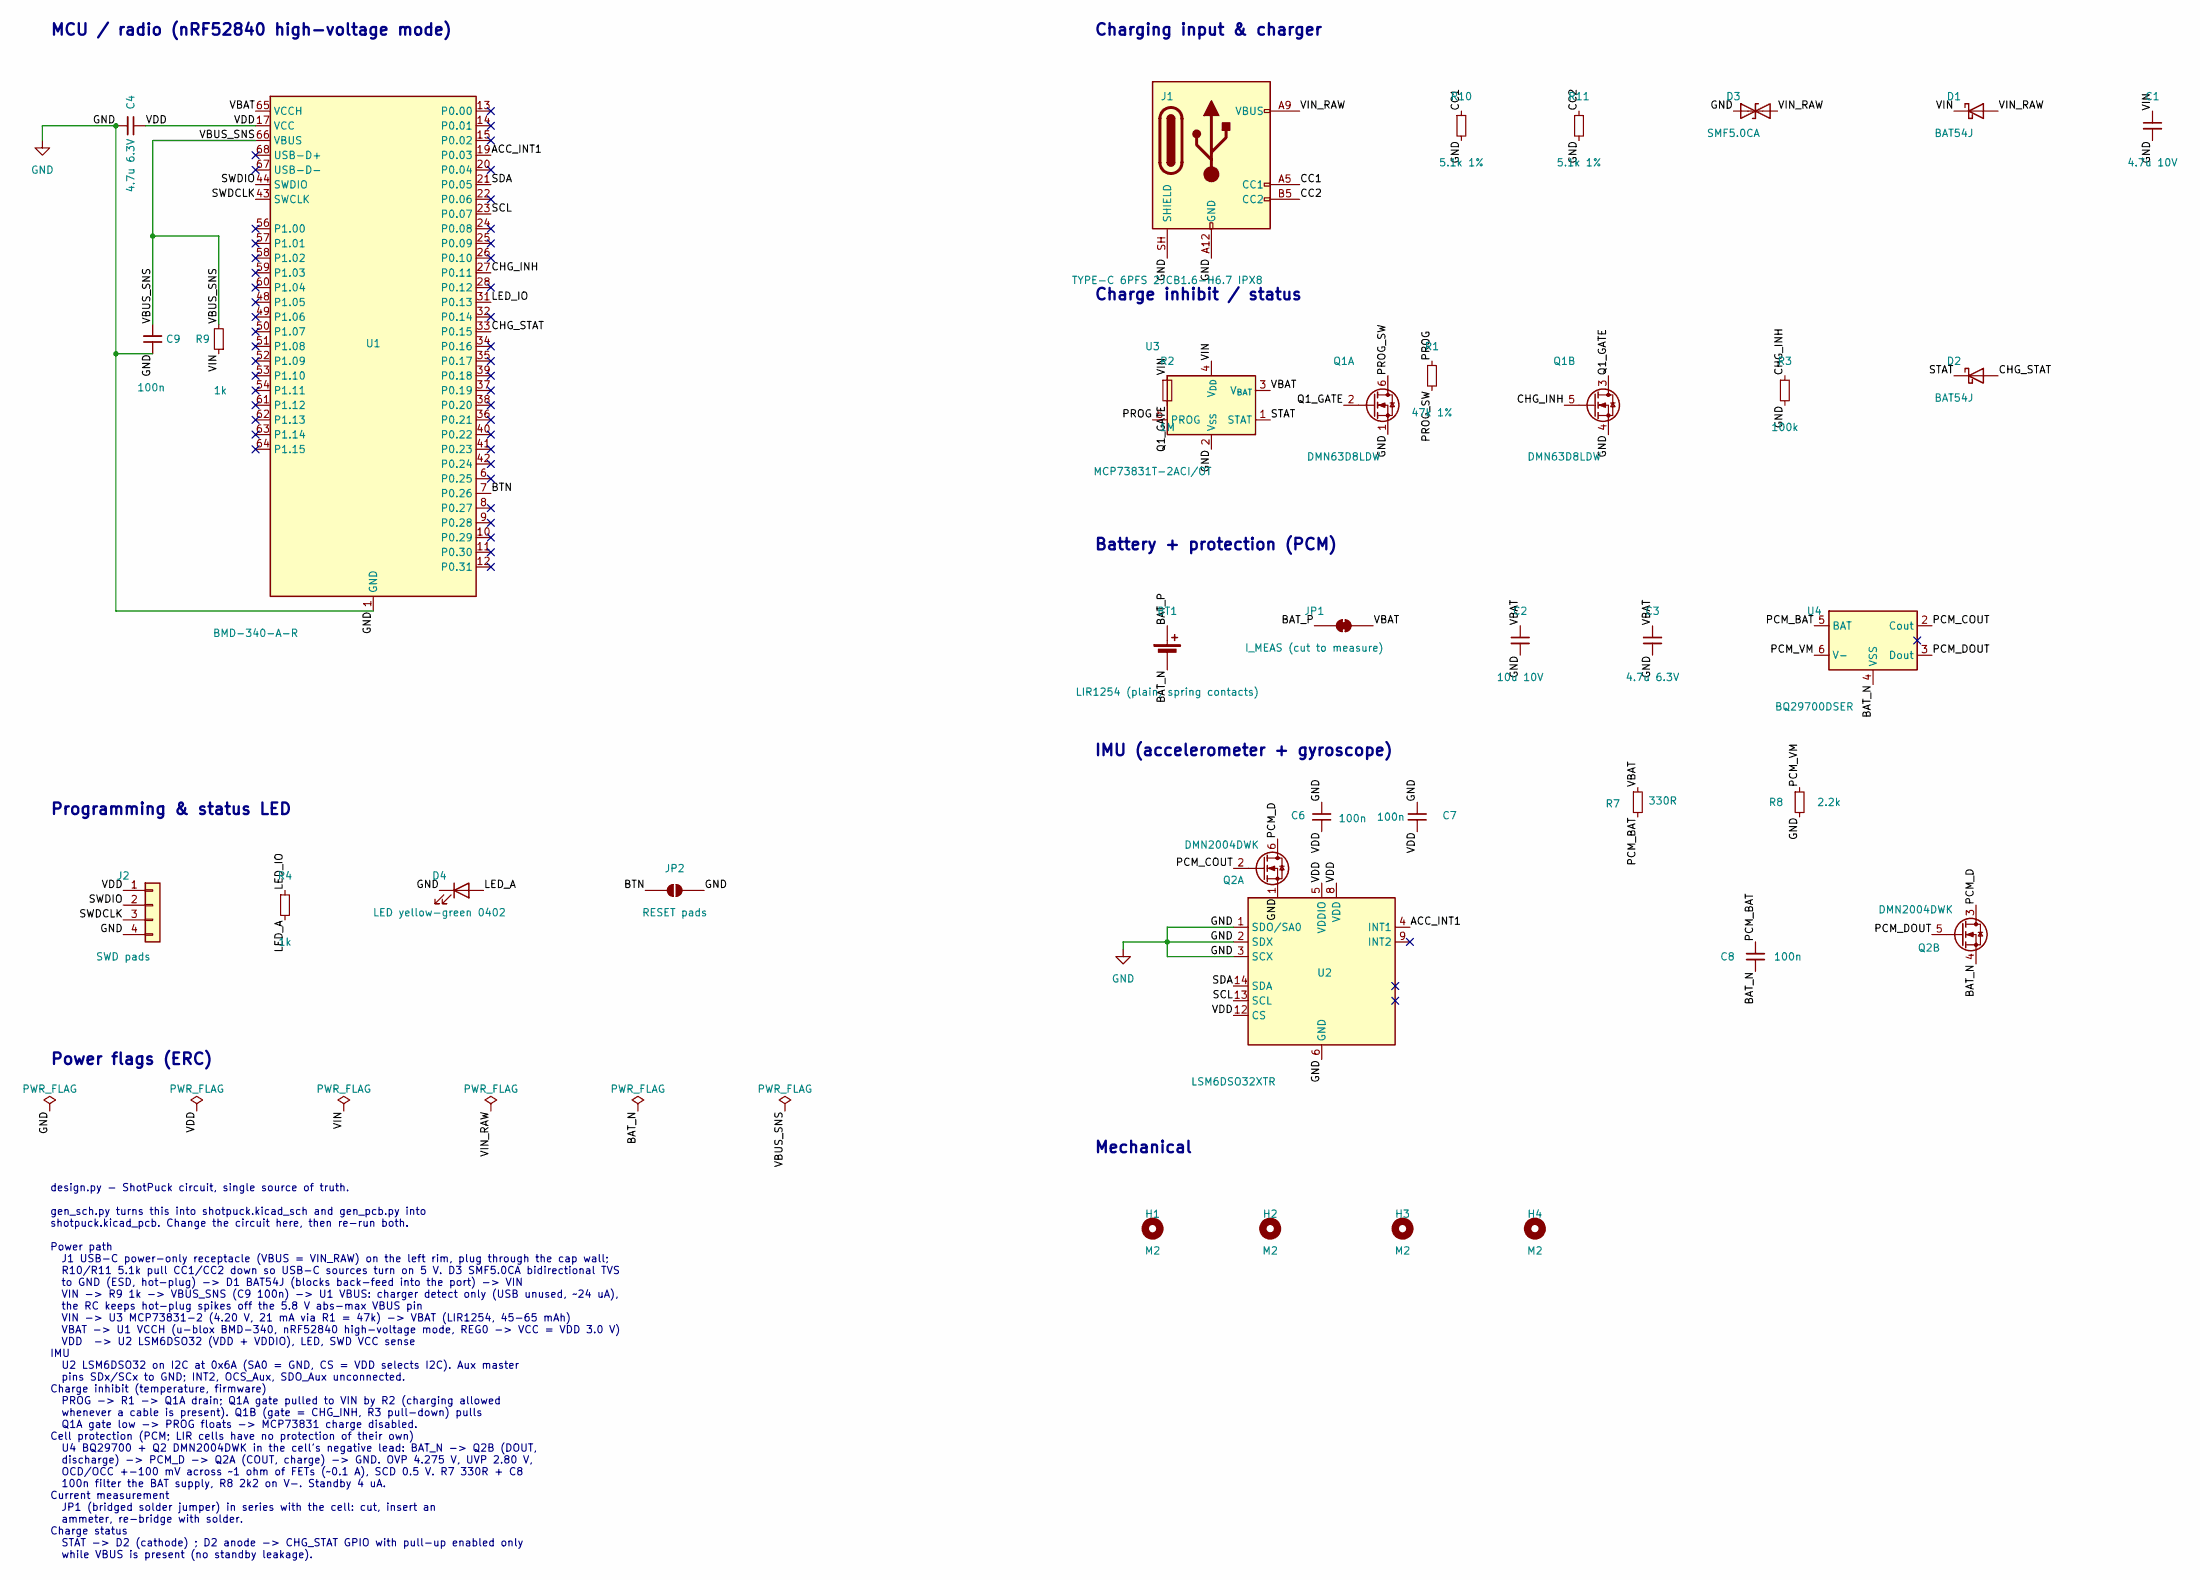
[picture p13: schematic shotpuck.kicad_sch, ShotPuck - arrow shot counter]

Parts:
BT1: LIR1254 (plain, spring contacts); LIR1254_Contacts_Edit
C1: 4.7u 10V; C_0603_1608Metric
C2: 10u 10V; C_0603_1608Metric
C3, C4: 4.7u 6.3V; C_0402_1005Metric
C6, C7, C8, C9: 100n; C_0402_1005Metric
D1, D2: BAT54J; D_SOD-323F
D3: SMF5.0CA; D_SOD-123F
D4: LED yellow-green 0402; LED_0402_1005Metric
H1, H2, H3, H4: M2; MountingHole_2.4mm_NPTH
J1: TYPE-C 6PFS 2JCB1.6-H6.7 IPX8; USB_C_Receptacle_ShouHan_TYPE-C-6PFS-2JCB1.6-H6.7_IPX8
J2: SWD pads; SWD_Pads_1x4_P2.54
JP1: I_MEAS (cut to measure); SolderJumper-2_P1.3mm_Bridged_Pad1.0x1.5mm
JP2: RESET pads; TweezerPads_2x0.8mm_Gap0.4mm
Q1: DMN63D8LDW; SOT-363_SC-70-6
Q2: DMN2004DWK; SOT-363_SC-70-6
R1: 47k 1%; R_0402_1005Metric
R2: 1M; R_0402_1005Metric
R3: 100k; R_0402_1005Metric
R4, R9: 1k; R_0402_1005Metric
R7: 330R; R_0402_1005Metric
R8: 2.2k; R_0402_1005Metric
R10, R11: 5.1k 1%; R_0402_1005Metric
U1: BMD-340-A-R; u-blox_BMD-340
U2: LSM6DSO32XTR; LGA-14_3x2.5mm_P0.5mm_LayoutBorder3x4y
U3: MCP73831T-2ACI/OT; SOT-23-5
U4: BQ29700DSER; WSON-6_1.5x1.5mm_P0.5mm

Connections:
/ACC_INT1: U1.19 (P0.03), U2.4 (INT1)
/BAT_N: BT1.2 (-), C8.2, Q2.4 (S), U4.4 (VSS)
/BAT_P: BT1.1 (+), JP1.1 (A)
/BTN: JP2.1 (A), U1.7 (P0.26)
/CC1: J1.A5 (CC1), R10.1
/CC2: J1.B5 (CC2), R11.1
/CHG_INH: Q1.5 (G), R3.1, U1.27 (P0.11)
/CHG_STAT: D2.2 (A), U1.33 (P0.15)
/GND: C1.2, C2.2, C3.2, C4.2, C6.2, C7.2, C9.2, D3.1 (A1), D4.1 (K), J1.A12 (GND), J1.B12 (GND), J1.SH (SHIELD), J2.4, JP2.2 (B), Q1.1 (S), Q1.4 (S), Q2.1 (S), R3.2, R8.2, R10.2, R11.2, U1.1 (GND), U1.2 (GND), U1.3 (GND), U1.4 (GND), U1.5 (GND), U1.16 (GND), U1.18 (GND), U1.29 (GND), U1.30 (GND), U1.45 (GND), U1.46 (GND), U1.47 (GND), U1.55 (GND), U2.1 (SDO/SA0), U2.2 (SDX), U2.3 (SCX), U2.6 (GND), U2.7 (GND), U3.2 (V_{SS})
/LED_A: D4.2 (A), R4.2
/LED_IO: R4.1, U1.31 (P0.13)
/PCM_BAT: C8.1, R7.2, U4.5 (BAT)
/PCM_COUT: Q2.2 (G), U4.2 (Cout)
/PCM_D: Q2.3 (D), Q2.6 (D)
/PCM_DOUT: Q2.5 (G), U4.3 (Dout)
/PCM_VM: R8.1, U4.6 (V-)
/PROG: R1.1, U3.5 (PROG)
/PROG_SW: Q1.6 (D), R1.2
/Q1_GATE: Q1.2 (G), Q1.3 (D), R2.2
/SCL: U1.23 (P0.07), U2.13 (SCL)
/SDA: U1.21 (P0.05), U2.14 (SDA)
/STAT: D2.1 (K), U3.1 (STAT)
/SWDCLK: J2.3, U1.43 (SWCLK)
/SWDIO: J2.2, U1.44 (SWDIO)
/VBAT: C2.1, C3.1, JP1.2 (B), R7.1, U1.65 (VCCH), U3.3 (V_{BAT})
/VBUS_SNS: C9.1, R9.2, U1.66 (VBUS)
/VDD: C4.1, C6.1, C7.1, J2.1, U1.17 (VCC), U2.5 (VDDIO), U2.8 (VDD), U2.12 (CS)
/VIN: C1.1, D1.1 (K), R2.1, R9.1, U3.4 (V_{DD})
/VIN_RAW: D1.2 (A), D3.2 (A2), J1.A9 (VBUS), J1.B9 (VBUS)

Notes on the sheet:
Charging input & charger
MCU / radio (nRF52840 high-voltage mode)
IMU (accelerometer + gyroscope)
Mechanical
Power flags (ERC)
Programming & status LED
Charge inhibit / status
Battery + protection (PCM)
design.py - ShotPuck circuit, single source of truth. gen_sch.py turns this into shotpuck.kicad_sch and gen_pcb.py into shotpuck.kicad_pcb. Change the circuit here, then re-run both. Power path J1 USB-C power-only receptacle (VBUS = VIN_RAW) on the left rim, plug through the cap wall; R10/R11 5.1k 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

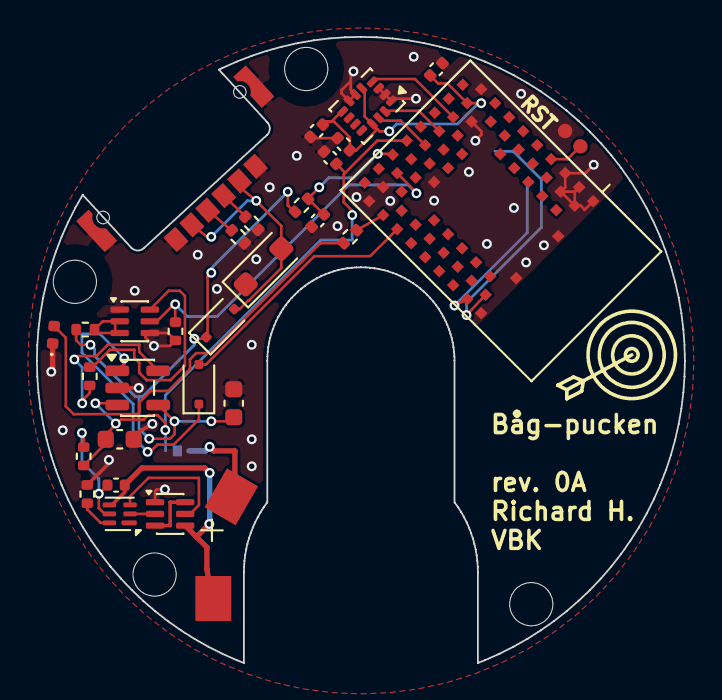
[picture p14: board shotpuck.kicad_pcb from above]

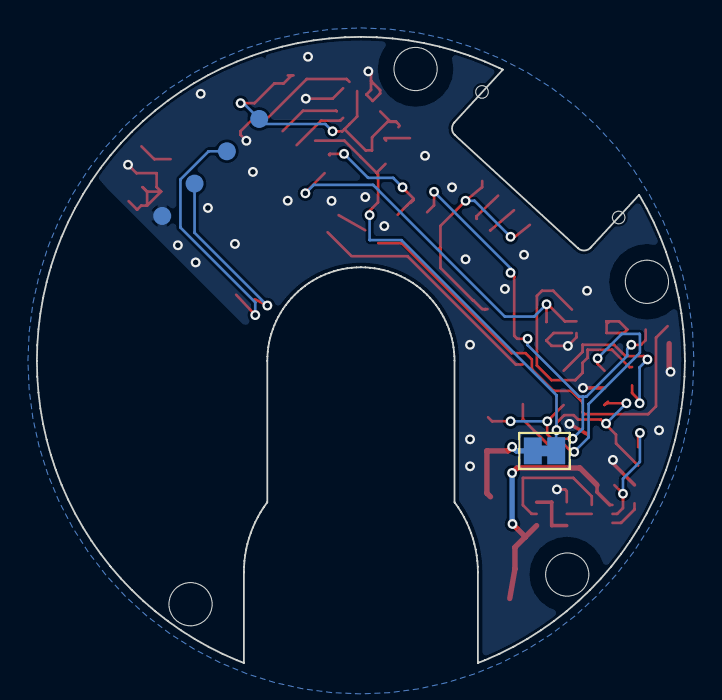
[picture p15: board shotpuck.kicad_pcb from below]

Board: 2 copper layers, 36.0 x 34.8 mm, 36 parts (2 on the bottom side), 29 nets.

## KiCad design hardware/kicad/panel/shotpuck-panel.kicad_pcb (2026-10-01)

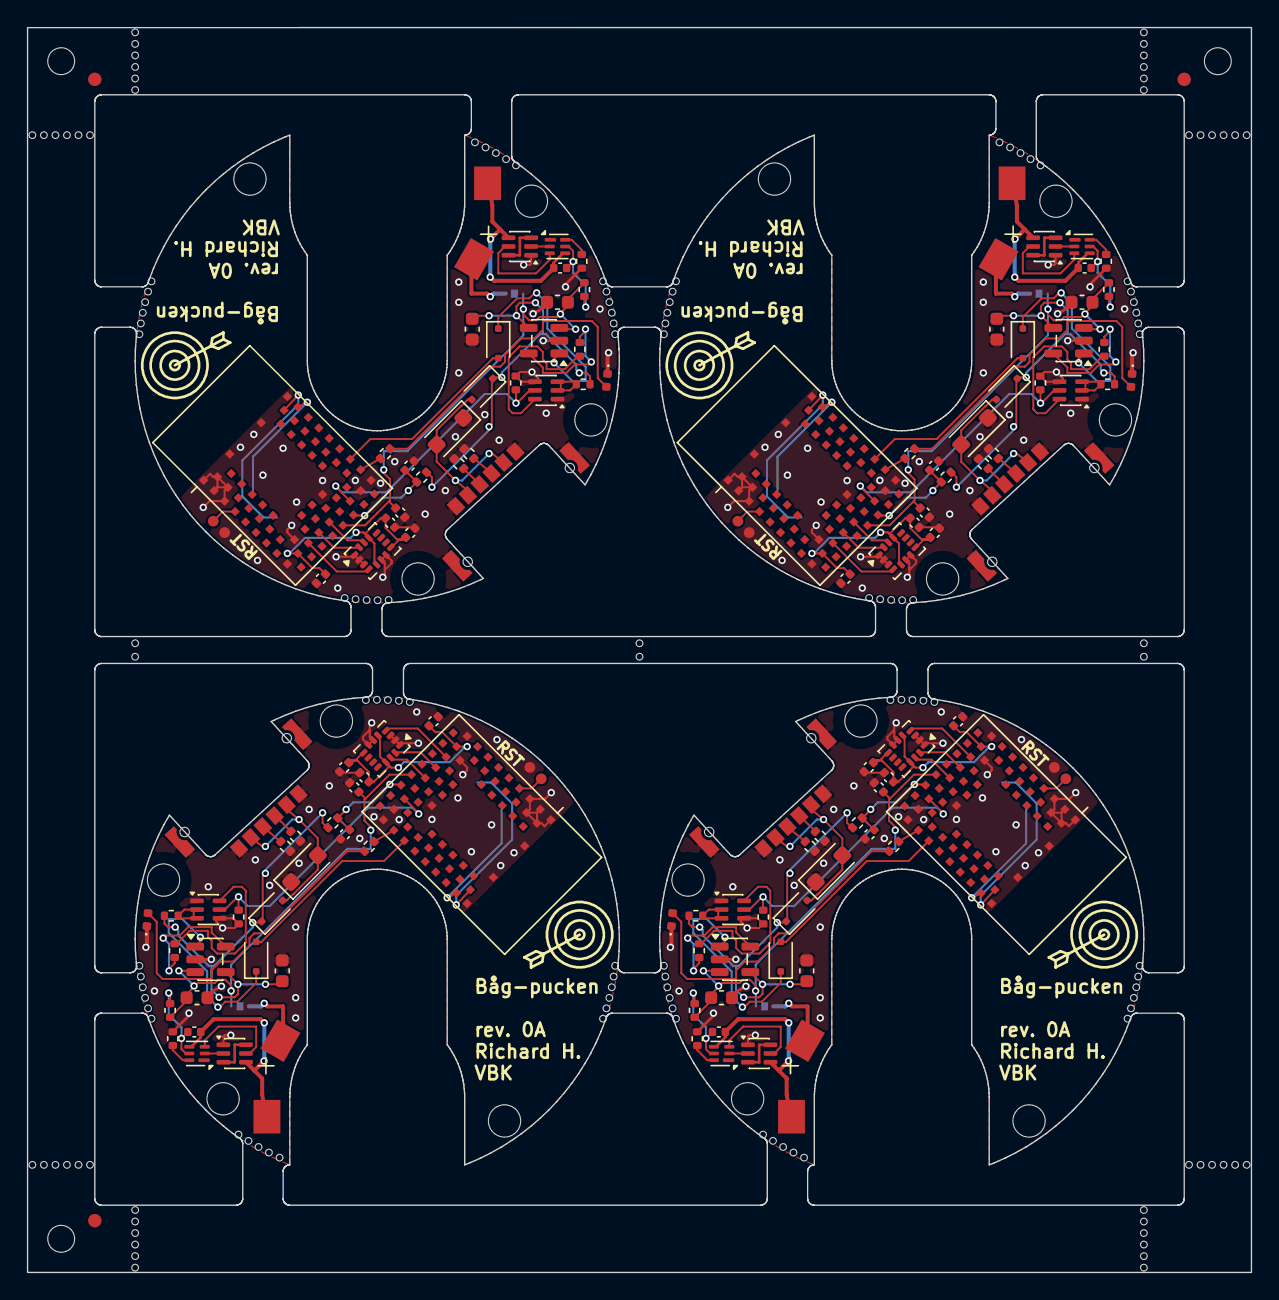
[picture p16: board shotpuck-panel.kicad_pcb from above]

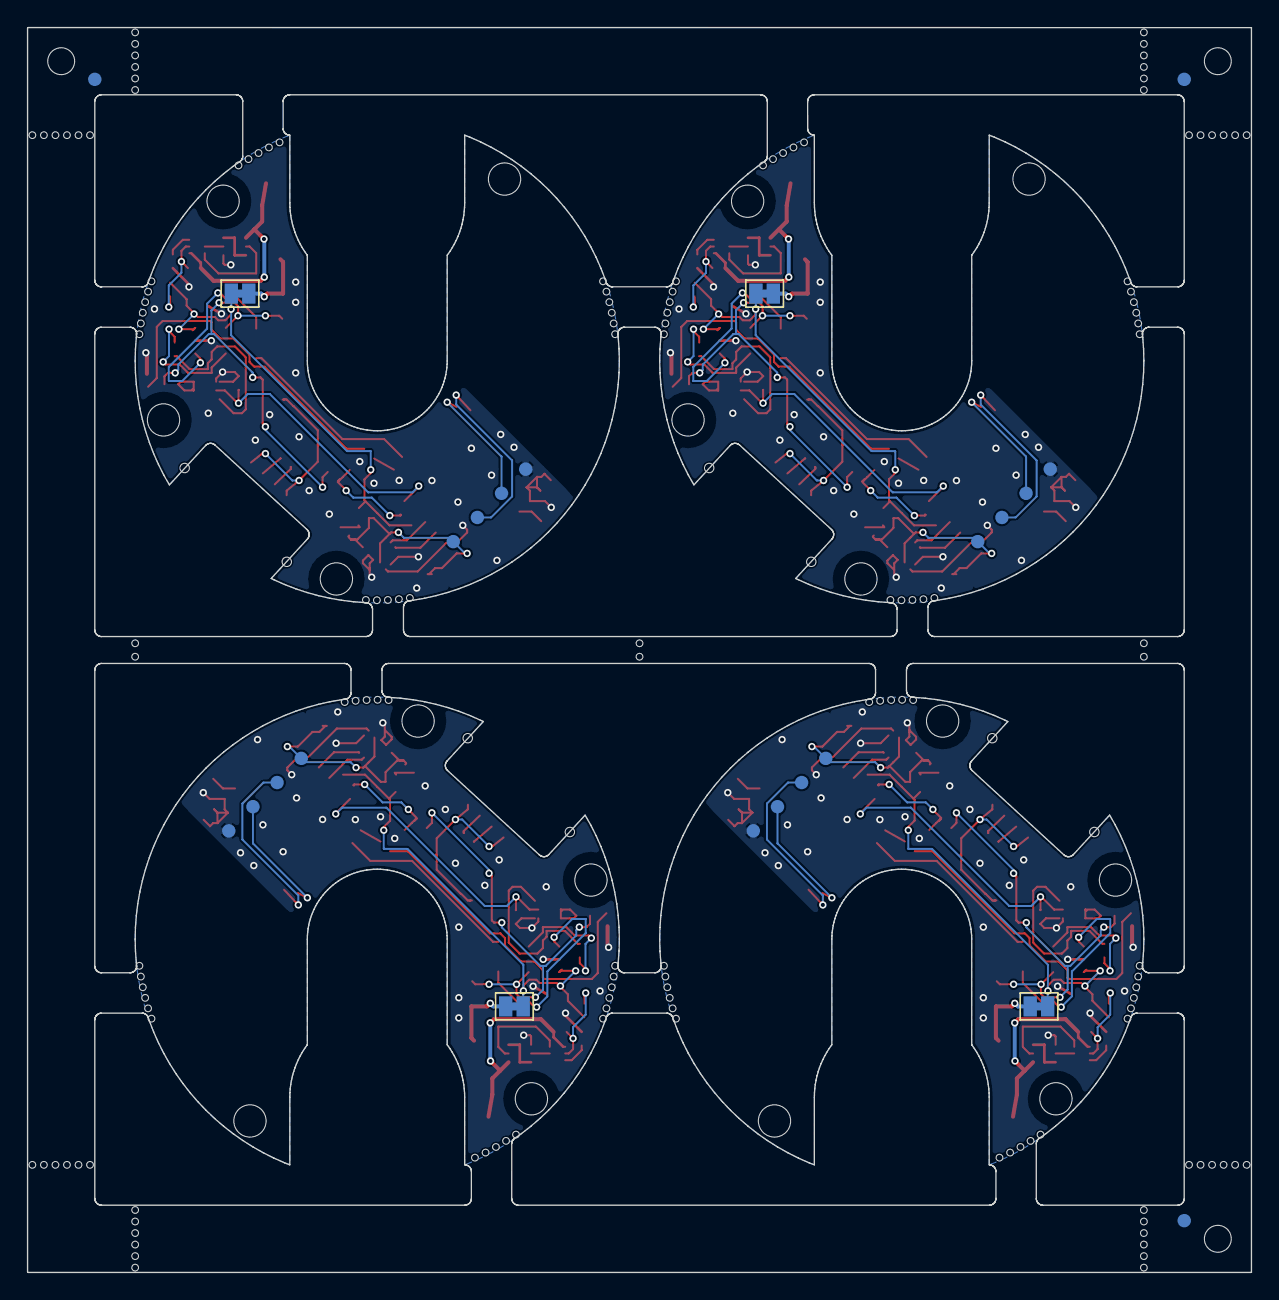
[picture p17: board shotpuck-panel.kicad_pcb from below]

Board: 2 copper layers, 91.0 x 92.6 mm, 295 parts (11 on the bottom side), 116 nets.

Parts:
BT1_0, BT1_1, BT1_2, BT1_3: LIR1254 (plain, spring contacts); LIR1254_Contacts_Edit
C1_0, C1_1, C1_2, C1_3: 4.7u 10V; C_0603_1608Metric
C2_0, C2_1, C2_2, C2_3: 10u 10V; C_0603_1608Metric
C3_0, C3_1, C3_2, C3_3, C4_0, C4_1, C4_2, C4_3: 4.7u 6.3V; C_0402_1005Metric
C6_0, C6_1, C6_2, C6_3, C7_0, C7_1, C7_2, C7_3, C8_0, C8_1, C8_2, C8_3, C9_0, C9_1, C9_2, C9_3: 100n; C_0402_1005Metric
D1_0, D1_1, D1_2, D1_3, D2_0, D2_1, D2_2, D2_3: BAT54J; D_SOD-323F
D3_0, D3_1, D3_2, D3_3: SMF5.0CA; D_SOD-123F
D4_0, D4_1, D4_2, D4_3: LED yellow-green 0402; LED_0402_1005Metric
H1_0, H1_1, H1_2, H1_3, H2_0, H2_1, H2_2, H2_3, H3_0, H3_1, H3_2, H3_3, H4_0, H4_1, H4_2, H4_3: M2; MountingHole_2.4mm_NPTH
J1_0, J1_1, J1_2, J1_3: TYPE-C 6PFS 2JCB1.6-H6.7 IPX8; USB_C_Receptacle_ShouHan_TYPE-C-6PFS-2JCB1.6-H6.7_IPX8
J2_0, J2_1, J2_2, J2_3: SWD pads; SWD_Pads_1x4_P2.54
JP1_0, JP1_1, JP1_2, JP1_3: I_MEAS (cut to measure); SolderJumper-2_P1.3mm_Bridged_Pad1.0x1.5mm
JP2_0, JP2_1, JP2_2, JP2_3: RESET pads; TweezerPads_2x0.8mm_Gap0.4mm
KiKit_FID_B_1, KiKit_FID_B_2, KiKit_FID_B_3: Fiducial
KiKit_FID_T_1, KiKit_FID_T_2, KiKit_FID_T_3: Fiducial
KiKit_MB_1_1, KiKit_MB_1_2, KiKit_MB_1_3, KiKit_MB_1_4, KiKit_MB_1_5, KiKit_MB_1_6, KiKit_MB_2_1, KiKit_MB_2_2, KiKit_MB_2_3, KiKit_MB_2_4, KiKit_MB_2_5, KiKit_MB_3_1, KiKit_MB_3_2, KiKit_MB_3_3, KiKit_MB_3_4, KiKit_MB_3_5, KiKit_MB_3_6, KiKit_MB_4_2, KiKit_MB_4_3, KiKit_MB_4_4, KiKit_MB_4_5, KiKit_MB_4_6, KiKit_MB_5_1, KiKit_MB_5_2, KiKit_MB_5_3, KiKit_MB_5_4, KiKit_MB_5_5, KiKit_MB_5_6, KiKit_MB_6_1, KiKit_MB_6_2, KiKit_MB_6_3, KiKit_MB_6_4, KiKit_MB_6_5, KiKit_MB_7_1, KiKit_MB_7_2, KiKit_MB_7_3, KiKit_MB_7_4, KiKit_MB_7_5, KiKit_MB_7_6, KiKit_MB_8_2, KiKit_MB_8_3, KiKit_MB_8_4, KiKit_MB_8_5, KiKit_MB_8_6, KiKit_MB_9_1, KiKit_MB_9_2, KiKit_MB_9_3, KiKit_MB_9_4, KiKit_MB_9_5, KiKit_MB_9_6, KiKit_MB_10_1, KiKit_MB_10_2, KiKit_MB_10_3, KiKit_MB_10_4, KiKit_MB_10_5, KiKit_MB_11_1, KiKit_MB_11_2, KiKit_MB_11_3, KiKit_MB_11_4, KiKit_MB_11_5, KiKit_MB_11_6, KiKit_MB_12_2, KiKit_MB_12_3, KiKit_MB_12_4, KiKit_MB_12_5, KiKit_MB_12_6, KiKit_MB_13_1, KiKit_MB_13_2, KiKit_MB_13_3, KiKit_MB_13_4, KiKit_MB_13_5, KiKit_MB_13_6, KiKit_MB_14_1, KiKit_MB_14_2, KiKit_MB_14_3, KiKit_MB_14_4, KiKit_MB_14_5, KiKit_MB_15_1, KiKit_MB_15_2, KiKit_MB_15_3, KiKit_MB_15_4, KiKit_MB_15_5, KiKit_MB_15_6, KiKit_MB_16_2, KiKit_MB_16_3, KiKit_MB_16_4, KiKit_MB_16_5, KiKit_MB_16_6, KiKit_MB_17_2, KiKit_MB_17_3, KiKit_MB_18_2, KiKit_MB_18_3, KiKit_MB_19_2, KiKit_MB_19_3, KiKit_MB_20_2, KiKit_MB_20_3, KiKit_MB_20_4, KiKit_MB_20_5, KiKit_MB_20_6, KiKit_MB_20_7, KiKit_MB_21_2, KiKit_MB_21_3, KiKit_MB_21_4, KiKit_MB_21_5, KiKit_MB_21_6, KiKit_MB_21_7, KiKit_MB_22_2, KiKit_MB_22_3, KiKit_MB_22_4, KiKit_MB_22_5, KiKit_MB_22_6, KiKit_MB_22_7, KiKit_MB_23_2, KiKit_MB_23_3, KiKit_MB_23_4, KiKit_MB_23_5, KiKit_MB_23_6, KiKit_MB_23_7, KiKit_MB_24_2, KiKit_MB_24_3, KiKit_MB_24_4, KiKit_MB_24_5, KiKit_MB_24_6, KiKit_MB_24_7, KiKit_MB_25_2, KiKit_MB_25_3, KiKit_MB_25_4, KiKit_MB_25_5, KiKit_MB_25_6, KiKit_MB_25_7, KiKit_MB_26_2, KiKit_MB_26_3, KiKit_MB_26_4, KiKit_MB_26_5, KiKit_MB_26_6, KiKit_MB_26_7, KiKit_MB_27_2, KiKit_MB_27_3, KiKit_MB_27_4, KiKit_MB_27_5, KiKit_MB_27_6, KiKit_MB_27_7: NPTH
KiKit_TO_1, KiKit_TO_2, KiKit_TO_3: NPTH
Q1_0, Q1_1, Q1_2, Q1_3: DMN63D8LDW; SOT-363_SC-70-6
Q2_0, Q2_1, Q2_2, Q2_3: DMN2004DWK; SOT-363_SC-70-6
R1_0, R1_1, R1_2, R1_3: 47k 1%; R_0402_1005Metric
R2_0, R2_1, R2_2, R2_3: 1M; R_0402_1005Metric
R3_0, R3_1, R3_2, R3_3: 100k; R_0402_1005Metric
R4_0, R4_1, R4_2, R4_3, R9_0, R9_1, R9_2, R9_3: 1k; R_0402_1005Metric
R7_0, R7_1, R7_2, R7_3: 330R; R_0402_1005Metric
R8_0, R8_1, R8_2, R8_3: 2.2k; R_0402_1005Metric
R10_0, R10_1, R10_2, R10_3, R11_0, R11_1, R11_2, R11_3: 5.1k 1%; R_0402_1005Metric
U1_0, U1_1, U1_2, U1_3: BMD-340-A-R; u-blox_BMD-340
U2_0, U2_1, U2_2, U2_3: LSM6DSO32XTR; LGA-14_3x2.5mm_P0.5mm_LayoutBorder3x4y
U3_0, U3_1, U3_2, U3_3: MCP73831T-2ACI/OT; SOT-23-5
U4_0, U4_1, U4_2, U4_3: BQ29700DSER; WSON-6_1.5x1.5mm_P0.5mm

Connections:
Board_0-/ACC_INT1: U1_0.19 (P0.03), U2_0.4 (INT1)
Board_0-/BAT_N: BT1_0.2 (-), C8_0.2, Q2_0.4 (S), U4_0.4 (VSS)
Board_0-/BAT_P: BT1_0.1 (+), JP1_0.1 (A)
Board_0-/BTN: JP2_0.1 (A), U1_0.7 (P0.26)
Board_0-/CC1: J1_0.A5 (CC1), R10_0.1
Board_0-/CC2: J1_0.B5 (CC2), R11_0.1
Board_0-/CHG_INH: Q1_0.5 (G), R3_0.1, U1_0.27 (P0.11)
Board_0-/CHG_STAT: D2_0.2 (A), U1_0.33 (P0.15)
Board_0-/GND: C1_0.2, C2_0.2, C3_0.2, C4_0.2, C6_0.2, C7_0.2, C9_0.2, D3_0.1 (A1), D4_0.1 (K), J1_0.A12 (GND), J1_0.B12 (GND), J1_0.SH (SHIELD), J2_0.4, JP2_0.2 (B), Q1_0.1 (S), Q1_0.4 (S), Q2_0.1 (S), R3_0.2, R8_0.2, R10_0.2, R11_0.2, U1_0.1 (GND), U1_0.2 (GND), U1_0.3 (GND), U1_0.4 (GND), U1_0.5 (GND), U1_0.16 (GND), U1_0.18 (GND), U1_0.29 (GND), U1_0.30 (GND), U1_0.45 (GND), U1_0.46 (GND), U1_0.47 (GND), U1_0.55 (GND), U2_0.1 (SDO/SA0), U2_0.2 (SDX), U2_0.3 (SCX), U2_0.6 (GND), U2_0.7 (GND), U3_0.2 (V_{SS})
Board_0-/LED_A: D4_0.2 (A), R4_0.2
Board_0-/LED_IO: R4_0.1, U1_0.31 (P0.13)
Board_0-/PCM_BAT: C8_0.1, R7_0.2, U4_0.5 (BAT)
Board_0-/PCM_COUT: Q2_0.2 (G), U4_0.2 (Cout)
Board_0-/PCM_D: Q2_0.3 (D), Q2_0.6 (D)
Board_0-/PCM_DOUT: Q2_0.5 (G), U4_0.3 (Dout)
Board_0-/PCM_VM: R8_0.1, U4_0.6 (V-)
Board_0-/PROG: R1_0.1, U3_0.5 (PROG)
Board_0-/PROG_SW: Q1_0.6 (D), R1_0.2
Board_0-/Q1_GATE: Q1_0.2 (G), Q1_0.3 (D), R2_0.2
Board_0-/SCL: U1_0.23 (P0.07), U2_0.13 (SCL)
Board_0-/SDA: U1_0.21 (P0.05), U2_0.14 (SDA)
Board_0-/STAT: D2_0.1 (K), U3_0.1 (STAT)
Board_0-/SWDCLK: J2_0.3, U1_0.43 (SWCLK)
Board_0-/SWDIO: J2_0.2, U1_0.44 (SWDIO)
Board_0-/VBAT: C2_0.1, C3_0.1, JP1_0.2 (B), R7_0.1, U1_0.65 (VCCH), U3_0.3 (V_{BAT})
Board_0-/VBUS_SNS: C9_0.1, R9_0.2, U1_0.66 (VBUS)
Board_0-/VDD: C4_0.1, C6_0.1, C7_0.1, J2_0.1, U1_0.17 (VCC), U2_0.5 (VDDIO), U2_0.8 (VDD), U2_0.12 (CS)
Board_0-/VIN: C1_0.1, D1_0.1 (K), R2_0.1, R9_0.1, U3_0.4 (V_{DD})
Board_0-/VIN_RAW: D1_0.2 (A), D3_0.2 (A2), J1_0.A9 (VBUS), J1_0.B9 (VBUS)
Board_1-/ACC_INT1: U1_1.19 (P0.03), U2_1.4 (INT1)
Board_1-/BAT_N: BT1_1.2 (-), C8_1.2, Q2_1.4 (S), U4_1.4 (VSS)
Board_1-/BAT_P: BT1_1.1 (+), JP1_1.1 (A)
Board_1-/BTN: JP2_1.1 (A), U1_1.7 (P0.26)
Board_1-/CC1: J1_1.A5 (CC1), R10_1.1
Board_1-/CC2: J1_1.B5 (CC2), R11_1.1
Board_1-/CHG_INH: Q1_1.5 (G), R3_1.1, U1_1.27 (P0.11)
Board_1-/CHG_STAT: D2_1.2 (A), U1_1.33 (P0.15)
Board_1-/GND: C1_1.2, C2_1.2, C3_1.2, C4_1.2, C6_1.2, C7_1.2, C9_1.2, D3_1.1 (A1), D4_1.1 (K), J1_1.A12 (GND), J1_1.B12 (GND), J1_1.SH (SHIELD), J2_1.4, JP2_1.2 (B), Q1_1.1 (S), Q1_1.4 (S), Q2_1.1 (S), R3_1.2, R8_1.2, R10_1.2, R11_1.2, U1_1.1 (GND), U1_1.2 (GND), U1_1.3 (GND), U1_1.4 (GND), U1_1.5 (GND), U1_1.16 (GND), U1_1.18 (GND), U1_1.29 (GND), U1_1.30 (GND), U1_1.45 (GND), U1_1.46 (GND), U1_1.47 (GND), U1_1.55 (GND), U2_1.1 (SDO/SA0), U2_1.2 (SDX), U2_1.3 (SCX), U2_1.6 (GND), U2_1.7 (GND), U3_1.2 (V_{SS})
Board_1-/LED_A: D4_1.2 (A), R4_1.2
Board_1-/LED_IO: R4_1.1, U1_1.31 (P0.13)
Board_1-/PCM_BAT: C8_1.1, R7_1.2, U4_1.5 (BAT)
Board_1-/PCM_COUT: Q2_1.2 (G), U4_1.2 (Cout)
Board_1-/PCM_D: Q2_1.3 (D), Q2_1.6 (D)
Board_1-/PCM_DOUT: Q2_1.5 (G), U4_1.3 (Dout)
Board_1-/PCM_VM: R8_1.1, U4_1.6 (V-)
Board_1-/PROG: R1_1.1, U3_1.5 (PROG)
Board_1-/PROG_SW: Q1_1.6 (D), R1_1.2
Board_1-/Q1_GATE: Q1_1.2 (G), Q1_1.3 (D), R2_1.2
Board_1-/SCL: U1_1.23 (P0.07), U2_1.13 (SCL)
Board_1-/SDA: U1_1.21 (P0.05), U2_1.14 (SDA)
Board_1-/STAT: D2_1.1 (K), U3_1.1 (STAT)
Board_1-/SWDCLK: J2_1.3, U1_1.43 (SWCLK)
Board_1-/SWDIO: J2_1.2, U1_1.44 (SWDIO)
Board_1-/VBAT: C2_1.1, C3_1.1, JP1_1.2 (B), R7_1.1, U1_1.65 (VCCH), U3_1.3 (V_{BAT})
Board_1-/VBUS_SNS: C9_1.1, R9_1.2, U1_1.66 (VBUS)
Board_1-/VDD: C4_1.1, C6_1.1, C7_1.1, J2_1.1, U1_1.17 (VCC), U2_1.5 (VDDIO), U2_1.8 (VDD), U2_1.12 (CS)
Board_1-/VIN: C1_1.1, D1_1.1 (K), R2_1.1, R9_1.1, U3_1.4 (V_{DD})
Board_1-/VIN_RAW: D1_1.2 (A), D3_1.2 (A2), J1_1.A9 (VBUS), J1_1.B9 (VBUS)
Board_2-/ACC_INT1: U1_2.19 (P0.03), U2_2.4 (INT1)
Board_2-/BAT_N: BT1_2.2 (-), C8_2.2, Q2_2.4 (S), U4_2.4 (VSS)
Board_2-/BAT_P: BT1_2.1 (+), JP1_2.1 (A)
Board_2-/BTN: JP2_2.1 (A), U1_2.7 (P0.26)
Board_2-/CC1: J1_2.A5 (CC1), R10_2.1
Board_2-/CC2: J1_2.B5 (CC2), R11_2.1
Board_2-/CHG_INH: Q1_2.5 (G), R3_2.1, U1_2.27 (P0.11)
Board_2-/CHG_STAT: D2_2.2 (A), U1_2.33 (P0.15)
Board_2-/GND: C1_2.2, C2_2.2, C3_2.2, C4_2.2, C6_2.2, C7_2.2, C9_2.2, D3_2.1 (A1), D4_2.1 (K), J1_2.A12 (GND), J1_2.B12 (GND), J1_2.SH (SHIELD), J2_2.4, JP2_2.2 (B), Q1_2.1 (S), Q1_2.4 (S), Q2_2.1 (S), R3_2.2, R8_2.2, R10_2.2, R11_2.2, U1_2.1 (GND), U1_2.2 (GND), U1_2.3 (GND), U1_2.4 (GND), U1_2.5 (GND), U1_2.16 (GND), U1_2.18 (GND), U1_2.29 (GND), U1_2.30 (GND), U1_2.45 (GND), U1_2.46 (GND), U1_2.47 (GND), U1_2.55 (GND), U2_2.1 (SDO/SA0), U2_2.2 (SDX), U2_2.3 (SCX), U2_2.6 (GND), U2_2.7 (GND), U3_2.2 (V_{SS})
Board_2-/LED_A: D4_2.2 (A), R4_2.2
Board_2-/LED_IO: R4_2.1, U1_2.31 (P0.13)
Board_2-/PCM_BAT: C8_2.1, R7_2.2, U4_2.5 (BAT)
Board_2-/PCM_COUT: Q2_2.2 (G), U4_2.2 (Cout)
Board_2-/PCM_D: Q2_2.3 (D), Q2_2.6 (D)
Board_2-/PCM_DOUT: Q2_2.5 (G), U4_2.3 (Dout)
Board_2-/PCM_VM: R8_2.1, U4_2.6 (V-)
Board_2-/PROG: R1_2.1, U3_2.5 (PROG)
Board_2-/PROG_SW: Q1_2.6 (D), R1_2.2
Board_2-/Q1_GATE: Q1_2.2 (G), Q1_2.3 (D), R2_2.2
Board_2-/SCL: U1_2.23 (P0.07), U2_2.13 (SCL)
Board_2-/SDA: U1_2.21 (P0.05), U2_2.14 (SDA)
Board_2-/STAT: D2_2.1 (K), U3_2.1 (STAT)
Board_2-/SWDCLK: J2_2.3, U1_2.43 (SWCLK)
Board_2-/SWDIO: J2_2.2, U1_2.44 (SWDIO)
Board_2-/VBAT: C2_2.1, C3_2.1, JP1_2.2 (B), R7_2.1, U1_2.65 (VCCH), U3_2.3 (V_{BAT})
Board_2-/VBUS_SNS: C9_2.1, R9_2.2, U1_2.66 (VBUS)
Board_2-/VDD: C4_2.1, C6_2.1, C7_2.1, J2_2.1, U1_2.17 (VCC), U2_2.5 (VDDIO), U2_2.8 (VDD), U2_2.12 (CS)
Board_2-/VIN: C1_2.1, D1_2.1 (K), R2_2.1, R9_2.1, U3_2.4 (V_{DD})
Board_2-/VIN_RAW: D1_2.2 (A), D3_2.2 (A2), J1_2.A9 (VBUS), J1_2.B9 (VBUS)
Board_3-/ACC_INT1: U1_3.19 (P0.03), U2_3.4 (INT1)
Board_3-/BAT_N: BT1_3.2 (-), C8_3.2, Q2_3.4 (S), U4_3.4 (VSS)
Board_3-/BAT_P: BT1_3.1 (+), JP1_3.1 (A)
Board_3-/BTN: JP2_3.1 (A), U1_3.7 (P0.26)
Board_3-/CC1: J1_3.A5 (CC1), R10_3.1
Board_3-/CC2: J1_3.B5 (CC2), R11_3.1
Board_3-/CHG_INH: Q1_3.5 (G), R3_3.1, U1_3.27 (P0.11)
Board_3-/CHG_STAT: D2_3.2 (A), U1_3.33 (P0.15)
Board_3-/GND: C1_3.2, C2_3.2, C3_3.2, C4_3.2, C6_3.2, C7_3.2, C9_3.2, D3_3.1 (A1), D4_3.1 (K), J1_3.A12 (GND), J1_3.B12 (GND), J1_3.SH (SHIELD), J2_3.4, JP2_3.2 (B), Q1_3.1 (S), Q1_3.4 (S), Q2_3.1 (S), R3_3.2, R8_3.2, R10_3.2, R11_3.2, U1_3.1 (GND), U1_3.2 (GND), U1_3.3 (GND), U1_3.4 (GND), U1_3.5 (GND), U1_3.16 (GND), U1_3.18 (GND), U1_3.29 (GND), U1_3.30 (GND), U1_3.45 (GND), U1_3.46 (GND), U1_3.47 (GND), U1_3.55 (GND), U2_3.1 (SDO/SA0), U2_3.2 (SDX), U2_3.3 (SCX), U2_3.6 (GND), U2_3.7 (GND), U3_3.2 (V_{SS})
Board_3-/LED_A: D4_3.2 (A), R4_3.2
Board_3-/LED_IO: R4_3.1, U1_3.31 (P0.13)
Board_3-/PCM_BAT: C8_3.1, R7_3.2, U4_3.5 (BAT)
Board_3-/PCM_COUT: Q2_3.2 (G), U4_3.2 (Cout)
Board_3-/PCM_D: Q2_3.3 (D), Q2_3.6 (D)
Board_3-/PCM_DOUT: Q2_3.5 (G), U4_3.3 (Dout)
Board_3-/PCM_VM: R8_3.1, U4_3.6 (V-)
Board_3-/PROG: R1_3.1, U3_3.5 (PROG)
Board_3-/PROG_SW: Q1_3.6 (D), R1_3.2
Board_3-/Q1_GATE: Q1_3.2 (G), Q1_3.3 (D), R2_3.2
Board_3-/SCL: U1_3.23 (P0.07), U2_3.13 (SCL)
Board_3-/SDA: U1_3.21 (P0.05), U2_3.14 (SDA)
Board_3-/STAT: D2_3.1 (K), U3_3.1 (STAT)
Board_3-/SWDCLK: J2_3.3, U1_3.43 (SWCLK)
Board_3-/SWDIO: J2_3.2, U1_3.44 (SWDIO)
Board_3-/VBAT: C2_3.1, C3_3.1, JP1_3.2 (B), R7_3.1, U1_3.65 (VCCH), U3_3.3 (V_{BAT})
Board_3-/VBUS_SNS: C9_3.1, R9_3.2, U1_3.66 (VBUS)
Board_3-/VDD: C4_3.1, C6_3.1, C7_3.1, J2_3.1, U1_3.17 (VCC), U2_3.5 (VDDIO), U2_3.8 (VDD), U2_3.12 (CS)
Board_3-/VIN: C1_3.1, D1_3.1 (K), R2_3.1, R9_3.1, U3_3.4 (V_{DD})
Board_3-/VIN_RAW: D1_3.2 (A), D3_3.2 (A2), J1_3.A9 (VBUS), J1_3.B9 (VBUS)

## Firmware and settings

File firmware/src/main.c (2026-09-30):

/*
 * main.c - ShotPuck application.
 *
 * Event loop on one thread; all I2C and flash work happens here. ISRs and
 * BT callbacks only set flags / queue messages and give wake_sem.
 *
 *   IDLE   : LSM6DSO32 accelerometer at 12.5 Hz with wake interrupt, gyro
 *            off, CPU asleep. Advertising stops ADV_LINGER_MS after IDLE.
 *   ACTIVE : 416 Hz accel + gyro FIFO -> shot_detect.c and the capture
 *            ring; advertising / connected. Back to IDLE after
 *            cfg.idle_timeout_ms of stillness.
 */
#include <app_version.h>
#include <string.h>
#include <zephyr/drivers/gpio.h>
#include <zephyr/kernel.h>
#include <zephyr/logging/log.h>
#include <zephyr/sys/atomic.h>
#include <zephyr/sys/byteorder.h>

#include "accel.h"
#include "ble.h"
#include "capture.h"
#include "capture_tx.h"
#include "chg_led.h"
#include "claim.h"
#include "event_tx.h"
#include "factory.h"
#include "ota.h"
#include "power.h"
#include "protocol.h"
#include "shot_detect.h"
#include "store.h"

LOG_MODULE_REGISTER(main, LOG_LEVEL_INF);

#define FW_MAJOR APP_VERSION_MAJOR
#define FW_MINOR APP_VERSION_MINOR
#define ADV_LINGER_MS 120000
#define HOUSEKEEP_ACTIVE_MS 10000
#define HOUSEKEEP_IDLE_MS 60000
#define FIFO_BATCH_SAMPLES 32
#define FIFO_WATERMARK_SAMPLES 26
#define FIFO_DRAIN_ROUNDS 4
#define CTRL_SEQ_MSG_LEN 5
#define TX_POLL_MS 20
#define ACTIVE_POLL_MS 1000
#define IDLE_POLL_MS 2000
#define CLAIM_POLL_MS 250
#define CHARGER_POLL_MS 500
#define PAD_POLL_MS 250
#define CLAIM_BLINK_PERIOD_MS 1000
#define CLAIM_BLINK_MS 30
#define PAIRED_BLINKS 2
#define PAIRED_BLINK_MS 60

static const struct gpio_dt_spec led = GPIO_DT_SPEC_GET(DT_ALIAS(led0), gpios);

static K_SEM_DEFINE(wake_sem, 0, 1);
static atomic_t accel_pending;
static atomic_t conn_event;

struct ctrl_msg {
	uint8_t len;
	uint8_t data[16];
};
K_MSGQ_DEFINE(ctrl_q, sizeof(struct ctrl_msg), 4, 4);

static store_t st;
static cap_t cap;
static sd_state_t det;
static sp_config_t pending_cfg;
static atomic_t cfg_pending;

static int64_t unix_offset_ms;
static bool time_set;

static uint32_t active_start_ms;
static uint32_t sample_idx;
static uint32_t idle_since_ms;

/* ---------------------------------------------------------------- utils */

static void led_pulse(int ms)
{
	gpio_pin_set_dt(&led, 1);
	k_msleep(ms);
	gpio_pin_set_dt(&led, 0);
}

static void cfg_to_wire(const sd_config_t *c, sp_config_t *w)
{
	w->version = PROTO_VERSION;
	w->trig_hf_mg = (uint16_t)c->trig_hf_mg;
	w->move_mg = (uint16_t)c->move_mg;
	w->pre_still_min_ms = c->pre_still_min_ms;
	w->post_start_ms = c->post_start_ms;
	w->post_end_ms = c->post_end_ms;
	w->post_lf_min_mg = (uint16_t)c->post_lf_min_mg;
	w->refractory_ms = c->refractory_ms;
	w->wake_mg = (uint16_t)c->wake_mg;
	w->idle_timeout_s = (uint16_t)(c->idle_timeout_ms / 1000);
}

static void wire_to_cfg(const sp_config_t *w, sd_config_t *c)
{
	c->trig_hf_mg = w->trig_hf_mg;
	c->move_mg = w->move_mg;
	c->pre_still_min_ms = w->pre_still_min_ms;
	c->post_start_ms = w->post_start_ms;
	c->post_end_ms = w->post_end_ms;
	c->post_lf_min_mg = w->post_lf_min_mg;
	c->refractory_ms = w->refractory_ms;
	c->wake_mg = w->wake_mg;
	c->idle_timeout_ms = (uint32_t)w->idle_timeout_s * 1000u;
}

static bool cfg_valid(const sp_config_t *w)
{
	return w->trig_hf_mg >= 1000 && w->trig_hf_mg <= 30000 &&
	       w->move_mg >= 50 && w->move_mg <= 2000 &&
	       w->pre_still_min_ms <= 10000 &&
	       w->post_start_ms < w->post_end_ms && w->post_end_ms <= 1500 &&
	       w->post_lf_min_mg <= 5000 &&
	       w->refractory_ms >= 200 && w->refractory_ms <= 10000 &&
	       w->wake_mg >= 16 && w->wake_mg <= 2000 &&
	       w->idle_timeout_s >= 5 && w->idle_timeout_s <= 3600;
}

static void publish_count(void)
{
	sp_count_t c = {.total = st.total, .last_seq = st.seq};
	ble_update_count(&c);
}

static void publish_status(void)
{
	const power_state_t *p = power_state();
	sp_status_t s = {
		.battery_pct = p->battery_pct,
		.battery_mv = p->battery_mv,
		.temp_c = p->temp_c,
		.flags = (p->vbus ? SP_ST_VBUS : 0) | (p->charging ? SP_ST_CHARGING : 0) |
			 (p->chg_inhibit ? SP_ST_CHG_INHIBIT : 0) |
			 (det.mode == SD_MODE_ACTIVE ? SP_ST_ACTIVE : 0) |
			 (time_set ? SP_ST_TIME_SET : 0),
		.fw_major = FW_MAJOR,
		.fw_minor = FW_MINOR,
	};
	ble_update_status(&s);
}

/* ---------------------------------------------------------- callbacks */

static void accel_isr(void)
{
	atomic_set(&accel_pending, 1);
	k_sem_give(&wake_sem);
}

static void on_ctrl(const uint8_t *data, uint16_t len)
{
	struct ctrl_msg m = {.len = (uint8_t)MIN(len, sizeof(m.data))};
	memcpy(m.data, data, m.len);
	if (k_msgq_put(&ctrl_q, &m, K_NO_WAIT) == 0) {
		k_sem_give(&wake_sem);
	}
}

static int on_cfg(const sp_config_t *c)
{
	if (!cfg_valid(c)) {
		return -EINVAL;
	}
	pending_cfg = *c;
	atomic_set(&cfg_pending, 1);
	k_sem_give(&wake_sem);
	return 0;
}

static void on_tx_done(void)
{
	k_sem_give(&wake_sem);
}

static void on_conn(bool connected)
{
	ARG_UNUSED(connected);
	atomic_set(&conn_event, 1);
	k_sem_give(&wake_sem);
}

/* -------------------------------------------------------------- modes */

static void go_active(void)
{
	accel_set_active();
	active_start_ms = k_uptime_get_32();
	sample_idx = 0;
	cap_reset(&cap);
	sd_start_active(&det, active_start_ms);
	ble_adv_start();
	LOG_INF("ACTIVE");
}

static void go_idle(void)
{
	accel_set_idle((uint16_t)st.cfg.wake_mg);
	det.mode = SD_MODE_IDLE;
	idle_since_ms = k_uptime_get_32();
	store_save_counts(&st);
	LOG_INF("IDLE");
}

/* ------------------------------------------------------------- events */

static void request_capture(const sd_event_t *e, uint32_t seq)
{
	cap_request_t req = {.seq = seq, .trigger_index = cap_ms_to_index(e->t_ms - active_start_ms)};

	if (cap_request(&cap, &req) == CAP_NO_SLOT) {
		LOG_WRN("no capture for seq %u", seq);
	}
}

static void handle_detection(const sd_event_t *e, uint32_t uptime_ms)
{
	sp_event_t w = {
		.seq = ++st.seq,
		.t_unix_ms = time_set ? unix_offset_ms + uptime_ms : 0,
		.t_uptime_ms = uptime_ms,
		.peak_hf_mg = e->peak_hf_mg,
		.pre_still_ms = e->pre_still_ms,
		.post_lf_mg = e->post_lf_mg,
		.accepted = e->accepted,
		.reason = e->reason,
	};
	event_tx_record(&w);
	if (e->accepted) {
		st.total++;
		store_save_counts(&st);
		publish_count();
		request_capture(e, w.seq);
		led_pulse(20);
		LOG_INF("SHOT #%u pk=%u still=%u lf=%u", st.total, e->peak_hf_mg,
			e->pre_still_ms, e->post_lf_mg);
	} else {
		LOG_INF("reject r=%u pk=%u still=%u lf=%u", e->reason, e->peak_hf_mg,
			e->pre_still_ms, e->post_lf_mg);
	}
}

static uint32_t sample_ms(uint32_t index)
{
	return active_start_ms + cap_index_to_ms(index);
}

static void restart_stream(uint32_t now)
{
	LOG_WRN("FIFO overrun");
	active_start_ms = now;
	sample_idx = 0;
	cap_reset(&cap);
	sd_start_active(&det, now);
}

static void process_batch(const accel_fifo_t *fifo, uint32_t n)
{
	uint32_t now = k_uptime_get_32();
	uint32_t t_last = sample_ms(sample_idx + n - 1u);

	for (uint32_t i = 0; i < n; i++) {
		int16_t mg[3];
		sd_event_t e;
		int slot = cap_push(&cap, &fifo->samples[i]);

		if (slot != CAP_NO_SLOT) {
			cap_tx_queue(cap.slots[slot].seq);
		}
		accel_to_mg(&fifo->samples[i], mg);
		if (sd_process(&det, mg, sample_ms(sample_idx++), &e)) {
			handle_detection(&e, now - (t_last - e.t_ms));
		}
	}
}

static void handle_accel(void)
{
	static sp_cap_sample_t buf[FIFO_BATCH_SAMPLES];
	accel_fifo_t fifo = {.samples = buf, .max = FIFO_BATCH_SAMPLES};

	if (accel_mode() == ACCEL_IDLE) {
		if (accel_clear_wake() > 0) {
			go_active();
		} else {
			accel_irq_rearm();
		}
		return;
	}
	if (accel_mode() != ACCEL_ACTIVE) {
		return;
	}
	for (int round = 0; round < FIFO_DRAIN_ROUNDS; round++) {
		int n = accel_read_fifo(&fifo);
		if (n <= 0) {
			break;
		}
		if (fifo.overrun) {
			restart_stream(k_uptime_get_32());
		}
		process_batch(&fifo, (uint32_t)n);
		if (n < FIFO_WATERMARK_SAMPLES) {
			break;
		}
	}
	if (sd_active_should_sleep(&det, sample_ms(sample_idx))) {
		go_idle();
	} else {
		accel_irq_rearm();
	}
}

static void handle_ctrl(void)
{
	struct ctrl_msg m;

	while (k_msgq_get(&ctrl_q, &m, K_NO_WAIT) == 0) {
		switch (m.data[0]) {
		case SP_CTRL_SET_TIME:
			if (m.len >= 9) {
				int64_t unix_ms = (int64_t)sys_get_le64(&m.data[1]);
				unix_offset_ms = unix_ms - k_uptime_get();
				time_set = true;
				publish_status();
			}
			break;
		case SP_CTRL_RESET_COUNT:
			st.total = 0;
			store_save_counts(&st);
			publish_count();
			break;
		case SP_CTRL_REPLAY:
			if (m.len >= 5) {
				event_tx_replay(sys_get_le32(&m.data[1]));
			}
			break;
		case SP_CTRL_FACTORY_CFG: {
			sp_config_t w;
			sd_default_config(&st.cfg);
			det.cfg = st.cfg;
			store_save_cfg(&st);
			cfg_to_wire(&st.cfg, &w);
			ble_update_config(&w);
			break;
		}
		case SP_CTRL_GET_CAPTURE:
			if (m.len >= CTRL_SEQ_MSG_LEN) {
				cap_tx_queue(sys_get_le32(&m.data[1]));
			}
			break;
		case SP_CTRL_FORGET_BONDS:
			claim_forget_all();
			break;
		case SP_CTRL_LED_BLINK:
			for (int i = 0; i < 5; i++) {
				led_pulse(80);
				k_msleep(120);
			}
			break;
		default:
			break;
		}
	}
}

static void housekeeping(void)
{
	power_update();
	if (power_should_cutoff()) {
		store_save_counts(&st);
		accel_off();
		ble_adv_stop();
		power_off_until_charger();
	}
	publish_status();
}

static void claim_feedback(void)
{
	static uint32_t last_blink_ms;
	uint32_t now = k_uptime_get_32();

	if (claim_take_paired()) {
		for (int i = 0; i < PAIRED_BLINKS; i++) {
			led_pulse(PAIRED_BLINK_MS);
			k_msleep(PAIRED_BLINK_MS);
		}
	}
	if (claim_is_open() && now - last_blink_ms >= CLAIM_BLINK_PERIOD_MS) {
		last_blink_ms = now;
		led_pulse(CLAIM_BLINK_MS);
	}
}

static void charge_feedback(void)
{
	static uint32_t last_tick_ms;
	static bool steady;
	uint32_t now = k_uptime_get_32();

	if (!power_vbus_present() || claim_is_open()) {
		if (steady) {
			steady = false;
			gpio_pin_set_dt(&led, 0);
		}
		return;
	}
	if (now - last_tick_ms < CHG_LED_TICK_MS) {
		return;
	}
	last_tick_ms = now;
	chg_led_mode_t mode = chg_led_mode(power_update());
	steady = mode == CHG_LED_FULL;
	gpio_pin_set_dt(&led, steady ? 1 : 0);
	for (uint8_t i = 0; i < chg_led_pulses(mode); i++) {
		led_pulse(CHG_LED_PULSE_MS);
		k_msleep(CHG_LED_GAP_MS);
	}
}

static uint32_t poll_period(bool active)
{
	if (event_tx_busy() || cap_tx_busy()) {
		return TX_POLL_MS;
	}
	if (factory_pads_held()) {
		return PAD_POLL_MS;
	}
	if (claim_is_open()) {
		return CLAIM_POLL_MS;
	}
	if (power_vbus_present()) {
		return CHARGER_POLL_MS;
	}
	return active ? ACTIVE_POLL_MS : IDLE_POLL_MS;
}

/* --------------------------------------------------------------- main */

int main(void)
{
	sp_config_t w;

	power_regout0_3v0(); /* may reset once on first boot */
	factory_boot_guard();
	if (ota_init()) {
		LOG_ERR("watchdog unavailable");
	}

	gpio_pin_configure_dt(&led, GPIO_OUTPUT_INACTIVE);
	if (factory_pads_init()) {
		LOG_ERR("reset pads unavailable");
	}
	if (power_init() == 0) {
		power_update();
		if (power_should_cutoff()) {
			power_off_until_charger();
		}
	}

	sd_default_config(&st.cfg);
	store_init(&st);
	if (event_tx_init()) {
		LOG_ERR("shot log unavailable");
	}
	st.cfg.fs_hz = (float)CAP_ODR_HZ;
	sd_init(&det, &st.cfg);
	cap_init(&cap);
	cap_tx_init(&cap);
	ble_set_tx_done_cb(on_tx_done);

	cfg_to_wire(&st.cfg, &w);
	ble_update_config(&w);
	if (ble_init(on_ctrl, on_cfg, on_conn) || claim_init()) {
		LOG_ERR("BLE init failed");
	}
	publish_count();
	publish_status();

	if (accel_init(accel_isr)) {
		/* no sensor: blink SOS-ish forever, keep BLE up for diagnostics */
		ble_adv_start();
		for (;;) {
			if (ota_image_confirmed()) {
				ota_feed();
			}
			led_pulse(50);
			k_msleep(1000);
		}
	}
	led_pulse(200);
	go_active(); /* start awake so a phone can connect right after boot */

	uint32_t last_hk = k_uptime_get_32();

	for (;;) {
		bool active = det.mode == SD_MODE_ACTIVE;
		uint32_t hk_period = active ? HOUSEKEEP_ACTIVE_MS : HOUSEKEEP_IDLE_MS;

		k_sem_take(&wake_sem, K_MSEC(poll_period(active)));
		ota_feed();
		ota_confirm_when_healthy(ble_link_secured());

		if (atomic_cas(&accel_pending, 1, 0)) {
			handle_accel();
		}
		handle_ctrl();
		claim_poll(power_vbus_present());
		claim_feedback();
		factory_poll();
		if (!factory_pads_held()) {
			charge_feedback();
		}
		if (event_tx_busy()) {
			event_tx_pump();
		}
		if (cap_tx_busy()) {
			cap_tx_pump();
		}
		if (atomic_cas(&cfg_pending, 1, 0)) {
			wire_to_cfg(&pending_cfg, &st.cfg);
			det.cfg = st.cfg;
			store_save_cfg(&st);
			LOG_INF("config updated");
		}

		uint32_t now = k_uptime_get_32();
		bool in_linger = det.mode == SD_MODE_ACTIVE || (now - idle_since_ms) < ADV_LINGER_MS ||
				 claim_is_open();
		if (atomic_cas(&conn_event, 1, 0) || !ble_is_advertising()) {
			if (!ble_is_connected() && in_linger) {
				ble_adv_start();
			}
		}
		if (!in_linger && ble_is_advertising()) {
			ble_adv_stop();
		}
		if (now - last_hk >= hk_period) {
			last_hk = now;
			housekeeping();
		}
	}
	return 0;
}

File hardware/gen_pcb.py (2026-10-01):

#!/usr/bin/env python3
"""
gen_pcb.py - builds kicad/shotpuck.kicad_pcb from design.py + ../layout.json,
with the KiCad 10 pcbnew Python API.

  * round 2-layer board, 4 NPTH holes for the cap screws
  * custom footprints written to kicad/ShotPuck.pretty
  * placement from layout.json (big parts) and PLACE below (small parts)
  * keep-outs: antenna to board rim, cell notch + bolt-tube slot, screw bosses
  * GND pours both layers
  * routes with Freerouting if available (FREEROUTING_JAR), then DRC report

    python gen_pcb.py            # place + route + DRC
    python gen_pcb.py --no-route

Routing takes 1-5 min (Freerouting 2.1, Java 21: set JAVA and FREEROUTING_JAR).
"""
import json
import math
import os
import shutil
import re
import subprocess
import sys
import time

import pcbnew

import bmd340
import design
import board_shape as shape
import islands
import sexp
from gen_sch import U

HERE = os.path.dirname(os.path.abspath(__file__))
KI = os.path.join(HERE, "kicad")
LIB = os.path.join(KI, "ShotPuck.pretty")
STD = os.environ.get("KICAD10_FOOTPRINT_DIR", r"C:\Program Files\KiCad\10.0\share\kicad\footprints")
L = json.load(open(os.path.join(HERE, "..", "layout.json")))
JAR = os.environ.get("FREEROUTING_JAR", os.path.expanduser("~/tools/freerouting-2.1.0.jar"))
JAVA = os.environ.get("JAVA", os.path.expanduser("~/tools/jre21/bin/java.exe"))

MM = pcbnew.FromMM
CELL_PAD_W = 2.5
CELL_PAD_H = 2.0
CELL_COURTYARD = 0.3
PLUS_MARK_GAP = 0.3
PLUS_MARK_HALF = 0.6
CUTOUT_COPPER_KEEP = 0.35
CUTOUT_VIA_MARGIN = 0.65
ANTENNA_VIA_MARGIN = 0.6
ANTENNA_SEG_MARGIN = 0.3
ANTENNA_STITCH_MARGIN = 0.8
EDGE_WIDTH_MM = 0.1
BACK_TEXT_POS = (11.0, -6.0)
BOTTOM = "B"
TRACK_MM = 0.15
VIA_DIA_MM = 0.55
CLEARANCE_MM = 0.127
GND_NET = "GND"
SOLID_GND_REFS = {"U2", "J2", "Q2"}
ROUTER_JOB_MARGIN_S = 20
SECOND_PASS_SUFFIX = "-pass2.kicad_pcb"
PRE_ROUTED = [("Q2", "3", "6"), ("Q1", "4", "1")]
PRE_LINKS = [("U1", "21", "U2", "14", ((3.36, 13.75),)), ("U1", "23", "U2", "13", ()),
             ("U1", "19", "U2", "4", ((3.9, 14.77), (1.46, 16.92))),
             ("U1", "31", "R4", "1", ()),
             ("U4", "2", "Q2", "2", ()),
             ("Q1", "5", "R3", "1", ((-10.81, 2.2),)),
             ("U4", "3", "Q2", "5", ((-12.7, -7.6), (-12.1, -7.0), (-11.6, -6.3), (-9.0, -6.3), (-9.0, -8.2)))]
PRE_ROUTE_WIDTH_MM = 0.2
MODULE_BASE_ROT_DEG = 180
PRE_VIAS = [("U1", "43", (-0.25, -0.75)), ("U1", "44", (0.05, -1.55)), ("U1", "33", (0.0, -0.75)),
            ("U1", "17", (0.55, 0.55)), ("U1", "18", (1.15, -0.25)), ("Q2", "1", (0.55, 0.71))]
PAD_BRIDGES = [("U1", "45", "46"), ("U1", "2", "1"), ("U1", "4", "3"), ("U2", "1", "2"), ("U2", "3", "2")]
VIN_ESCAPE = None
TRACK_SAMPLE_MM = 0.3
FANOUT_TRACK_CLEAR_MM = 0.5
VIA_DRILL_MM = 0.3
SWD_PAD_DIA = 1.0
SWD_PITCH = 2.54
SWD_PADS = 4
SWD_COURTYARD = 0.5
MODEL_OVERRIDES = {"J1": ("${KIPRJMOD}/ShotPuck.3dshapes/USB_C_Receptacle_ShouHan_TYPE-C-6PFS-2JCB1.6-H6.7_IPX8.step",
                          (0.0, -1.93, 0.0), 0.0)}
BOARD_ATTEMPTS = 4
VIA_ECHO_TOL_MM = 0.01


def V(x, y):
    """board coords (mm, +y up) -> KiCad internal (y down)."""
    return pcbnew.VECTOR2I(MM(x), MM(-y))


# small parts: ref -> (x, y, rot_deg[, "B" for the bottom side])   board coords, viewed from top
PLACE = {
    "U2": (0.6, 15.0, 225), "C4": (4.4, 16.2, 45),
    "C3": (-1.1, 11.3, 45), "C6": (-2.72, 12.92, 45), "C7": (-0.1, 12.3, 135),
    "R9": (-3.3, 8.6, 42), "C9": (-2.4, 7.8, 42),
    "R4": (-0.6, 6.9, 225), "D4": (-16.95, 2.6, 90), "JP2": (11.77, 12.35, 135),
    "U3": (-12.4, -1.5, 0), "Q1": (-13.2, 2.2, 0), "R1": (-15.2, -1.5, 90), "R2": (-15.6, 1.6, 90),
    "R3": (-10.3, 2.2, 90), "D2": (-9.0, -1.3, 90),
    "C2": (-13.4, -4.1, 0), "JP1": (-10.2, -5.0, 0, BOTTOM), "R7": (-15.4, -5.3, 90),
    "U4": (-13.4, -8.65, 180), "Q2": (-10.6, -8.5, 0), "C8": (-13.6, -6.9, 0), "R8": (-15.2, -7.4, 90),
    "R10": (-6.1, 7.51, 312), "R11": (-6.83, 6.85, 312),
    "D3": (-5.41, 5.24, 42), "D1": (-7.7, 2.1, 42), "C1": (-8.79, 4.81, 42),
    "J2": (8.344, 10.748, 225, BOTTOM),
}


# ---------------------------------------------------------------- footprints
def pad(fp, num, shape, x, y, w, h, smd=True, drill=None, npth=False, layers=None):
    p = pcbnew.PAD(fp)
    p.SetNumber(num)
    p.SetShape(shape)
    p.SetSize(pcbnew.VECTOR2I(MM(w), MM(h)))
    p.SetPosition(pcbnew.VECTOR2I(MM(x), MM(y)))
    if npth:
        p.SetAttribute(pcbnew.PAD_ATTRIB_NPTH)
        p.SetDrillSize(pcbnew.VECTOR2I(MM(drill), MM(drill)))
        p.SetLayerSet(p.UnplatedHoleMask())
    elif smd:
        p.SetAttribute(pcbnew.PAD_ATTRIB_SMD)
        p.SetLayerSet(p.SMDMask())
    else:
        p.SetAttribute(pcbnew.PAD_ATTRIB_PTH)
        p.SetDrillSize(pcbnew.VECTOR2I(MM(drill), MM(drill)))
        p.SetLayerSet(p.PTHMask())
    fp.Add(p)
    return p


def line(fp, layer, x1, y1, x2, y2, w=0.12):
    s = pcbnew.PCB_SHAPE(fp, pcbnew.SHAPE_T_SEGMENT)
    s.SetStart(pcbnew.VECTOR2I(MM(x1), MM(y1)))
    s.SetEnd(pcbnew.VECTOR2I(MM(x2), MM(y2)))
    s.SetLayer(layer)
    s.SetWidth(MM(w))
    fp.Add(s)


def rect(fp, layer, w, h, w_line=0.05, cx=0.0, cy=0.0):
    x1, y1, x2, y2 = cx - w / 2, cy - h / 2, cx + w / 2, cy + h / 2
    for a in [(x1, y1, x2, y1), (x2, y1, x2, y2), (x2, y2, x1, y2), (x1, y2, x1, y1)]:
        line(fp, layer, *a, w=w_line)


def circle(fp, layer, r, w=0.05, cx=0.0, cy=0.0):
    s = pcbnew.PCB_SHAPE(fp, pcbnew.SHAPE_T_CIRCLE)
    s.SetCenter(pcbnew.VECTOR2I(MM(cx), MM(cy)))
    s.SetEnd(pcbnew.VECTOR2I(MM(cx + r), MM(cy)))
    s.SetLayer(layer)
    s.SetWidth(MM(w))
    fp.Add(s)


def new_fp(name, descr):
    fp = pcbnew.FOOTPRINT(None)
    fp.SetFPID(pcbnew.LIB_ID("ShotPuck", name))
    fp.SetLibDescription(descr)
    fp.Reference().SetLayer(pcbnew.F_Fab)
    fp.Value().SetLayer(pcbnew.F_Fab)
    return fp


def make_lib():
    os.makedirs(LIB, exist_ok=True)
    bmd340.save_footprint(LIB)
    cell_footprint()
    swd_footprint()

    b = L["bosses"]
    fp = new_fp("MountingHole_2.4mm_NPTH", "M2 clearance, cap boss Ø%.1f bears on board" % b["boss_dia"])
    pad(fp, "", pcbnew.PAD_SHAPE_CIRCLE, 0, 0, b["pcb_hole"], b["pcb_hole"], drill=b["pcb_hole"], npth=True)
    circle(fp, pcbnew.Cmts_User, b["boss_dia"] / 2)
    circle(fp, pcbnew.F_CrtYd, b["boss_dia"] / 2 + 0.25)
    pcbnew.FootprintSave(LIB, fp)

    open(os.path.join(KI, "fp-lib-table"), "w").write(
        '(fp_lib_table\n  (lib (name "ShotPuck")(type "KiCad")(uri "${KIPRJMOD}/ShotPuck.pretty")'
        '(options "")(descr "ShotPuck custom footprints"))\n)\n')


def swd_footprint():
    fp = new_fp("SWD_Pads_1x4_P2.54", "SWD test pads for a 4-pin 2.54 mm pogo jig: 1 VDD, 2 SWDIO, 3 SWDCLK, 4 GND.")
    first = -(SWD_PADS - 1) * SWD_PITCH / 2
    for i in range(SWD_PADS):
        pad(fp, str(i + 1), pcbnew.PAD_SHAPE_CIRCLE, first + i * SWD_PITCH, 0, SWD_PAD_DIA, SWD_PAD_DIA)
    rect(fp, pcbnew.F_CrtYd, (SWD_PADS - 1) * SWD_PITCH + SWD_PAD_DIA + SWD_COURTYARD, SWD_PAD_DIA + SWD_COURTYARD)
    pcbnew.FootprintSave(LIB, fp)
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

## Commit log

2026-09-26 Add ShotPuck v0.1 design package
    Firmware, simulation, hardware generators, KiCad outputs, fab files and
    mechanical model as delivered in shotpuck.zip.
    [assembly.step, base.step, base.stl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]
2026-09-26 Update ShotPuck to v0.2 design package
    Enhancements include the integration of the LSM6DSO32 IMU, which replaces the LIS2DE12 accelerometer, allowing for 6-axis motion capture. The new CAPTURE characteristic streams raw data around each shot, improving performance metrics. The firmware and simulation have been updated to support these changes, including adjustments to the BLE protocol (v2) for better data handling. Additionally, the toolchain has been migrated to a native Windows environment for development.
    Key changes:
    - Updated deliverable status to v0.2.
    - Added capture functionality for bow motion.
    - Adjusted simulation and validation processes to reflect new hardware capabilities.
    - E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
    [shotpuck-B_Cu.gbl, shotpuck-B_Mask.gbs, shotpuck-B_Paste.gbp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]
2026-09-27 Add OTA, nRF52840, PCM, magnetic connector, Ø36 board and JLC panel
    - Firmware: nRF52840 module (MDBT50Q-1MV2), MCUboot swap-using-move with
    ECDSA-P256 signed images, MCUmgr SMP over encrypted BLE, watchdog and
    self-confirm; 1 MB flash layout; release images shotpuck_full.hex and
    shotpuck_update.bin (v0.2.0).
    - Hardware: BQ29700 + DMN2004DWK cell protection, universal CP1654 pads,
    Samzo magnetic 2-pin connector, Ø36 mm board inside the Ø40 mm puck,
    0.3 mm vias, 2x2 KiKit panel and JLCPCB BOM/CPL (gen_panel.py, gen_jlc.py).
    - Mechanical: cavity sized for Varta CP1654 swell, connector chimney,
    optional brass Ø8 trim pins (balance reported with and without them).
    - gen_pcb.py: s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
    [assembly.step, base.step, base.stl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]
2026-09-27 Seat the cell in a PCB notch open to the rim (puck 10.45 mm)
    - The cell sits on the Kapton over the base in a notch in the PCB
    (Ø16.6 mm round end, open to the rim) instead of on top of the board,
    saving the 0.8 mm board thickness: 11.25 -> 10.45 mm, 19.8 g with the
    optional brass pins, 18.0 g without.
    - Rounded relief on the + side lets the bottom (+ can) tab bend up to the
    + pad; cell pads moved to ±10.2 mm.
    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
    [assembly.step, base.step, base.stl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]
2026-09-27 Remove obsolete firmware files and add new ShotPuck nRF52840 configuration and device tree source files. The new configuration includes GPIO, I2C settings, and MPU support, while the device tree defi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
    [base.step, base.stl]
2026-09-27 Update ShotPuck design to rev A: replace stud with flat plate, adjust dimensions, and enhance PCB layout
    - Redesigned the ShotPuck to use a 2.0 mm flat 6061 plate, bolted through a steel sleeve, improving manufacturability and cost.
    - Adjusted dimensions: puck height reduced to 9.90 mm, with a center of mass 0.85 mm off-axis.
    - Updated layout.json to reflect new design parameters, including cell placement and PCB notch.
    - Enhanced mechanical and electrical design files, including updated battery specifications (LIR1254) and revised component placements.
    - Improved documentation in HANDOVER.md and README.md to reflect changes in design and functionality.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
    [assembly.step, cap.step, cap.stl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]
2026-09-27 Refine ShotPuck design and PCB layout for improved manufacturability
    - Adjusted bolt tube hole diameter to Ø10.4 mm for JLCPCB tolerance.
    - Updated PCB layout to enhance ground strategy, ensuring GND SMD pads have stubs and vias before routing.
    - Revised antenna zone dimensions and keep-out areas to optimize routing space.
    - Enhanced documentation in HANDOVER.md and README.md to reflect design changes and assembly instructions.
    - Fixed minor discrepancies in layout.json and board_shape.py for consistency across design files.
    [assembly.step, cap.step, plate.step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]
2026-09-27 Enhance ShotPuck design with mechanical and layout improvements
    - Updated mechanical design in `puck.py` to include a stepped connector for improved fit and stability.
    - Revised `layout.json` to reflect new connector dimensions and added detailed descriptions for clarity.
    - Enhanced assembly instructions in `README.md` to specify RTV sealing around the connector.
    - Improved validation steps in `VALIDATION.md` to ensure reliable magnetic plug engagement and seal integrity.
    - Added new parameters in `geometry.py` for lip wall and gap to support design adjustments.
    [assembly.step, cap.step, cap.stl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]
2026-09-29 Refine ShotPuck design and documentation for improved functionality and clarity
    - Updated `HANDOVER.md` to clarify PCB routing and placement procedures, emphasizing the importance of running `gen_pcb.py --no-route` and `global_route.py` for optimal results.
    - Revised `README.md` to correct the center of mass measurement and enhance the description of the puck's dimensions.
    - Enhanced `VALIDATION.md` to reflect updated weight and balance metrics, ensuring accurate representation of the ShotPuck's specifications.
    - Adjusted `design.py` to include new charge-input protection details and updated component specifications for better clarity.
    - Improved `gen_bom.py` and `gen_jlc.py` to reflect chan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
    [assembly.step, cap.step, plate.step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]
2026-09-29 Update ShotPuck design to integrate u-blox BMD-340 module and enhance documentation
    - Replaced the Raytac MDBT50Q-1MV2 with the u-blox BMD-340-A-R-10 in the hardware design, updating relevant specifications in `HANDOVER.md`, `README.md`, and `VALIDATION.md`.
    - Adjusted pin mappings and configurations in firmware files to reflect the new module's layout and capabilities.
    - Enhanced `layout.json` and `design.py` to accommodate the new component dimensions and positions.
    - Updated the bill of materials and JLCPCB configurations in `gen_bom.py` and `gen_jlc.py` to ensure accurate sourcing of the new module.
    - Revised mechanical design parameters in `board_shape.py` to improve fit and stability.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
    [assembly.step, cap.step, cap.stl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]
2026-09-29 Refine ShotPuck design with updated component specifications and enhanced documentation
    - Updated `README.md` to clarify new component specifications and assembly instructions.
    - Revised `VALIDATION.md` to include updated performance metrics and validation steps.
    - Adjusted `design.py` to reflect changes in component layout and configurations.
    - Enhanced `gen_bom.py` and `gen_jlc.py` to ensure accurate sourcing of components.
    - Improved `layout.json` to accommodate new design parameters and dimensions.
    [shotpuck.kicad_pcb]
2026-09-29 Add USB-C side-port board variant
    - J1: side-mounted HRO TYPE-C-31-M-17 (6-pin, power only) replaces the
    magnetic Samzo connector; R10/R11 5.1k pull CC1/CC2 down. Footprint copy
    ShotPuck:..._NoFrontSilk drops the silkscreen outside the board edge.
    - Module slid 45 deg around the sleeve; copper-free right side
    (board_shape.rf_keepout), IMU and its caps moved next to the module.
    - Decoupling: C5 removed from board and schematic (the BMD-340 has 4.7 uF
    on VCC inside, C4 stays); C6/C7 moved next to IMU pins 8 and 5, C1 next
    to the charger input, vias moved out of U3's pads.
    - BT1 uses ShotPuck:LIR1254_Contacts_Edit (pad 2 at 270 deg).
    - Schematic: local power symbol ShotPuck:GND_LOCAL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
    [shotpuck.kicad_pcb, shotpuck.kicad_sch]
2026-09-30 Switch J1 to waterproof IPX8 USB-C (C3020041) and seal the cap
    - J1: SHOU HAN TYPE-C 6PFS 2JCB1.6-H6.7 IPX8 (LCSC C3020041), recessed
    into a 10.28 x 5.22 mm notch in the board edge at 132.58 deg, midway
    between H1 and H2. Footprint from the datasheet drawing (pads kept
    0.3/0.35 mm from the notch; the notch sides run through two 0.70 mm
    NPTH holes for the legs, since the datasheet's 0.69 mm U-slots cannot
    be routed); LCSC's STEP model shifted -1.93 mm onto the pads.
    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
    [assembly.step, cap.step, cap.stl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]
2026-09-30 Portrait assembly animation ending on the USB-C port, threaded screws
    - Camera: the same 90 deg orbit, now ending 15 deg off the port axis
    (taken from layout.json), so the waterproof USB-C port is the final
    shot; the lights ride on the camera rig so the port side is lit.
    - 1080 x 1920 portrait, 512 samples (was 1920 x 1080, 128), movie encoded
    perceptually lossless.
    - Screws: M2 x 0.4 cheese heads with a Torx T6 recess and chamfered edge
    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
    [shotpuck_assembly.blend]
2026-09-30 Replace cap gasket with retained O-ring seals
    Step the SLA cap wall so a 37 x 1.0 O-ring stretches onto a ledge and is
    squeezed 25 % against the flat plate. Stop the bosses 0.65 mm above the
    PCB so a 2 x 1.0 O-ring on each M2 screw clamps the board and keeps the
    screws captive. The animation carries both O-rings with the cap.
    [assembly.step, cap.step, cap.stl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]
2026-09-30 Re-render the assembly with the O-ring seals; clear stale frames
    render_assembly.py fingerprints the scene inputs (layout.json, STLs,
    board, 3D models, Blender scripts) and deletes existing frames when they
    no longer match, so a design change can no longer re-encode an old
    render. An interrupted render still resumes.
    [shotpuck_assembly.blend]
2026-09-30 Add charger LED, JP2 reset pads and firmware recovery (0.2.1)
    Charger LED: one blink every 2 s while charging, steady once the charger
    has terminated (so the LED never holds off termination), three blinks
    when the temperature gate pauses charging.
    JP2: two bare round pads (0.8 mm, 0.4 mm gap) on module pin 7 (P0.26)
    and GND. With the cap off, bridging them for 5 s erases settings,
    pairings, shot count and log and reboots; only a bridge made while
    running counts. Three crash or watchdog resets in a row, each within a
    minute of boot, erase the same data automatically. A trial OTA image is
    now confirmed only after a paired phone connects over an encrypted link.
    Firmware rebuilt and signed as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
    [shotpuck-panel-B_Cu.gbl, shotpuck-panel-B_Mask.gbs, shotpuck-panel-B_Paste.gbp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]
2026-09-30 Loose bolt tube under a cap lip, plate drawing, refreshed panel gerbers
    Port main's loose-tube change (README D21) to the USB-C cap: the tube stands
    on the plate and its top end sits in a ring lip under the cap top; the bolt
    passes the cap top through a 8.4 mm hole. Tube 6.7 mm, puck 15.86 g. The
    Blender bolt now sits on the cap top and the tube drops onto the plate.
    Add mechanical/plate_drawing.py -> out/plate_drawing.pdf: hole table and the
    M2x0.4 tapped-through callout for the plate order.
    Regenerate the panel, its gerbers and the JLC BOM/CPL after the silkscreen
    edit (panel DRC: 0 violations, 0 unconnected; BOM and CPL unchanged).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
    [assembly.step, cap.step, cap.stl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]
2026-09-30 Loose bolt tube trapped under a cap lip (magnetic-connector board)
    The tube was bonded into the cap 0.1 mm proud and could fall out once the
    glue let go. It now stands loose on the plate with its top end in a ring lip
    under the cap top; the bolt passes the cap top through a 8.4 mm hole, so the
    PC cap top is in the clamp path (README D21, VALIDATION section 2).
    Last state of the magnetic-connector board before the USB-C board replaces
    it on main.
    [assembly.step, cap.step, cap.stl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]
2026-09-30 Document the USB-C board as the baseline
    Fold HANDOVER section 0 (the alt/usb-c-side notes) into the body: USB-C port,
    module and keep-outs, J2/JP2 pads, screw positions, cap port, O-ring seals,
    panel and plate drawing. README decisions D17-D29, fabrication and assembly
    now describe the USB-C board, with the magnetic connector as D18's
    alternative (last state 01f2e00). VALIDATION replaces the magnetic-connector
    checks with USB-C, O-ring and sealing checks, and marks the results that
    were measured on the magnetic board.
2026-10-01 Update ShotPuck specifications and design files for USB-C integration
    - Adjusted dimensions: puck diameter increased to Ø40 × 10.43 mm, with 1.6 mm free space above the cell.
    - Updated IMU to ST LSM6DSO32XTR, reflecting changes in the BOM and design files.
    - Revised PCB thickness from 0.8 mm to 1.2 mm, ensuring compatibility with new components.
    - Enhanced layout.json and README.md to reflect the latest design specifications and assembly details.
    - Removed obsolete components and updated the BOM for JLCPCB assembly.
    - Regenerated fabrication files, including gerbers and BOM, to align with the latest design changes.
    [assembly.step, cap.step, cap.stl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]
2026-10-01 Update HANDOVER and README for recent design changes
    - Enhanced J1's wing-tab pads for USB-C, increasing their area for better soldering.
    - Adjusted D3's orientation in the CPL to match JLC's numbering.
    - Added order package details in README for JLCPCB, including ORDER.md for order settings and checks.
    - Regenerated fabrication files to reflect the latest design updates.
    [shotpuck-B_Cu.gbl, shotpuck-B_Mask.gbs, shotpuck-B_Paste.gbp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]
2026-10-01 Update HANDOVER and README with design adjustments and fixes
    - Adjusted panel fiducial positions and tooling hole sizes to meet JLCPCB specifications.
    - Moved U2 and associated components inward for better clearance from the top tab.
    - Fixed outline slivers in the panel design to resolve DRC issues, ensuring all runs pass.
    - Regenerated fabrication files, including updated gerbers and BOM, to reflect the latest changes.
    [shotpuck-B_Cu.gbl, shotpuck-B_Mask.gbs, shotpuck-B_Paste.gbp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]
2026-10-01 Update README and fabrication files for panel adjustments
    - Modified drill export commands in README to include map generation for JLCPCB requirements.
    - Updated README to clarify the drill map inclusion and fabrication process.
    - Regenerated fabrication files, including updated gerbers and drill files, to reflect the latest design changes.
    [shotpuck-NPTH-drl_map.gbr, shotpuck-PTH-drl_map.gbr, shotpuck-panel-B_Cu.gbl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]
2026-10-01 Update ORDER.md and subproject history for ShotPuck design adjustments
    - Updated ORDER.md to reflect the latest commit reference and included changes from the 2026-10-01 updates.
    - Adjusted descriptions for the USB-C board to clarify the integration of recent fabrication fixes and design changes.
    - Updated subproject history to indicate the new commit state.
2026-10-01 Update .gitignore and subproject history for hardware changes
    - Added .history file to .gitignore to prevent tracking of history changes in KiCad.
    - Updated subproject commit reference to indicate a dirty state in the hardware directory.
2026-10-01 Switch U2 to LSM6DSV32XTR and assemble 4 boards
    - U2 is the LSM6DSV32XTR (C22461202): same pinout and land pattern, JLC
    footprint within 0.013 mm at 0 deg. Value fields, BOMs, pos file and
    schematic PDF updated; gerbers, drill files and CPL rows unchanged.
    Board DRC 0/0 with 0 parity issues, panel DRC 0/0, ERC unchanged.
    - Firmware 0.2.2: accel.c ported to the LSM6DSV32X register map. ACTIVE
    runs at 480 Hz (captures 720 samples, ring 1329, motion guard 10
    samples), IDLE at 15 Hz. Rebuilt shotpuck_full.hex and update.bin.
    - Sim ground truth 3360 Hz (7 x 480 Hz); results.txt regenerated, PASS.
    - JLC order: PCBA qty 2 panels, BOM/CPL for the bottom-row copies only
    (gen_jlc.py ASSEMB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
2026-10-12 Feed R9 from VIN_RAW and add the hot-plug simulation
    A hot-plug simulation of the charge input (324 cases over cable,
    supply, C1 derating, D1 and TVS corners) showed that D1 and C1 hold a
    plug-in overshoot on VIN for milliseconds, and R9/C9 passes it on to
    the nRF VBUS pin: up to 6.36 V against its 5.8 V absolute maximum in
    9 cases. Fed from VIN_RAW, before D1, VBUS_SNS stays at or below
    5.47 V in every case, and charger detection gains a diode drop of
    headroom. R9 sat on VIN only because the magnetic board's hand-wired
    lead could be reversed; a USB-C plug cannot reverse VBUS.
    - design.py: R9 pin 1 on VIN_RAW.
    - shotpuck.kicad_sch: R9 pin-1 label changed in place (gen_sch.py
    would drop th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
2026-10-12 Add the ShotPuck mini board (future project)
    A 33 x 33 mm square board for a Picatinny-rail case: BMD-340 in normal
    voltage mode, the same IMU, and a CR2450 under a MYOUNG MY-2450-03
    holder on the back (hand-soldered, not in the JLC files). Richard
    places and routes it by hand; gen_mini_pcb.py never overwrites it.
    It is a possible future project and not part of the rev A order.
    - design_mini.py, gen_mini_pcb.py and the shotpuck-mini KiCad project.
    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
2026-10-12 Widen the cap's seal band to 0.8 mm and switch to brass standoffs
    JLC3DP flagged the cap's 0.40 mm seal band (the inner step of the
    bottom rim) on the rev A 3D-print order. The band is now 0.80 mm
    (seal.band_wall), JLC3DP's SLA minimum: it grows inward to 36.2 mm,
    rises 0.6 mm inside the cavity and chamfers back to the wall, with
    five round gaps at the standoffs and the cell. The O-ring ledge and
    squeeze are unchanged. The new cap.step/stl replaced the file in the
    JLC3DP order; the first upload is kept in original_0.40mm_band/
    (identical to the previously committed files).
    The standoffs are now ORANXIN M2x3+3 brass male-female hex standoffs
    (ordered), screwed into the tapped plate with thei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
2026-10-12 Record the rev A order as placed and paid
    The PCB with PCBA on 2 panels (4 assembled boards) and the cap were
    ordered from shotpuck-order-2026-09-30.zip and paid in full on
    2026-10-12 ($217.63, shipped DHL Express because Global Standard
    Direct Line was not offered, so VAT is charged on delivery). JLC
    support confirmed that C5456944 is BMD-340-A-R-10, and JLC's BOM
    matches shotpuck-panel-bom.csv line for line. The base plate is not
    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
2026-10-20 Replace the rev 0A BOM and CPL for whole panels
    JLC does not assemble part of a panel, so the PCBA order now assembles
    all four boards of each panel (8 boards). U4 is BQ29700DSET (C2876282)
    because the DSER was short; same part and footprint, CPL unchanged.
2026-10-20 Assemble whole panels and order U4 as BQ29700DSET
    JLC does not assemble part of a panel, so gen_jlc.py covers all four
    copies again (112 placements, 8 boards for PCBA qty 2). U4 maps to
    C2876282, the same part and JLC footprint as the out-of-stock DSER.
    The CPL is identical to the rev 0A replacement.
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2026-11-09 Firmware 0.3.0: compressed captures in flash and extended capture mode
    - Added a lossless capture codec (capcodec/capdec): 32-sample blocks, per-axis delta or slope prediction with Rice coding, raw fallback.
    - Added capstore, a flash ring of variable-length compressed captures on a new 408 KB capture_partition (CRC commit, torn-write safe, RAM index of 256), bound to Zephyr's flash_area by capflash.
    - capwriter compresses each accepted shot's window from the 10 s sample ring while the post-trigger part arrives; capture_tx streams CAPTURE from flash, decoding on the fly, so GET_CAPTURE works for any stored shot and after a reset.
    - CONFIG v3 adds capture_mode: standard (-1.0..+0.5 s) or exten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
2026-11-09 Firmware 0.3.1: review fixes, auto-pairing marker, crash diagnostics, smaller image
    Review stages 1-5 on top of 0.3.0 (BLE protocol still v3):
    - Capture writer aborts a record whose final flash write fails; the capture
    boot scan rescans the sector after a bad record
    - t_unix_ms from 64-bit uptime; seq never goes backwards, also across a
    factory reset; the pad reset also erases captures
    - IMU bus recovery, retry while missing and health check; low-battery
    cut-off after 3 readings; SAADC offset calibration
    - Non-blocking LED sequencer; 8 ATT TX buffers; a full CONTROL queue
    answers ATT 0x11; CONFIG through a message queue
    - Pairing marker in the advertising data while the pairing windo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
2026-11-09 Firmware 0.3.1: 2 KB system work queue stack
    0.3.0 on board 1 lost the link about 2 s after a bonded phone changed its
    subscriptions, in every archesk sync session. Zephyr stores changed CCCs
    1 s after the write in delayed_store on the system work queue; that path
    needs 1,048-1,200 B (GCC stack usage), more than the 1,024 B queue. The
    stack guard turned the overflow into a fatal error, 0.3.0 halted with the
    radio off, and the watchdog reset the puck about 10 s later.
    CONFIG_SYSTEM_WORKQUEUE_STACK_SIZE=2048 (RAM +1 KB, flash unchanged).
    Release files regenerated: shotpuck_update.bin sha256
    0132fd93a1653cff6619abcaa2082631bb3eea1542aa1fbd396ecf9296ffbe5a; the
    file from 4eeb809 must not be pub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
